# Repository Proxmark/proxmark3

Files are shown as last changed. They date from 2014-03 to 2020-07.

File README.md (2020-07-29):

# proxmark3: the official Proxmark repository!

The proxmark3 is a powerful general purpose RFID tool, the size of a deck
of cards, designed to snoop, listen and emulate everything from
**Low Frequency (125kHz)** to **High Frequency (13.56MHz)** tags.

This repository contains enough software, logic (for the FPGA), and design
documentation for the hardware that you could, at least in theory,
do something useful with a proxmark3.

## Resources

* [This repository!](https://github.com/Proxmark/proxmark3)
* [The Wiki](https://github.com/Proxmark/proxmark3/wiki)
* [The GitHub Pages website](http://proxmark.github.io/proxmark3/)
* [The Forum](http://www.proxmark.org/forum)
* The IRC channel: irc.freenode.org #proxmark3 ([chat in your browser](http://webchat.freenode.net/?channels=#proxmark3))
* [The Homebrew formula repository](https://github.com/Proxmark/homebrew-proxmark3)
* [Proxmark3 community discord server](https://discord.gg/86VcRtS)
   
## Development

The tools required to build  or run the project will vary depending on
your operating system. Please refer to [the wiki](https://github.com/Proxmark/proxmark3/wiki) for details.

## Obtaining hardware

The Proxmark3 is available for purchase (assembled and tested) from the
following locations:

| Distributor Name | Warehouse Location | Entity Location |
|---|---|---|
| [RyscCorp](https://proxmark3.com/) | USA | USA |
| [Hackerwarehouse](https://hackerwarehouse.com/)  | USA | USA |
| [Elechouse](http://www.elechouse.com/) | HK | HK |
| [Lab401](https://lab401.com/) | EU | HK |
| [RFxSecure](http://www.rfxsecure.com/) | CN | SG |
| [Sneaktechnology](https://www.sneaktechnology.com/)  | CN | CN |

Most of the ultra-low-volume contract assemblers could put
something like this together with a reasonable yield. A run of around
a dozen units is probably cost-effective. The BOM includes (possibly-
outdated) component pricing, and everything is available from Digikey
and the usual distributors.

If you've never assembled a modern circuit board by hand, then this is
not a good place to start. Some of the components (e.g. the crystals)
must not be assembled with a soldering iron, and require hot air.

The schematics are included; the component values given are not
necessarily correct for all situations, but it should be possible to do
nearly anything you would want with appropriate population options.

The printed circuit board artwork is also available, as Gerbers and an
Excellon drill file.

## License

This program is free software; you can redistribute it and/or modify
it under the terms of the GNU General Public License as published by
the Free Software Foundation; either version 2 of the License, or
(at your option) any later version.

This program is distributed in the hope that it will be useful,
but WITHOUT ANY WARRANTY; without even the implied warranty of
MERCHANTABILITY or FITNESS FOR A PARTICULAR PURPOSE.  See the
GNU General Public License for more details.

You should have received a copy of the GNU General Public License
along with this program; if not, write to the Free Software
Foundation, Inc., 51 Franklin St, Fifth Floor, Boston, MA  02110-1301  USA

Jonathan Westhues
user jwesthues, at host cq.cx

May 2007, Cambridge MA

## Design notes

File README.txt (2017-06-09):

NOTICE:
(2014-03-26)
This is now the official Proxmark repository!

INTRODUCTION:

The proxmark3 is a powerful general purpose RFID tool, the size of a deck
of cards, designed to snoop, listen and emulate everything from
Low Frequency (125kHz) to High Frequency (13.56MHz) tags.

This repository contains enough software, logic (for the FPGA), and design
documentation for the hardware that you could, at least in theory,
do something useful with a proxmark3.

RESOURCES:

   * This repository!
      https://github.com/Proxmark/proxmark3
      
   * The Wiki
      https://github.com/Proxmark/proxmark3/wiki
      
   * The GitHub page
      http://proxmark.github.io/proxmark3/
      
   * The Forum
      http://www.proxmark.org/forum
      
   * The IRC chanel
       irc.freenode.org #proxmark3
       -or-
       http://webchat.freenode.net/?channels=#proxmark3
       
   * The Homebrew formula repository
      https://github.com/Proxmark/homebrew-proxmark3
   
DEVELOPMENT:

The tools required to build  or run the project will vary depending on
your operating system. Please refer to the Wiki for details.

   * https://github.com/Proxmark/proxmark3/wiki

OBTAINING HARDWARE:

The Proxmark3 is available for purchase (assembled and tested) from the
following locations:

   * https://proxmark3.com/  - RyscCorp (us)
   * http://www.elechouse.com/  - Elechouse (HK)
   * https://lab401.com/ - Lab401 (FR)
   * http://www.rfxsecure.com/  - RFxSecure (SG)
   * http://proxmark3.tictail.com/ - IceSQL (SE)
   
Most of the ultra-low-volume contract assemblers could put
something like this together with a reasonable yield. A run of around
a dozen units is probably cost-effective. The BOM includes (possibly-
outdated) component pricing, and everything is available from Digikey
and the usual distributors.

If you've never assembled a modern circuit board by hand, then this is
not a good place to start. Some of the components (e.g. the crystals)
must not be assembled with a soldering iron, and require hot air.

The schematics are included; the component values given are not
necessarily correct for all situations, but it should be possible to do
nearly anything you would want with appropriate population options.

The printed circuit board artwork is also available, as Gerbers and an
Excellon drill file.

LICENSING:

This program is free software; you can redistribute it and/or modify
it under the terms of the GNU General Public License as published by
the Free Software Foundation; either version 2 of the License, or
(at your option) any later version.

This program is distributed in the hope that it will be useful,
but WITHOUT ANY WARRANTY; without even the implied warranty of
MERCHANTABILITY or FITNESS FOR A PARTICULAR PURPOSE.  See the
GNU General Public License for more details.

You should have received a copy of the GNU General Public License
along with this program; if not, write to the Free Software
Foundation, Inc., 51 Franklin St, Fifth Floor, Boston, MA  02110-1301  USA

Jonathan Westhues
user jwesthues, at host cq.cx

May 2007, Cambridge MA

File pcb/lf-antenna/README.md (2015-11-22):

LF antenna CAD / CAM / MFG files. Put here as it was in the original zip file too. Didn't modified the layout file, only CAM generation.

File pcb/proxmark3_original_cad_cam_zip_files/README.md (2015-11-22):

These files are downloaded from here: http://cq.cx/proxmark3.pl

These are the original, non-modified parts. 

What I've noticed that there are problems with the stop mask layers (via and component silkscreen print) This is what I'm going to modify in my cad / cam version.

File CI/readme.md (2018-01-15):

# How to configure continuous integration

Here 2 CI configuration files:

1. for [travis](travis-ci.org)
2. for [appveyor](appveyor.com)

It needs to put files from this directory to repository root and then configure CI from appropriate WEB portal.

## travis

- Copy .travis.yml and travis_test_commands.scr files to repository root 
- Configure CI from http://travis-ci.org
- It needs to fork https://github.com/Proxmark/homebrew-proxmark3 from your proxmark repository home
- Put to file `proxmark3.rb` in line `head "https://github.com/proxmark/proxmark3.git"` your repository link. As sample: `head "https://github.com/merlokk/proxmark3.git"`

## appveyor

- Just copy appveyor.yml file to root and configure it from http://appveyor.com

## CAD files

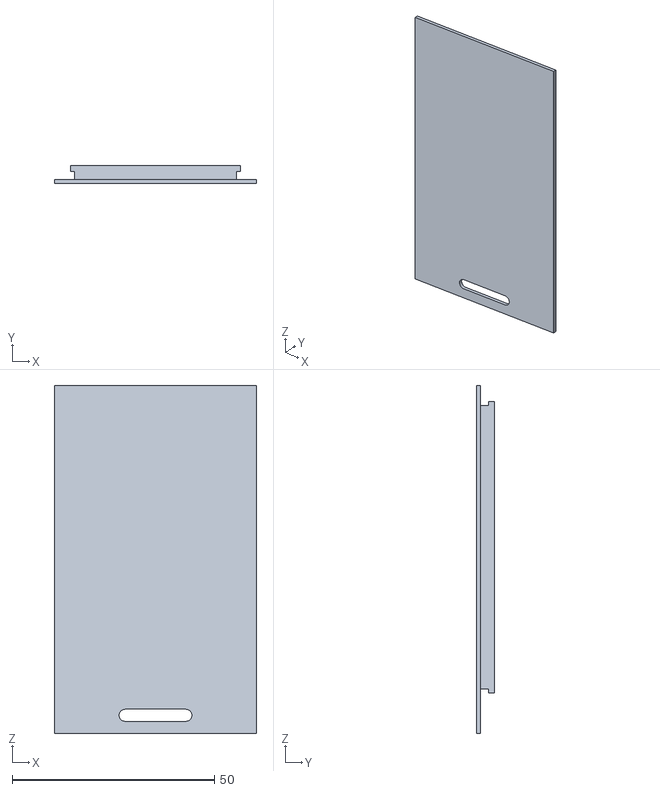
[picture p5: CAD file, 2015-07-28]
doc/RFID_Antenna-With-Lanyard-Hook.stl
50.0 x 4.50 x 86.0

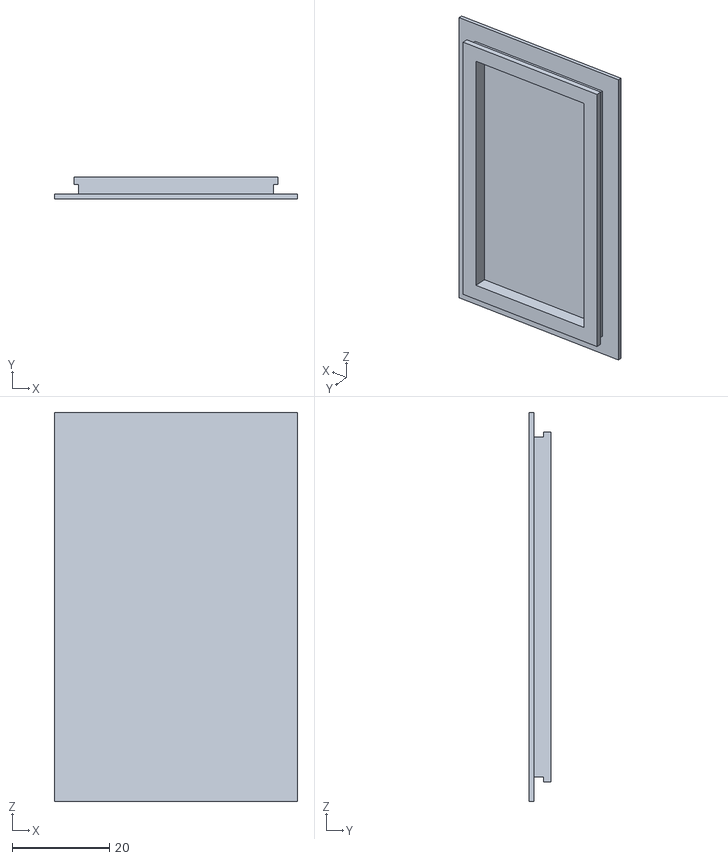
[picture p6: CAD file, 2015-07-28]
doc/RFID_Antenna-Basic-Form.stl
50.0 x 4.50 x 80.0

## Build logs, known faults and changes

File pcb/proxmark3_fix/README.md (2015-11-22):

Corrected Eagle layout files and re-generated CAM files. DRC checked (via eurocircuits.com 's PCB visualizer too) no problems found, ready to production!

Please find the change list in the CAD folder text file.

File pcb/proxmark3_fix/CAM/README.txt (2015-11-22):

project: proxmark3-00

    * please make 18 boards
    * panelize 3x1 (for total 6 panels)
    * 0.062" finished thickness
    * FR-4
    * solder mask top and bottom
    * silkscreen legend top
    * either 1 ounce or 0.5 ounce copper acceptable (1 ounce preferred)

Layer stackup:

Top layer: *.GTL
Inner Layer 1: *.GL1 (for 4-layer board)
Inner Layer 2: *.GL2 (for 4-layer board)
Bottom layer: *.GBL
Solder Stop Mask top: *.GTS
Solder Stop Mask Bottom: *.GBS
Silk Top: *.GTO
Silk Bottom: *.GBO
NC Drill: *.TXT
Outline layer: *.GKO or *.DO

Note:
 All the gerber files in RS-274x format, except the drill file in Excellon format. 

Ship to

<my shipping address>

<my email address>

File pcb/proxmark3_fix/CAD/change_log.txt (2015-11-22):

13/11/2015 Change list from original PCB:

Main problem: more then 800 DRC errors when runing that in Eagle. Check out the following changes to make a more reliable PCB. Those are minor cosmetic changes, but ease your life to avoid short circuit.

1. Eagle Layout / DRC rules / Masks / Limit: from 0mil to 16mil, thus ordinary GND and signal vias which smaller then 16mil wont be open at solder stop mask layer.

2. Eagle Layout / DRC rules / Masks / Stop MAX: from 2mil to 0, this way the solder stop mask wont overlap silkscreen drawings. Also as per PCB assembly houses, it's recommended, they set their own scaling for production.

3. Exporting all the parts in the proxmark3 Eagle Layout into a library for minor silkscreen edition: proxmark3_components  merged.lbr
	- Editing components footprint as was overlapping with top stop mask

4. Adding top, bottom, in1, in2 layer markings in PCB layout for better manufacturing identification	

5. Generating 4 layer CAM files

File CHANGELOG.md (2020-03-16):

# Change Log
All notable changes to this project will be documented in this file.
This project uses the changelog in accordance with [keepchangelog](http://keepachangelog.com/). Please use this to write notable changes, which is not the same as git commit log...

## [unreleased][unreleased]

### Changed
- Changed hf mfp security. Now it works in all the modes. (drHatson)
- `hf fido` - show/check DER certificate and signatures (Merlok)
- Changed `lf hitag reader 0x ... <firstPage> <tagmode>` - to select first page to read and tagmode (0=STANDARD, 1=ADVANCED, 2=FAST_ADVANCED)
- Accept hitagS con0 tags with memory bits set to 11 and handle like 2048 tag

### Fixed
- AC-Mode decoding for HitagS
- Wrong UID at HitagS simulation
- `hf 15 sim` now works as expected (piwi)
- `hf mf chk t` save to emulator memory now works as expected (mwalker)
- Fix `hf mf sim` - wrong access rights to write key B in trailer (@McEloff)
- allow files > 512Bytes in 'hf iclass eload' (@Sherhannn79)
- `hf mf nested` now works with fixed nonce tags too (uzlonewolf, piwi)
 
### Added
- Added to `hf 14a apdu` print apdu and compose apdu (@merlokk)
- Added `hf 15 csetuid` - set UID on ISO-15693 Magic tags (t0m4)
- Added `lf config s xxxx` option to allow skipping x samples before capture (marshmellow)
- Added `lf em 4x05protect` to support changing protection blocks on em4x05 chips (marshmellow)
- Support Standard Communication Mode in HITAG S
- Added `hf emv scan` - commands for scan EMV card and dump data to json file (Merlok)
- `hf mfp` group of commands (Merlok)
- Added `hf fido` - FIDO U2F authenticator commands https://fidoalliance.org/ (Merlok)
- Added `lf hitag reader 03` - read block (instead of pages) 
- Added `lf hitag reader 04` - read block (instead of pages) 
- Added `hf fido` `assert` and `make` commands from fido2 protocol (authenticatorMakeCredential and authenticatorGetAssertion) (Merlok)
- Added `lf paradox clone` to clone a Paradox card
- Added `emv` commands working for both contactless and smart cards (Merlok)
- Added `hf 15 snoop` (piwi)
- Added support for standard USB Smartcard Readers (piwi)
- Added `hf plot` (piwi)
- Added `hf mfp mad` `hf mf mad` parsing MAD1 and MAD2 (Merlok)
- Added `hf mfp ndef` `hf mf ndef` parsing NDEF records (Merlok)
- Added Mifare Mini, Mifare 2K and 4K support to `hf mf sim` (piwi)
- Added Legic detection to `hf search` (dnet)
- Added Home (Pos1) and End key bindings to the plot GUI (based on @mcd1992)
- Added downlink reference mode option r <mode> [ 0 - (or missing) default/fixed bit, 1 - long leading, 2 - leading 0 and 3 - 1 of 4 ] to `lf t55xx detect`, `lf t55xx read`, `lf t55xx write`, and `lf t55xx bruteforce`
- Added special option `r 4` to bruteforce, to try all downlink modes (0,1,2 and 3) for each password
- `hf mfu info` now checks the NXP Originality Signature if availabe (piwi)
- Added `hf mf personalize` to personalize the UID option of Mifare Classic EV1 cards (piwi)

## [v3.1.0][2018-10-10]

### Changed
- Adjusted `lf cmdread` to respond to client when complete and the client will then automatically call `data samples`
- Improved backdoor detection misbehaving magic s50/1k tag (Fl0-0)
- Deleted wipe functionality from `hf mf csetuid` (Merlok)
- Changed `hf mf nested` logic (Merlok)
- Added `hf mf nested` mode: autosearch keys for attack (from well known keys) (Merlok)
- `hf mf nested` Check keys after they have found (Merlok)
- `hf mf chk` Move main cycle to arm (Merlok)
- Changed proxmark command line parameter `flush` to `-f` or `-flush` (Merlok)
- Changed `hf 14a reader` to just request-anticolission-select sequence (Merlok)
- Changed `hf 14a raw` - works with LED's and some exchange logic (Merlok)
- Changed TLV parser messages to more convenient (Merlok)
- Rewritten Legic Prime reader (`hf legic reader`, `write` and `fill`) - it is using xcorrelation now (AntiCat)
- `hf 14a` commands works via argtable3 commandline parsing library (Merlok)
- HID LF operations on firmware updated for complete native support of long (>37 bit) HID tags (grauerfuchs)
- Changed Legic Prime tag simulator (`hf legic sim`) to run from 212 kHz SSP clock for better reliability (AntiCat)

### Fixed
- Changed start sequence in Qt mode (fix: short commands hangs main Qt thread) (Merlok)
- Changed driver file proxmark3.inf to support both old and new Product/Vendor IDs (piwi)
- Changed all command line parsers in `hf emv` commands to argtable (Merlok)
- Implemented AppNap API, fixing #283 and #627 OSX USB comm issues (AntiCat)

### Added
- Added `sc` smartcard (contact card) commands - reader, info, raw, upgrade, setclock, list (hardware version RDV4.0 only) must turn option on in makefile options (Willok, Iceman, marshmellow)
- Added a bitbang mode to `lf cmdread` if delay is 0 the cmd bits turn off and on the antenna with 0 and 1 respectively (marshmellow)
- Added PAC/Stanley detection to lf search (marshmellow)
- Added lf pac demod and lf pac read - extracts the raw blocks from a PAC/Stanley tag (marshmellow)
- Added hf mf c* commands compatibility for 4k and gen1b backdoor (Fl0-0)
- Added backdoor detection for gen1b magic s70/4k tag (Fl0-0)
- Added data fsktonrz, a fsk cleaning/demodulating routine for weak fsk signal. Note: follow this up with a `data rawdemod nr` to finish demoding your signal. (marshmellow)
- Added lf em 410xbrute, LF EM410x reader bruteforce attack by simulating UIDs from a file (Fl0-0)
- Added `hf mf cwipe` command. It wipes "magic Chinese" card. For 1a generation it uses card's "wipe" command. For gen1a and gen1b it uses a write command. (Merlok)
- Added to `hf mf nested` source key check before attack (Merlok)
- Added to `hf mf nested` after attack it checks all found keys on non-open sectors (Merlok)
- `hf mf chk` Added settings to set iso14443a operations timeout. default timeout set to 500us (Merlok)
- Added to `hf mf nested` parameters `s` and `ss` for checking slow cards (Merlok)
- Added to proxmark command line parameters `w` - wait 20s for serial port (Merlok)
- Added to proxmark command line parameters `c` and `l` - execute command and lua script from command line (Merlok)
- Added to proxmark ability to execute commands from stdin (pipe) (Merlok)
- Added `hf 14a info` and moved there functionality from `hf 14a reader` (Merlok)
- Added to `hf 14a info` detection of weak prng from Iceman1001 fork (Merlok)
- Added to `hf 14a apdu` - exchange apdu via iso1443-4 (Merlok)
- Added to `hf 14a apdu` - apdu and tlv results parser (Merlok)
- Added `hf emv` group of commands (Merlok)
- Added `hf emv search` `hf emv pse` - commands for selection of EMV application (Merlok)
- Added `hf emv select` - command for select EMV application (Merlok)
- Added `hf emv exec` - command for execute EMV transaction (Merlok)
- Added to `hf emv exec` MSD path for VISA and Mastercard and some other compatible EMV cards (Merlok)
- Added to `hf emv exec` SDA, DDA, fast DDA, CDA calculations for VISA and Mastercard and some other compatible EMV cards (Merlok)
- Added `hf emv test` - crypto tests for DES, AES, SHA, RSA, SDA, DDA, CDA and some other crypto functions (Merlok)
- Added `hf list mf` - deciphers crypto1 stream and works with first authentication and weak nested authentications (Merlok)
- Added to `hf emv` commands: `gpo`, `readrec`, `genac`, `challenge`, `intauth` - commands working with EMV cards (Merlok)
- Added `lf hid encode` and `lf hid decode` commands to translate printed HID card data to and from the packed data transmitted by a prox tag (grauerfuchs)
- Added `lf hid write` command, which operates as a macro for encode followed by clone operations (grauerfuchs)

## [3.0.1][2017-06-08]

### Fixed
- Compiles on OS X
- Compiles with gcc 4.9
- Compiles for non-Intel CPUs

## [3.0.0][2017-06-05]

### Added
- Added lf hitag write 24, the command writes a block to hitag2 tags in crypto mode (henjo)

### Added
- Added hf mf hardnested, an attack working for hardened Mifare cards (EV1, Mifare Plus SL1) where hf mf nested fails (piwi)
- Added experimental testmode write option for t55xx (danger) (marshmellow)
- Added t55xx p1detect to `lf search` chip detections (marshmellow)
- Added lf t55xx p1detect, detect page 1 of a t55xx tag based on E015 mfg code (marshmellow)
- Added lf noralsy demod, read, clone, sim commands (iceman)
- Added lf jablotron demod, read, clone, sim commands (iceman)
- Added lf nexwatch read   - reads a nexwatch tag from the antenna
- Added lf paradox read    - reads a paradox tag from the antenna
- Added lf fdx sim (iceman)
- Added lf fdx clone       - clones an fdx-b animal tag to t55x7 or q5 (iceman)
- Added lf fdx read        - reads a fdx-b tag from the antenna (iceman)
- Added lf gproxii read    - reads a gproxii tag from the antenna (marshmellow)
- Added lf indala read     - reads an indala tag from the antenna (marshmellow)
- Added lf visa2000 demod, read, clone, sim commands (iceman)
- Added markers in the graph around found Sequence Terminator after askmandemod.
- Added data mtrim <start> <stop> command to trim out samples between start and stop
- Added data setgraphmarkers <orange> <blue> command to set two extra markers on the graph (marshmellow)
- Added EM4x05/EM4x69 chip detection to lf search (marshmellow) 
- Added lf em 4x05dump command to read and output all the blocks of the chip (marshmellow)
- Added lf em 4x05info command to read and display information about the chip (marshmellow)
- Added lf cotag read, and added it to lf search (iceman)
- Added hitag2 read UID only and added that to lf search (marshmellow)
- Added lf pyramid commands (iceman)
- Added lf presco commands - some bits not fully understood... (iceman)
- Added experimental HitagS support (Oguzhan Cicek, Hendrik Schwartke, Ralf Spenneberg)
  see https://media.ccc.de/v/32c3-7166-sicherheit_von_125khz_transpondern_am_beispiel_hitag_s
  English video available
- Added a LF ASK Sequence Terminator detection option to the standard ask demod - and applied it to `lf search u`, `lf t55xx detect`, and `data rawdemod am s` (marshmellow)
- `lf t55xx bruteforce <start password> <end password> [i <*.dic>]` - Simple bruteforce attack to find password - (iceman and others)
- `lf viking clone`- clone viking tag to t55x7 or Q5 from 4byte hex ID input 
- `lf viking sim`  - sim full viking tag from 4byte hex ID input
- `lf viking read` - read viking tag and output ID
- `lf t55xx wipe`  - sets t55xx back to factory defaults
- Added viking demod to `lf search` (marshmellow)
- `lf viking demod` demod viking id tag from graphbuffer (marshmellow)
- `lf t55xx resetread` added reset then read command - should allow determining start of stream transmissions (marshmellow)
- `lf t55xx wakeup` added wake with password (AOR) to allow lf search or standard lf read after (iceman, marshmellow)
- `hf iclass managekeys` to save, load and manage iclass keys.  (adjusted most commands to accept a loaded key in memory) (marshmellow)
- `hf iclass readblk` to select, authenticate, and read 1 block from an iclass card (marshmellow)
- `hf iclass writeblk` to select, authenticate, and write 1 block to an iclass card (or picopass) (marshmellow + others)
- `hf iclass clone` to take a saved dump file and clone selected blocks to a new tag (marshmellow + others)
- `hf iclass calcnewkey` - to calculate the div_key change to change a key - (experimental) (marshmellow + others)
- `hf iclass encryptblk` - to encrypt a data block hex to prep for writing that block (marshmellow)
- ISO14443a stand-alone operation with ARM CFLAG="WITH_ISO14443a_StandAlone". This code can read & emulate two banks of 14a tag UIDs and write to "magic" cards  (Craig Young) 
- AWID26 command context added as 'lf awid' containing realtime demodulation as well as cloning/simulation based on tag numbers (Craig Young)
- Added 'hw status'. This command makes the ARM print out some runtime information. (holiman) 
- Added 'hw ping'. This command just sends a usb packets and checks if the pm3 is responsive. Can be used to abort certain operations which supports abort over usb. (holiman)
- Added `data hex2bin` and `data bin2hex` for command line conversion between binary and hexadecimal (holiman)
- Added 'hf snoop'. This command take digitalized signal from FPGA and put in BigBuffer. (pwpiwi + enio)
- Added Topaz (NFC type 1) protocol support ('hf topaz reader', 'hf list topaz', 'hf 14a raw -T', 'hf topaz snoop'). (piwi)
- Added option c to 'hf list' (mark CRC bytes) (piwi)

### Changed
- Adjusted the lf demods to auto align and set the grid for the graph plot. 
- `lf snoop` now automatically gets samples from the device
- `lf read` now accepts [#samples] as arg. && now automatically gets samples from the device
- adjusted lf t5 chip timings to use WaitUS. and adjusted the readblock timings
    appears to have more consistent results with more antennas.
- `lf t5 wakeup` has been adjusted to not need the p in front of the pwd arg.
- `data psknexwatchdemod` has been moved to `lf nexwatch demod` (reads from graphbuffer)
- `data fskparadoxdemod` has been moved to `lf paradox demod` (reads from graphbuffer)
- `data fdxdemod` has been moved to `lf fdx demod` (reads from graphbuffer)
- `data askgproxiidemod has been moved to `lf gproxii demod` (reads from graphbuffer)
- `lf indalaclone` has been moved to `lf indala clone`
- `lf indalademod` has been moved to `lf indala altdemod` (reads from graphbuffer)
- `data pskindalademod` has been moved to `lf indala demod` (reads from graphbuffer)
- `data askvikingdemod` has been moved to `lf viking demod` (reads from graphbuffer)
- `data fskpyramiddemod` has been moved to `lf pyramid demod` (reads from graphbuffer)
- `data fskiodemod` has been moved to `lf io demod` (reads from graphbuffer)
- `lf io fskdemod` has been renamed to `lf io read` (reads from antenna)
- `data fskawiddemod` has been moved to `lf awid demod` (reads from graphbuffer)
- `lf awid fskdemod` has been renamed to `lf awid read` (reads from antenna)
- `data fskhiddemod` has been moved to `lf hid demod` (reads from graphbuffer)
- `lf hid demod` has been renamed to `lf hid read` (reads from antenna)
- all em410x demod and print functions moved to cmdlfem4x.c
- `data askem410xdemod` has been moved to `lf em 410xdemod` (reads from graphbuffer)
- `lf em 410xdemod` has been renamed to `lf em 410xread` (reads from antenna)
- hf mf dump - added retry loops to try each read attempt up to 3 times.  makes getting a complete dump easier with many antennas. 
- small changes to lf psk and fsk demods to improve results when the trace begins with noise or the chip isn't broadcasting yet (marshmellow)
- NOTE CHANGED ALL `lf em4x em*` cmds to simpler `lf em ` - example: `lf em4x em410xdemod` is now `lf em 410xdemod`
- Renamed and rebuilt `lf em readword` && readwordpwd to `lf em 4x05readword` - it now demods and outputs the read block (marshmellow/iceman)
- Renamed and rebuilt `lf em writeword` && writewordpwd to `lf em 4x05writeword` - it now also reads validation output from the tag (marshmellow/iceman)
- Fixed bug in lf sim and continuous demods not turning off antenna when finished
- Fixed bug(s) in hf iclass write
- Fixed bug in lf biphase sim - `lf simask b` (and any tagtype that relies on it - gproxii...) (marshmellow)
- Fixed bug in lf viking clone/sim (iceman)
- Fixed broken `data askedgedetect` (marshmellow)
- Adjusted hf mf sim command (marshmellow)
    added auto run mfkey32 to extract all keys 
    also added f parameter to allow attacking with UIDs from a file (implies x and i parameters)
    also added e parameter to allow adding the extracted keys to emulator memory for the next simulation
    added 10 byte uid option
- Added `[l] <length>` option to data printdemodbuffer (marshmellow)
- Adjusted lf awid clone to optionally clone to Q5 tags (marshmellow)
- Adjusted lf t55xx detect to find Q5 tags (t5555) instead of just t55x7 (marshmellow)
- Adjusted all lf NRZ demods - works more accurately and consistently (as long as you have strong signal) (marshmellow)
- Adjusted lf pskindalademod to reduce false positive reads. (marshmellow)
- Small adjustments to psk, nrz, and ask clock detect routines - more reliable. (marshmellow)
- Adjusted lf em410x em410xsim to accept a clock argument (marshmellow)
- Adjusted lf t55xx dump to allow overriding the safety check and warning text (marshmellow)
- Adjusted lf t55xx write input variables (marshmellow)
- Adjusted lf t55xx read with password safety check and warning text and adjusted the input variables (marshmellow & iceman)
- Adjusted LF FSK demod to account for cross threshold fluctuations (898 count waves will adjust the 9 to 8 now...) more accurate. (marshmellow)
- Adjusted timings for t55xx commands.  more reliable now. (marshmellow & iceman)
- `lf cmdread` adjusted input methods and added help text (marshmellow & iceman)
- changed `lf config t <threshold>` to be 0 - 128 and will trigger on + or - threshold value (marshmellow) 
- `hf iclass dump` cli options - can now dump AA1 and AA2 with different keys in one run (does not go to multiple pages for the larger tags yet) (marshmellow)
- Revised workflow for StandAloneMode14a (Craig Young)
- EPA functions (`hf epa`) now support both ISO 14443-A and 14443-B cards (frederikmoellers)
- 'hw version' only talks to ARM at startup, after that the info is cached. (pwpiwi)
- Added `r` option to iclass functions - allows key to be provided in raw block 3/4 format 

## [2.2.0][2015-07-12]

### Changed
- Added `hf 14b raw -s` option to auto select a 14b std tag before raw command 
- Changed `hf 14b write` to `hf 14b sriwrite` as it only applied to sri tags (marshmellow)
- Added `hf 14b info` to `hf search` (marshmellow)
- Added compression of fpga config and data, *BOOTROM REFLASH REQUIRED* (piwi)
- Implemented better detection of mifare-tags that are not vulnerable to classic attacks (`hf mf mifare`, `hf mf nested`) (piwi)

### Added
- Add `hf 14b info` to find and print info about std 14b tags and sri tags (using 14b raw commands in the client)  (marshmellow)
- Add PACE replay functionality (frederikmoellers)

### Fixed 
- t55xx write timing (marshmellow)

## [2.1.0][2015-06-23]

### Changed
- Added ultralight/ntag tag type detection to `hf 14a read` (marshmellow)
- Improved ultralight dump command to auto detect tag type, take authentication, and dump full memory (or subset specified) of known tag types (iceman1001 / marshmellow)
- Combined ultralight read/write commands and added authentication (iceman1001)
- Improved LF manchester and biphase demodulation and ask clock detection especially for reads with heavy clipping. (marshmellow)
- Iclass read, `hf iclass read` now also reads tag config and prints configuration. (holiman)
- *bootrom* needs to be flashed, due to new address boundaries between os and fpga, after a size optimization (piwi)

### Fixed
- Fixed EM4x50 read/demod of the tags broadcasted memory blocks. 'lf em4x em4x50read' (not page read) (marshmellow)
- Fixed issue #19, problems with LF T55xx commands (iceman1001, marshmellow)
- Fixed various problems with iso14443b, issue #103 (piwi, marshmellow)

### Added
- Added `hf search` - currently tests for 14443a tags, iclass tags, and 15693 tags (marshmellow) 
- Added `hf mfu info` Ultralight/NTAG info command - reads tag configuration and info, allows authentication if needed (iceman1001, marshmellow)
- Added Mifare Ultralight C and Ultralight EV1/NTAG authentication. (iceman1001)
- Added changelog

## [2.0.0] - 2015-03-25
### Changed
- LF sim operations now abort when new commands arrive over the USB - not required to push the device button anymore.

### Fixed
- Mifare simulation, `hf mf sim` (was broken a long time) (pwpiwi)
- Major improvements in LF area and data operations. (marshmellow, iceman1001)
- Issues regarding LF simulation (pwpiwi)

### Added
- iClass functionality: full simulation of iclass tags, so tags can be simulated with data (not only CSN). Not yet support for write/update, but readers don't seem to enforce update. (holiman).
- iClass decryption. Proxmark can now decrypt data on an iclass tag, but requires you to have the HID decryption key locally on your computer, as this is not bundled with the sourcecode.

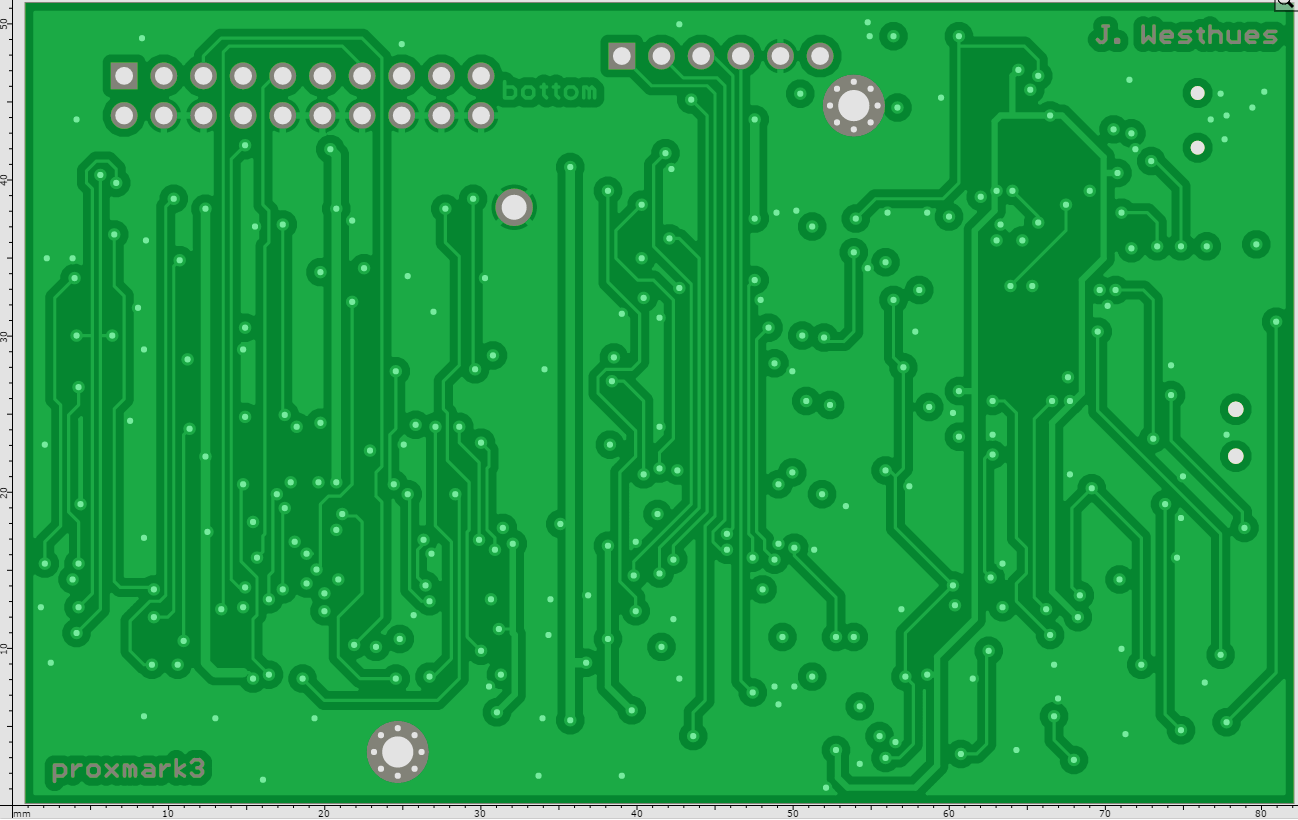
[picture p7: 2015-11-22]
pcb/proxmark3_fix/BOT_layer_preview.png

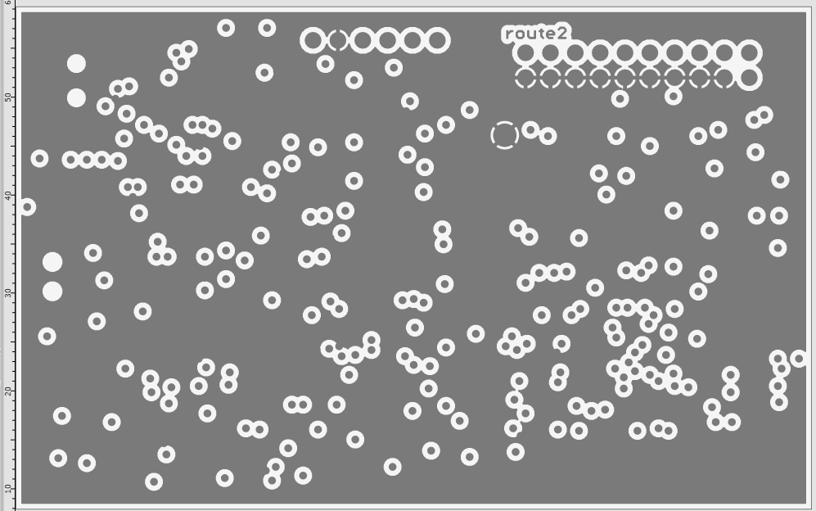
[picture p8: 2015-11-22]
pcb/proxmark3_fix/IN1_layer_preview.png

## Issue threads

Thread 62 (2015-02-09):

Reworking how the graphing functions

holiman, 2015-02-09:
I am currently rewriting the graph framework. I want to provide a better UI for experimenting with signals.

Here's how it looks right now:
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

What you can't see here, is that if you pull the slider to the left (increasing 'window'), the red graph updates in real time. The same thing with dir threshold:

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

Once you're happy with the settings, you can press apply, and the red signal is copied into the main signal buffer (graphbuffer):
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

This does not really affect the console-commands, they work as usual. I've had to restructure them a bit though; e.g. dirthreshold and autocorr look like this:

```
int CmdDirectionalThreshold(const char *Cmd)
{
    int8_t upThres = param_get8(Cmd, 0);
    int8_t downThres = param_get8(Cmd, 1);

    printf("Applying Up Threshold: %d, Down Threshold: %d\n", upThres, downThres);

    directionalThreshold(GraphBuffer, GraphBuffer,GraphTraceLen, upThres, downThres);
    RepaintGraphWindow();
    return 0;
}
```

That is, they parse the commands, then call an "api"-function which does the actual data operation. These data-operations all have the signature (const int\* in, const int*out, size_t len, ... parameters..). That is, they take one read-buffer and one write-buffer. In the console-case, in and out are the same.

I think there are probably a few more things which could fit into this (changes from analog -> analog which depends on parameters which the user may want to fiddle with).
So that's for analog signals -> analog signals.

I have some thoughts on also doing another UI for functions which map analog->digital, i.e; decoders. The UI would show the digital out, represented both in bitstream-form, and hex-form (in four ways, shifted one bit each), and perhaps ascii form. Perhaps highlighting potential parity bits. And then the user could slide stuff like clock or starting point or whatever, and in real time see what makes the most sense.

This is still work in progress, but if anyone wants to tag along, feel free.

And I do think we're approaching a major version number increase soon.

holiman, 2015-02-09:
Oh, the "Sticky" button was supposed to just snapshot the red signal (turn it grey), so the user could fiddle on with other signals and it would remain. I haven't implemented it, as it's a bit finicky to dynamically keep track of the number of signal buffers, and I'm not sure it's worth it. The usecase may not be that relevant.

iceman1001, 2015-02-10:
I really like this idea of yours.  This will be such an enchancement to the Pm3.

When it comes to the  Analog -> Digital,  the new remade api from @marshmellow42  will come in hand.
To be able to switch between different decoders real time.

And I also agree with the major version number increase.  A new release (v2.0.0) maybe?

holiman, 2015-04-08:
I've put this on hold a bit, I'll take another stab once the LF-parts stabilize from the major overhauls that @marshmellow42 is doing...

marshmellow42, 2017-04-12:
taking this where holiman left off and adjusting it a bit to include the demod yields:
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
still working out some bugs.  if anyone knows QT Designer well assistance would be welcomed!

pwpiwi, 2017-04-12:
I was already wondering when you finally would arrive here. :grin:

marshmellow42, 2017-04-12:
Heh, every demod needs adjusting...  And I have no clue how to work QT..  but I might as well learn...

marshmellow42, 2017-04-12:
It is up on my fork in the graphwork branch.  Should I attempt to merge it into the Master's graphwork branch?  Too many bugs for the master at this point...

marshmellow42, 2017-04-12:
It currently should work with all data rawdemod cmds...  Working on the rest still.

marshmellow42, 2017-04-13:
I reused holimans code from that branch as a starting point.  There are a few bugs in his code (like you couldn't reopen the plot window if you closed it) and now a few in my additions that I'm trying to work out (like the main app is unable to close the overlays form when it exits).

pwpiwi, 2017-04-13:
Then I would agree to your proposal and merge to proxmark3/graphwork first. Even without bugs it will be difficult enough to merge with master later.

marshmellow42, 2017-04-13:
that branch is so old, can i just blow it away and pull in my new code (it contains all holiman's code with new updates to work with current master)?

pwpiwi, 2017-04-13:
Sure. I didn't think that you are closer to master than holiman's graphwork.

marshmellow42, 2017-04-13:
for now i created a graphwork2 branch and merged my fork/branch into it.  (it is current with master + graph stuff)
i'm struggling to identify why it won't quit the overlays form when the proxmark application closes... (it hangs instead)  any help would be appreciated!

iceman1001, 2017-04-13:
Its just as well to drop the old graphwork branch and take marshmellows as basis for a new one.

QT is another language to learn,  but is there some other UI dev we can use instead of it?  It needs to crosscompile..  I guess thats why its QT,.   Are there some QT IDE?

marshmellow42, 2017-04-13:
I agree, but I left the old one for now to still compare and see if I missed something causing the hang issue...  Once that bug is fixed I will delete it

iceman1001, 2017-04-13:
I think you will need to get a way of getting the active qt-window-handles,  and kill them before pm3 client exits.  QT must have a way of getting refs to window handles.   Maybe we need to save them in an array, when created.  Which we can use to close each handle at the end, if they exists.

marshmellow42, 2017-04-13:
i think all qt windows should close when the `plotapp->quit();` is called

iceman1001, 2017-04-13:
well,  does it?  or does your trials show that it hangs?

marshmellow42, 2017-04-13:
that is the thing, it appears to work on the old branch but not my new one...

iceman1001, 2017-04-13:
I got hangs on Holimans old code too.  Dont use his unfinished code as baseline for yours.

pwpiwi, 2017-04-14:
> i think all qt windows should close when the `plotapp->quit();` is called

This is what I would expect as well. The issue could be related to issue #275.

pwpiwi, 2017-04-14:
> I got hangs on Holimans old coide too. Dont use his unfinished code as baseline for yours.

Why not? This is what we do since years. :smile:

marshmellow42, 2017-04-14:
i believe i have fixed the issues. ? maybe?   to be tested on other platforms...

marshmellow42, 2017-04-14:
i just need to figure out how to add uic ui/overlays.ui > ui/ui_overlays.h to the makefile and it will compile and work on kali/other qt versions as well.

marshmellow42, 2017-04-14:
still have a segmentation fault error after exit.  (but that existed before i think...)

marshmellow42, 2017-04-14:
i tried to add the ui_overlays.h uic to the make file and it compiles on windows, but doesn't on kali.  it appears it doesn't happen soon enough as it complains the file doesn't exist yet.  what did i miss?

pwpiwi, 2017-04-15:
Cannot confirm. Compiles fine on my Kali. Do you have Qt4 or Qt5 with Kali?

marshmellow42, 2017-04-15:
Qt 4.  Strange.   I'll do some more testing

pwpiwi, 2017-04-15:
Qt4 doesn't have a separate QtWidgets module. Use QtGui instead of QtWidgets in the #includes.
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
holiman, 2017-04-15:
Hey all!

Nice to see the activity on proxmark! I haven't kept up to date, but check in from time to time. Regarding the graphing, I find qt designer to be quite easy to use, and used qt creator as a general purpose c IDE for coding proxmark stuff on. I may be able to help out with qt designer stuff.

Regarding segfaults and hangs, you need to prevent QT from gc:ing your windows / components, which you do by maintaining references. Put them in a member or vector or something, but put them somewhere, otherwise bad things happen.

The big problem with graphing, as I recall it, is that it's difficult to make a 'general' input dialog for various parameters that you may want to fiddle with. However, it's easier to make the console still being the input, and the graph is just for show. But then you miss the nice thing which is to turn a knob or drag a dial and see the output change immediately. So the best would be to generate inputs based on the number of parameters.

Which branch contains the relevant code for graphing right now?

marshmellow42, 2017-04-15:
graphwork2 is the current working branch.  i think we are very close to being ready to merge it with the master.  have a look and fix any of my mistakes ;)

marshmellow42, 2017-04-15:
i was about to remove graphwork with your permission.

marshmellow42, 2017-04-15:
the biggest changes i made were:
any lf demod will apply a blue demod line over the graph where the demod data was obtained (along with the binary output in blue between the lines)

on the overlays form:
I removed askdemod tab and added askedge detection.
i adjusted the "Sticky" button to be "Restore" to undo any operation on the graph.

i adjusted some qt code to allow hiding and showing the graph and overlays form from the pm3 client data commands.

and i think i fixed the errors given when the client tried to exit when the overlays form was shown.

there is still a segment fault error when the client exits but that may be unrelated to the new code. (preexisting?)

marshmellow42, 2017-04-15:
i also found for qt version compatibility that the ui_overlays.h has to be either made by uic during the make  or has to be built on QT4 and manually adjusted to remove the `QtGui/` in front of the #includes and remove all occurrences of `, QApplication::UnicodeUTF8`. (QT4 only)

marshmellow42, 2017-04-15:
can you build the pm3 code from within Qt Creator?

marshmellow42, 2017-04-16:
found a couple grid bugs and patched...

was thinking we should add a button to toggle overlays on and off

holiman, 2017-04-16:
> i was about to remove graphwork with your permission.

I won't mind, I've been away too long to have objections :)

> i adjusted the "Sticky" button to be "Restore" to undo any operation on the graph.

Regarding 'sticky' versus 'restore', my idea was that you would fiddle knobs until it looks good, and then 'lock in' on that, and go to the next operation, and do the same thing again. So you could go from a noisy signal, to a digital signal, to a decoded signal.

If you do the instant-wipe, you'll lose the original signal each time you fiddle the knob, and if you have a slider with 10 steps, that you slide up 1,2,3, then you will go through the graphs
`f(signal,1), f( f(signal,1),2) , f( f( f(signal,1),2),3) ` instead of `f(1,signal), f(2,signal), f(3,signal)`

But maybe I misread you. The 'revert'-version works well with commandline, but I think less well from a graphical UI perspective.

> can you build the pm3 code from within Qt Creator?

I never did, no. I like QT creator, but not the build-system that keeps trying to overwrite the makefiles and whatnot.

marshmellow42, 2017-04-17:
Regarding the sticky, I'd agree with that model.  but we need more commands made and included to make that useful.

For now I think being able to visualize what a commands setting will do then applying what looks good, and being able to run a demod cmd from the client (for now) and see the results on the graph and if it failed be able to go back and try again, is a fair starting point.

It would be nice if we had various filters we could apply to really clean up the wave.

marshmellow42, 2017-04-19:
you can learn a lot with pictures and the new graph could help many learn simple modulation demodulation.
psk1 trace demodulated with client commands and graphed
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
and ask with askedge (red) overlaid and client demod (em410x) overlaid:
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
(ask edge slider setting):
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

iceman1001, 2017-04-19:
This is an huge step forward for PM3 users! It will be great learning tool and I belive a start for something new. Great work @marshmellow42.

Closed 2017-04-19.

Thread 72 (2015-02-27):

LF Sim Timing issues

marshmellow42, 2015-02-27:
I've been testing the LF sim functions to see why they are so erratic as to their functionality.
I believe it comes down to the use of the clock in SimulateTagLowFrequency.
could someone explain what GPIO_SSC_CLK measures?

let me illustrate the issue:
a standard HID FSK2a tag should have waves 10 samples and 8 samples long depending on whether it is bit 1 or bit 0.  so digitally it should be 1111100000 and 11110000.

if this is sent through the SimulateTagLowFrequncy the output has 2 errors.
1. the number of samples have lengthened to 11111110000000 and 11111000000
    so our clock is too slow
2. if you compensate for by reducing the bits sent to the function then the second issue becomes obvious: the transition between bit 1s and bit 0s creates extra 0 waves.
   So going from 1111000011110000 to 1111100000 translates 11110000001111100000 (added 2 extra 0 bits)

img1: bad timing:
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

img2: bad transition:
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

any thoughts?

I can get ASK clocks of 32 or greater to work fine but the lower the clock the worse this affects things.

holiman, 2015-02-27:
I investigated LF Sim a bit in depth a while ago, and my conclusion was the following...
We don't use any on-board clock for timing, instead we rely on the clock from the reader (the carrier signal), which we get from via the `GPIO_SSC_CLK` (iirc). I believe there's some documentation on the forum somewhere about my investigation on that.

Could you elaborate on what you did to get the images above? Are you using two pm3:s ?
Maybe someone ought to look through the FPGA parts where GPIO_SSC_CLK is generated from the carrier.

marshmellow42, 2015-02-27:
my guess is we need to use a different clock calculation. (possibly instead of bit-bang, modulate or demodulate for x clock periods for each wave, where x is 1/2 the given wave length)

unfortunately I'm very new to the clocks and their uses.

marshmellow42, 2015-02-27:
i'm using 2 PM3's one to sim one to read.

marshmellow42, 2015-02-27:
maybe I should snoop the sim to a real reader...  I can look at that.

holiman, 2015-02-27:
[Here](http://www.proxmark.org/forum/viewtopic.php?pid=12832#p12832)'s the forum thread where I looked into it

marshmellow42, 2015-02-27:
I just re-read the info, and I do believe we need an internal clock, or I suppose fix the carrier clock detection.  can we re-use some of the info used for hitag?

holiman, 2015-02-27:
We should use the carrier clock, as that one kind of per definition is correct - it's the clock the reader expects, whether it's correct according to NIST standards or not...

marshmellow42, 2015-02-27:
i'm attempting to learn.  ;)   as I said above I can hack it and get ASK to work above RF/16 clocks.
(so for EM410x tags i'm good.)  but I don't like the hack and it isn't good for the repo.  but PSK and FSK are hit and miss, usually miss.
I'll keep digging.

holiman, 2015-02-28:
I can try to capture some traces, with a rfidler generating a 125khz wave, and measuring the ssp_clk from the FPGA debug output, with the pm3 in LF simulation-mode (but not modulating)g. If I use a DSO to measure the carrier wave and the FPGA output, it would be possible to see if the FPGA somehow misses a step in the carrier sometimes or if the error is somewhere else.

marshmellow42, 2015-02-28:
I cannot prove it yet, but it appears to mainly happen during a modulation transition.  When it switches high to low or low to high.  So I'm not sure you will see something.  But it is a very good test to verify it is working as it should when not modulating so we can rule that out.

marshmellow42, 2015-03-02:
ok so here is something.  using 2 antennas - the one from proxmark3.com who's hw tune is:
# LF antenna: 14.16 V @   125.00 kHz
# LF antenna: 27.91 V @   134.00 kHz
# LF optimal: 30.11 V @   131.87 kHz

and another I built who's hw tune is:
# LF antenna: 45.79 V @   125.00 kHz
# LF antenna: 25.02 V @   134.00 kHz
# LF optimal: 45.79 V @   125.00 kHz

if I run my new sim commands (from my fork) with the weaker antenna I get this result:
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

or 111100000 and 1110000 instead of 1111100000 and 11110000.

if I run the same command with the stronger antenna I get this result:
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

or 1111100000 and 111100000 instead of 1111100000 and 11110000.

I've attempted to adjust the input data to get a steady 1111100000 11110000 but have failed so far.
sometimes different distances between the antennas will affect the output but it then becomes erratic.  with
NOTE the above images were obtained with a second PM3 in snoop mode listening to the first PM3 attempting to sim to a reader.  though they actually look the same if I were just to read with the second PM3.

marshmellow42, 2015-03-02:
I think I may have fixed the bit transition issue noted in my first post.  it appears a true tags wave begins low 00001111 and 0000011111, so I flipped them (in my fork).
This and adding a small wave every 4 0 bits (to fix the clock shift when the clock is 50 and fc is 8) seems to make the wave more like a cards wave.

but we still have the timing issues.

now maybe a 25V antenna works perfectly... ???  but too strong or too weak and your stuck?

marshmellow42, 2015-03-02:
just thought I'd explain what I experimented with to get ask simulation working somewhat:

to simulate EM41xx ask/man tags I built a new function SimulateTagLowFrequencyMM.  the only change that really made a difference was to test if we just transitioned from a high to low or from low to high and then skip the "wait for reader carrier to go low" loop.

it appears to me when we are transitioning, either the modulating of the coil takes too long and we miss the carrier low, or it interferes with reading the carrier low.  (or it has nothing to do with that and it just effectively removes 2 samples per wave that we somehow picked up by mistake)
(note very small waves (rf/16 and below) pick up more extra samples)

this gets lf simask working above rf/16 clock rates.  but this is a band-aide and does not really address the clock issue.

marshmellow42, 2015-03-02:
http://www.proxmark.org/forum/viewtopic.php?pid=2670#p2670 does this still apply to our clock?

marshmellow42, 2015-03-03:
based on this: http://www.proxmark.org/forum/viewtopic.php?pid=6021#p6021
I flashed my proxmark back to R582 and the HID sim functions great as the poster mentions.  antenna doesn't matter.
i'm going to attempt to try additional versions to see if a more recent version works so as to isolate when it was destroyed.  I have a feeling it was either when we went to lo_edge_detect.v instead of lo_simulate.v or when the izsh added the wave cleaning.
BTW, on github how do I get a download of the code at a moment in time?  (googlecode had versions)

marshmellow42, 2015-03-03:
NOTE: wave from R582 (FSK Sim works well):
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
(read from second PM3)

marshmellow42, 2015-03-03:
it appears the issues where there prior to the break out of LF and HF fpga code, (and the wave cleaning).  I loaded code from 6/17/2014 before the FPGA split,(fpga from 2/25/2014) and the "extra" samples per wave were there.
how hard would it be to implement a "new" mode that uses lf_simulate.v and not lo_edge_detect.v?
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
marshmellow42, 2015-03-05:
while we are on the subject of powering the lf antenna, I was looking at the NRZ/Direct modulation.  it appears to normally stay half modulated and modulate full or off to indicate a bit.  is there anyway we can support this?

iceman1001, 2015-03-05:
Where is all this information of the inner workings of the fpga and its use with the pm3?  Can someone make a write-up?  With technical details or system documentation?  I don't read verilog, so this would help my understanding a lot.

pwpiwi, 2015-03-06:
@iceman: depends what you mean with "inner workings". Its a programmable device and Its function is determined by the verilog sources. Together with the PM3 schematic this is the only documentation available. However, if you are interested in the FPGA inner structure then google for the datasheet (Xilinx DS001 Spartan II).
Regarding Verilog: The operators and control structures are very similar to programming languages. But you need to keep in mind that Verilog describes Hardware. In hardware everything happens in parallel and "at once" (give or take a few nanoseconds). If you need something to happen sequentially you need to explicitely specify a "storage" (registers, flip flops) and a corresponding clock signal. And of course you need to know the basics about logic gates, registers, latches, adders with/without carry, RAMs, etc.

@marshmellow42: Do you have a reference (link) to the NRZ/direct modulation you are looking for?

holiman, 2015-03-06:
@iceman ; I didn't have a clue about how Verilog functions a few months back. But it's fairly simple to read some tutorials and pick it up. The main concepts could be explained in a page or two, so it's pretty easy to reach the level of being able to comprehend written code - a bit more to write it yourself.

But coming from a software background, I also have difficulties understanding the hardware portions, and the boundaries between hardware and software. I've not looked at the pm3 schematic. @pwpiwi - what free/opensource tools would you recommend to view and make sense of the schematics?

holiman, 2015-03-06:
oh, and perhaps you haven't notived. But after I fixed iclass full simulation, I tagged a version 2.0.0-rc1. With this fix in place, I tagged it as 2.0.0-rc2. Anything else we want included in 2.0.0-final?

iceman1001, 2015-03-06:
@holiman    For me, the hardware connections into the software is just "automagic". I'm totally lost there. My idea was to start understanding it but it seems like I need dev environment for Verilog too..

regarding the rc2,  I suggest you get the new stuff from @marshmellow42 into it.

@pwpiwi  Your extended knowledge over the software borders to the hardware side, gives you a more complete picture than I ever can get from just looking at the software side.

pwpiwi, 2015-03-06:
I meant the schematics in doc/proxmark3_schema.pdf. I am recommending Adobe Reader to view and make sense of the schematics :grinning:.

holiman, 2015-03-06:
For verilog *compilation*, yes you need a dev env. I use an old win xp virtual machine setup for the purpose, but all I do withini it is copy the code from linux to windows, run go.bat, copy back (via shared folders). For experimentation with verilog, you can use some open source tools. Or just do it the hard way, modify via editors, generate an FPGA-image, flash, test. Works well for small things, like this one here.

marshmellow42, 2015-03-06:
@holiman for tagging I'd like to finish my Sim commands and see if I can finish the patch to em410x Sim.  I will test psk Sim later today.  And might be ready for a pull after that.

@piwi, for NRZ/Direct the best I have is the traces in the traces folder and my experimenting with the ata5577 chip.  I know how to demod it, and have built a demod function for it.  I've only ever seen one tag from an unknown system use it.

marshmellow42, 2015-03-06:
I've finished the sim commands i can build (missing NRZ/Direct), as well as a few fixes - including for the em410xsim and lf sim.
i've created the pull request.  i hope this doesn't step too much on your graphing changes that are coming @holiman :(

pwpiwi, 2015-03-08:
> Anything else we want included in 2.0.0-final?

I have another FPGA bugfix in hi_iso14443.v in testing and will commit on Monday morning. Together with @marshmellow42's last fixes this should go into 2.0.0-final. And I might commit the fix for issue #73 on Monday evening...

pwpiwi, 2015-03-09:
Couldn't continue with testing yesterday. @holiman: up to you to decide when you want to do the "final" tagging. I personally don't care if these fixes go to 2.0.0.-final or the next release. I am quite sure that these won't be the last fixes anyway...

pwpiwi, 2015-03-09:
Pushed two commits.

Closed 2015-03-06.

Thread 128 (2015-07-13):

14b RAW - accessing the iso7816 layer on a 14b tag.

iceman1001, 2015-07-13:
[using the latest code from github and my fork :) ]

14b RAW - accessing the iso7816 layer on a 14b tag.
I can get the tag to be selected and get it into a active state where it listens to iso7816 apdu frames.
If I send a correct apdu,  it doesn't block&resets and I can re-run correct apdus over and over.
But I never get the answer from the tag.  e.g. 90 00,   I have printed debugs to see if it is the uart/demod but no. I tried increasing the timeout from 2000  to 200000.  Nada.  The demod never get anything in...  its like the FPGA doesn't pick up the signal.
--relevant fpga code would be in regard to these modes:
FPGA_MAJOR_MODE_HF_READER_RX_XCORR | FPGA_HF_READER_RX_XCORR_848_KHZ
@pwpiwi  help!

-- as seen below,  the select is working, but no answer to the apdu is received.
pm3 --> hf 14b raw -c -p -s 02 94 a4 00 00 00
REQB   : 50 26 58 4B 0C 00 00 00 00
ATTRIB : 00 78 F0
#db# max behindby = 3, samples = 262144, gotFrame = 0, Demod.len = 0, Demod.sumI = 1, Demod.sumQ = 1
received 0 octets

pwpiwi, 2015-07-13:
Can we please see the rest of the response to REQB? It is truncated to 9 bytes.

iceman1001, 2015-07-13:
here you go.
pm3 --> hf 14b raw -c -p 05 00 08
received 14 octets
[LEN 14] 50 26 58 4B 0C 00 00 00 00 00 71 81 [CA D7] OK

pwpiwi, 2015-07-14:
Thanks. I just wanted to check if the card supports iso14443-4 (it does) and if the timeout is enough (it is).

But I am not sure if your command is correct.
02 would be the iso14443-4 PCB with a block number of 0, no CID, no NAD. That looks good.
94 a4 00 00 00 would then be the apdu with 94 being the CLA byte, which would be a proprietary (non ISO7816) one. Probably not what you intended?
a4 00 00 would then be a SELECT command with parameters P1=0 and P2=0
And the last 00 is superfluous?

I think that your card simply doesn't understand the command and therefore doesn't respond (there is no NACK in this case).

btw: in your `TransmitFor14443B()` are some additional code lines which I don't understand. Merge conflicts ????

iceman1001, 2015-07-14:
The CLA 0x94, is very intended. Navigo has a propritary command.
The command is taken from the  https://github.com/pterjan/cardpeek-navigo  project,  which can read Navigo cards,  and I tried several versions of the command.
The last 0x00, is for saying the len of added bytes is zero,  also in the standard.
Its a bare APDU,  which should get at least a NACK back.

-If you are talking about the spindelay in "TransmittFor14443B()", its for letting the tag to get some time to powerup before sending the first time.

-If you are talking about the StartCountSspClk( in "TransmittFor14443B()",  I saw the EPA changes had this one in its setup, https://github.com/Proxmark/proxmark3/blob/master/armsrc/iso14443b.c#L989  and thought I could test it too.

pwpiwi, 2015-07-14:
A length byte of 0x00 starts an extended length and two more bytes would be expected. Length 0 is declared by omitting the length byte.

iceman1001, 2015-07-14:
according to iso7816,  the master/slave setup means that the slave (ie tag) must answer to a apdu no matter what. If the apdu is formatted wrong, it should always answer.  So I'm not buying your idea of a wrong apdu is making the tag not-repsonding.

And, I got a snoop,  from cardpeek and tag.
http://www.proxmark.org/forum/viewtopic.php?pid=17159#p17159

pwpiwi, 2015-07-15:
Did you try the command similar to the snoop? (hf 14b raw -c -p -s  02 94 a4 00 00 02 20 00 00)

iceman1001, 2015-07-15:
yes I did,  and I guess the last 0x00 is the expected response len.. But that doesnt match the snoop response..    however, the following up answer to your question is I didn't get a response from the tag.

iceman1001, 2015-07-15:
well,  the user who took the snoop tried and run against his tag.
And he got an answer (after reqb, attrib)  to the command: hf 14b raw -c -p 02 94 a4 00 00 02 20 00 00
wrong crc to it, but at least an answer...

So question is now,  whats wrong with my tag...

buggii, 2015-07-15:
Can it be a "disabled" (killed) tag? With iso15693 it is possible but tag will never answer back anymore... maybe it really need an auth of some kind?

Inviata dal mio dispositivo Android.

-----Original Message-----
From: Iceman <notifications@github.com>
To: Proxmark/proxmark3 <proxmark3@noreply.github.com>
Sent: Mer, 15 Lug 2015 20:39
Subject: Re: [proxmark3] 14b RAW - accessing the iso7816 layer on a 14b tag. (#128)

well,  the user who took the snoop tried and run against his tag.
And he got an answer (after reqb, attrib)  to the command: hf 14b raw -c -p 02 94 a4 00 00 02 20 00 00
wrong crc to it, but at least an answer...

So question is now,  whats wrong with my tag...

---
Reply to this email directly or view it on GitHub:
https://github.com/Proxmark/proxmark3/issues/128#issuecomment-121708114

iceman1001, 2015-07-15:
As it looks like at the moment then that could be the case here with my tag...

iceman1001, 2015-07-16:
Not a killed tag... but a brand new one,   without a subscription on it.
This would explain why the tag doesn't answer to the AID "20 00" application directory..  It might not be there.  But it doesn't explain why the tag doesn't follow iso7816 standard...

iceman1001, 2015-07-16:
@pwpiwi  I tried a another sqrt[ci^2 + cq^2),  which works better for my setup. Don't know if it takes  too long time to execute.  You see it below.  Feedback what you think about it would be nice.

My question is your "MAKE SOF DECISION",  what does it do?

// The soft decision on the bit uses an estimate of just the
// quadrant of the reference angle, not the exact angle.
#define MAKE_SOFT_DECISION() { \
		v = (Demod.sumI > 0) ? ci : -ci;\
		if(Demod.sumQ > 0) { \
			v += cq; \
		} else { \
			v -= cq; \
		} \
	}

#define SUBCARRIER_DETECT_THRESHOLD	8

// Subcarrier amplitude v = sqrt(ci^2 + cq^2), approximated here by max(abs(ci),abs(cq)) + 1/2*min(abs(ci),abs(cq)))
#define CHECK_FOR_SUBCARRIER() { \
		ai = (abs(ci) >> 1); \
		aq = (abs(cq) >> 1); \
		v = MAX(abs(ci), abs(cq)) + MIN(ai, aq); \
}

pwpiwi, 2015-07-16:
Well, this version of `CHECK_FOR_SUBCARRIER()`  gives the same result doesn't it? Why should it then work better?

I would agree that it is easier to comprehend, but it is slower. I don't know if it is too slow.

I had a hard time to understand `MAKE_SOFT_DECISION()` as well, but it indeed makes what it says: it checks if the vector (cq, ci) is in the same quadrant (+/- 45°)  as the training vector (sumQ, sumI). If yes, then v > 0. Take a sheet of paper with a coordinate system and try some examples...

iceman1001, 2015-07-17:
Don't know if it gives the same result, since this one works better for me.  I can get @marshmellow42  "-s" to work, which wasn't before.

iceman1001, 2015-07-18:
OK, seems neat,  however not consistent.

if yes,  v > 0
if no,  v <= 0

               v, sumi, sumq, ci, cq
#db# ICE: 47 752 -13 43 -4
#db# ICE: -40 752 -13 -40 0
#db# ICE: 44 -648 -6 -44 0
#db# ICE: 41 -648 -6 -41 0
#db# ICE: 41 -648 -6 -40 -1
#db# ICE: 41 -648 -6 -41 0
#db# ICE: 41 -648 -6 -41 0
#db# ICE: 40 -648 -6 -40 0
#db# ICE: 41 -648 -6 -41 0
#db# ICE: 40 -648 -6 -40 0
#db# ICE: 41 -648 -6 -41 0
#db# ICE: 40 -648 -6 -40 0
#db# ICE: 41 -648 -6 -41 0
#db# ICE: 40 -648 -6 -40 0
#db# ICE: 42 -648 -6 -41 -1
#db# ICE: 40 -648 -6 -40 0
#db# ICE: 42 -648 -6 -41 -1
#db# ICE: 40 -648 -6 -40 0
#db# ICE: 41 -648 -6 -41 0
#db# ICE: 41 -648 -6 -44 3  -- false  ( v should be negativ )
#db# ICE: -51 -648 -6 49 2
#db# ICE: 41 -645 -3 -41 0
#db# ICE: 41 -645 -3 -41 0
#db# ICE: 40 -645 -3 -40 0
#db# ICE: 41 -645 -3 -41 0

pwpiwi, 2015-07-19:
This is still within the same quadrant +/-45°. Therefore OK and consistent. It would cross the 45° line for cq=44. Then v would become 0 and a phase shift would be detected.

iceman1001, 2015-07-19:
hm I must be think this differently..
Quadrants.

-1,1  |  1,1
--------------
-1,-1 |  1,-1

sumi, sumq  is -648, -6
i, q is -44, 3
two different quadrants..   Do you mean with +/-45°  that its inside the bounding quadrants?

pwpiwi, 2015-07-19:
Exactly. If the vector is in the adjacent half of the neighboring quadrants then this is considered "in phase" as well.

iceman1001, 2015-07-19:
Since the original answer is answered,  (the tag is not initialised yet for usage by navigo. I wonder if there is a way to detect that?)

Closed 2015-07-19.

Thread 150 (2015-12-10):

Proxmark will not show up unless button is held down.

TopazA, 2015-12-10:
Hi there,
Using a proxmark 3.

If i hold down the switch while connecting the Proxmark to my OS-X machine (and continue holding it), I can see the device under /dev/cu.usbmodem1412/ and can run

```
./proxmark /dev/cu.usbmodem1412
```

Without any errors being thrown.

While the button is being held down, the red and orange LED's are lit up and do not change.

I can also see the following output from

```
>> system_profiler SPUSBDataType

    Communication Device:

      Product ID: 0x504d
      Vendor ID: 0x2d2d
      Version: 0.01
      Speed: Up to 12 Mb/sec
      Manufacturer: proxmark.org
      Location ID: 0x14200000 / 8
      Current Available (mA): 500
      Current Required (mA): 0
```

I can't see any details if i run 'hw version' from within the proxmark app

If i let go of the button, the green LED briefly lights up and disappears. Every 18-20 seconds the relay also clicks audibly.
In addition, i can't see any output from system_profiler and the device does not appear in /dev/cu\*

I've inherited this device so i'm not sure whats happened. I think the previous user may have attempted to flash the firmware/bootloader.

I successfully (i think) upgraded the image while running the following command (with the button held down)

```
sh-3.2# ./flasher /dev/cu.usbmodem1421 ../armsrc/obj/fullimage.elf
Loading ELF file '../armsrc/obj/fullimage.elf'...
Loading usable ELF segments:
0: V 0x00102000 P 0x00102000 (0x00025960->0x00025960) [R X] @0x94
1: V 0x00200000 P 0x00127960 (0x00001a44->0x00001a44) [RW ] @0x259f4
Note: Extending previous segment from 0x25960 to 0x273a4 bytes

Waiting for Proxmark to appear on /dev/cu.usbmodem1421. Found.

Flashing...
Writing segments for file: ../armsrc/obj/fullimage.elf
 0x00102000..0x001293a3 [0x273a4 / 314      blocks]........................................................................................................................................................    ..................................................................................................................................................................     OK

Resetting hardware...
All done.

Have a nice day!
```

If i do the same thing but attempt to flash the bootrom.elf file it doesn't matter if i have the button held or not, the proxmark will not 'Appear on USB'

The below output is produced:

```
sh-3.2# ./flasher -b ../../bootrom/obj/bootrom.elf
Loading ELF file '../../bootrom/obj/bootrom.elf'...
Loading usable ELF segments:
0: V 0x00100000 P 0x00100000 (0x00000200->0x00000200) [R X] @0x94
1: V 0x00200000 P 0x00100200 (0x00000b68->0x00000b68) [RWX] @0x298

Waiting for Proxmark to appear on USB...........................................................................^C
```

marshmellow42, 2015-12-10:
looks to me like you have a non matching bootrom to os image.  bootrom has to be flashed.
it also looks like you did not specify the usb address when you attempted to flash the bootrom, but you did when flashing the os/fullimage

lastly, i believe this is something best discussed on the main forum and not github as there is no clear bug.  at least not yet.

iceman1001, 2015-12-10:
use old hid-flasher to upgrade bootrom,  then use new flasher to flash fullimage.
disconnect and reconnect pm3.   If you do read on the forum, there is a lot of threads about this kinds of experiences as @marshmellow42  mentions.

TopazA, 2015-12-11:
Hey @marshmellow42 thanks for that, i can move to the forums if that's better.

@iceman1001 How do i use an old HID-flasher? Is there one included in the current software hosted here? Is there a specific version i should be looking for?

Thanks!

marshmellow42, 2017-03-06:
the old HID-flasher is included in the current software.  but it is unlikely your firmware is that old.. ?

i would like to assume you've already fixed this issue though as it is now over a year later....  time to close this issue?

ronnyandre, 2020-03-10:
I just found this thread. Not sure where the old HID flashes is found. If anyone has a clue, please let me kno.

Closed 2017-03-06.

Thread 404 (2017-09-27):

hf mf hardnested error

merlokk, 2017-09-27:
hf mf hardnested causes runtime error while compiled on windows10
proxmark3 just ended process by error.

merlokk, 2017-09-27:
Unhandled exception [13056] and try to execute debugger

merlokk, 2017-09-27:
hangs here:

brute_force_per_second = brute_force_benchmark();

merlokk, 2017-09-27:
in float brute_force_benchmark()
here:
	brute_force_bs(&bf_rate, test_candidates, 0, 0, maximum_states, NULL, 0);

merlokk, 2017-09-27:
in
bool brute_force_bs(...)

here:
	for(uint32_t i = 0; i < NUM_BRUTE_FORCE_THREADS; i++){
		thread_args[i].thread_ID = i;
		thread_args[i].silent = silent;
		thread_args[i].cuid = cuid;
		thread_args[i].num_acquired_nonces = num_acquired_nonces;
		thread_args[i].maximum_states = maximum_states;
		thread_args[i].nonces = nonces;
		thread_args[i].best_first_bytes = best_first_bytes;
		pthread_create(&threads[i], NULL, crack_states_thread, (void*)&thread_args[i]);
	}

merlokk, 2017-09-27:
as i see maybe in thread here
static void* crack_states_thread(void* x){

merlokk, 2017-09-27:
log like that
proxmark3>  hf mf hardnested 0 A A0A1A2A3A4A5 4 A FFFFFFFFFFFF
--target block no:  4, target key type:A, known target key: 0xffffffffffff, file action: none, Slow: No, Tests: 0
TThread 1 starts working on bucket 1
Thread 2 starts working on bucket 2
Thread 0 starts working on bucket 0
hread 3 starts working on bucket 3

merlokk, 2017-09-28:
breaks here    
 const uint64_t key = crack_states_bitsliced(thread_arg->cuid, thread_arg->best_first_bytes, bucket, &keys_found, &num_keys_tested, nonces_to_bruteforce, bf_test_nonce_2nd_byte, thread_arg->nonces);

marshmellow42, 2017-09-28:
I compile and run on Windows 10 and have no issues with hardnested.  Check that you have all the files required in the correct locations.  Check file permissions (admin elevated access).  Tell us your exact cpu

merlokk, 2017-09-28:
CPU-Z version			1.81.0.x64
Processors
-------------------------------------------------------------------------
Number of sockets		1
Number of threads		4
APICs
-------------------------------------------------------------------------
Socket 0
	-- Core 0
		-- Thread 0	0
	-- Core 1
		-- Thread 0	1
	-- Core 3
		-- Thread 0	3
	-- Core 2
		-- Thread 0	2
Timers
-------------------------------------------------------------------------
	ACPI timer		3.580 MHz
	Perf timer		2.943 MHz
	Sys timer		1.000 KHz
Processors Information
-------------------------------------------------------------------------
Socket 1			ID = 0
	Number of cores		4 (max 4)
	Number of threads	4 (max 4)
	Name			AMD Athlon II X4 640
	Codename		Propus
	Specification		AMD Athlon(tm) II X4 640 Processor
	Package 		Socket AM3 (938)
	CPUID			F.5.3
	Extended CPUID		10.5
	Brand ID		9
	Core Stepping		BL-C3
	Technology		45 nm
	TDP Limit		95.0 Watts
	Core Speed		3013.3 MHz
	Multiplier x Bus Speed	15.0 x 200.9 MHz
	HT Link speed		2008.8 MHz
	Stock frequency		3000 MHz
	Instructions sets	MMX (+), 3DNow! (+), SSE, SSE2, SSE3, SSE4A, x86-64, AMD-V
	L1 Data cache		4 x 64 KBytes, 2-way set associative, 64-byte line size
	L1 Instruction cache	4 x 64 KBytes, 2-way set associative, 64-byte line size
	L2 cache		4 x 512 KBytes, 16-way set associative, 64-byte line size
	Max CPUID level		00000005h
	Max CPUID ext. level	8000001Bh
	Cache descriptor	Level 1, I, 64 KB, 1 thread(s)
	Cache descriptor	Level 1, D, 64 KB, 1 thread(s)
	Cache descriptor	Level 2, U, 512 KB, 1 thread(s)
	FID/VID Control		yes
	FID range		4.0x - 15.0x
	Max VID			1.400 V
	# of P-States		4
	P-State			FID 0xE - VID 0x0C - IDD 19 (15.00x - 1.400 V)
	P-State			FID 0x7 - VID 0x14 - IDD 14 (11.50x - 1.300 V)
	P-State			FID 0x2 - VID 0x1C - IDD 13 (9.00x - 1.200 V)
	P-State			FID 0x100 - VID 0x28 - IDD 8 (4.00x - 1.050 V)

	Package Type		0x1
	Model			40
	String 1		0xA
	String 2		0x6
	Page			0x0
	CmpCap			4
	ApicIdCoreSize		4
	TDC Limit		76 Amps
	Boosted P-States	0
	Max non-turbo ratio	15.00x
	Max turbo ratio		15.00x
	Max CPU COF		30
	Core Performance Boost	no
	P-State			0, FID 0xE - VID 0x0C (15.00x - 1.400 V)
	P-State			1, FID 0x7 - VID 0x14 (11.50x - 1.300 V)
	P-State			2, FID 0x2 - VID 0x1C (9.00x - 1.200 V)
	P-State			3, FID 0x100 - VID 0x28 (4.00x - 1.050 V)
	Attached device		PCI device at bus 0, device 24, function 0
	Attached device		PCI device at bus 0, device 24, function 1
	Attached device		PCI device at bus 0, device 24, function 2
	Attached device		PCI device at bus 0, device 24, function 3
	Attached device		PCI device at bus 0, device 24, function 4
	PERFEVT			122652032.0 MHz

	Temperature 0		36 degC (95 degF) (Core #0)
	Temperature 1		35 degC (95 degF) (Core #1)
	Temperature 2		35 degC (95 degF) (Core #3)
	Temperature 3		35 degC (95 degF) (Core #2)
	Power 00		106.40 W (Package)
	Clock Speed 0		3013.26 MHz (Core #0)
	Clock Speed 1		3013.26 MHz (Core #1)
	Clock Speed 2		3013.26 MHz (Core #3)
	Clock Speed 3		3013.26 MHz (Core #2)
	Core 0 max ratio	15.0 (effective 15.0)
	Core 1 max ratio	15.0 (effective 15.0)
	Core 2 max ratio	15.0 (effective 15.0)
	Core 3 max ratio	15.0 (effective 15.0)

merlokk, 2017-09-28:
file permissions is ok, files from repository.

pwpiwi, 2017-09-28:
Any compilation or link warnings? Does it print anything before exiting? Which compiler do you use?

No problems here with Windows 10.

merlokk, 2017-09-28:
There is no computer wahrnings. And I use proxspace from Gator96100

merlokk, 2017-09-29:
Maybe it not works on AMD Athlon II X4 640 ?

marshmellow42, 2017-09-29:
How recently did you get Gators proxspace?  He had an issue in his environment a while back that caused an issue with hardnested.
Might need to re install it?

marshmellow42, 2017-09-29:
See http://www.proxmark.org/forum/viewtopic.php?id=5034

pwpiwi, 2017-09-29:
@merlokk: do you use precompiled binaries? Or did you compile yourself?

merlokk, 2017-09-29:
I compile myself with latest Gator's proxspace from github.  Its like my problem. Ill look.

merlokk, 2017-09-29:
There is no rights problem, UAC disabled and so on. Compiling ok, no problem with perl(

merlokk, 2017-09-29:
tried to put this to run bat
powershell -Command "Start-Process 'msys\msys.bat' -Verb runAs

no result.

merlokk, 2017-09-29:
how do you start it?
cd client
proxmark3 com1
?

pwpiwi, 2017-10-01:
yes (if your proxmark is on com1), Or `client/proxmark3 com1`

iceman1001, 2017-10-01:
very rarely is a device connected to com1 on a windows-based computer.  Normally com3 or upwards

merlokk, 2017-10-02:
mine com6. usually, i run to from client folder, i have tried to run id your way, but not succeed.

pwpiwi, 2017-10-02:
Does it print anything before exiting?

merlokk, 2017-10-02:
no, windows just kills the process

pwpiwi, 2017-10-02:
Before you can type any command?

merlokk, 2017-10-02:
before it works. no its not serial. its like the process need somewhat and dont found.

merlokk, 2017-10-20:
on appveyor works( strange....

iceman1001, 2017-12-25:
@merlokk   whats the status with this one?   Does hardnested work for you or not?

merlokk, 2017-12-25:
from my pc it not works(  maybe lets close it and i will open it when i have time to check

iceman1001, 2017-12-25:
well,  a non-working hardnested command is a showstopper for a new release.
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
merlokk, 2017-12-28:
sounds like compiler not compiled SSE2 on my platform or bug in CPU

merlokk, 2017-12-29:
It really launches SSE2 code and really goes to XOR's.

i looked into ASM. it looks good.

but it stops and show try to read from FFFFF...
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

it looks like its CPU bug(

merlokk, 2017-12-29:
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

as i see there is no FFFFs. it lokks like cpu bug(

pwpiwi, 2017-12-29:
... or a compiler bug. Did you try another version?

merlokk, 2017-12-29:
i have tried several PC and looks like only my have this error

merlokk, 2017-12-29:
Ill try another version of gcc but maybe after NY

Gator96100, 2018-01-01:
I finally did update my Proxspace environment to gcc 5.3 in order to have support for AVX-512 optimizations. This might also solve your problem. [https://github.com/Gator96100/ProxSpace/tree/NewGCC](url)

merlokk, 2018-01-02:
Thanks! Ill try

merlokk, 2018-01-02:
it not helps (

and it have strange double prompts for me...  but it offtopic)
```
pm3 ~/client$ gcc --version
gcc.exe (i686-posix-dwarf-rev0, Built by MinGW-W64 project) 5.3.0
Copyright (C) 2015 Free Software Foundation, Inc.
This is free software; see the source for copying conditions.  There is NO
warranty; not even for MERCHANTABILITY or FITNESS FOR A PARTICULAR PURPOSE.

pm3 ~/client$                                                                                                             
pm3 ~/client$
```

merlokk, 2018-01-02:
OK,
this works
`bitslice_value_t t = lstate_p[(47- 0)/2].value;`
this works
`bitslice_value_t t = lstate_p[(47- 0)/2].value ^ 0xFF;`
this works
`bitslice_value_t t = lstate_p[(47- 10)/2].value ^ 0xff;`
this works (maybe because of compiler optimization)
`bitslice_value_t t = lstate_p[(47- 0)/2].value ^ lstate_p[(47- 0)/2].value;`
this not(
`bitslice_value_t t = lstate_p[(47- 0)/2].value ^ lstate_p[(47- 10)/2].value;`

merlokk, 2018-01-02:
OK. im pass(
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

there are 2 mov instructions. program hangs on 2nd.
as i see all is OK with memory alignment and access..
this code successfully executes on another CPU and travis
so it looks that this bug in very low level. maybe in compiling SSE2 with gcc.
I cant fix it.

Maybe it needs to add key to `hardnested` command not to use any of optimization. and thats all(

iceman1001, 2018-01-02:
the first one moves from eax register,   the second from ebp-0x07e8 memory location.
Where does those registers point to?  is the memoryallocation too small?

merlokk, 2018-01-02:
ebp-0x07e8 - memory is ok. there are 2 memory windows at top - with address of ptr, on the bottom - with memory

eax also contains address and it ok(

merlokk, 2018-01-03:
iceman fork:
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
the same (

iceman1001, 2018-01-03:
you have a strange computer...

merlokk, 2018-01-03:
I found another pc with this cpu and it shows this error too.
maybe it depends on cpu(

merlokk, 2018-01-03:
ok. #538 can make `hf mf hardnested` work without hardware acceleration
I cant fix it. maybe gcc compiles wrong code for this CPU

pwpiwi, 2018-01-05:
> ebp-0x07e8 - memory is ok.

No, it is not. The address 0x45FF6A4 is not aligned at a 16Byte boundary.

From the x86 instruction set reference:
> When the source or destination operand is a memory operand, the operand must be aligned on a 16-byte (128-bit version) or 32-byte (VEX.256 encoded version) boundary or a general-protection exception (#GP) will be generated.

So there is either a compiler bug or an alignment statement is missing in the hardnested code.

iceman1001, 2018-01-05:
The depth of both @merlokk  and @pwpiwi  knowledge is amazing.

merlokk, 2018-01-05:
0x45FF6A4 aligned by 4 bytes.

Here is an indirect reading:
0x45FF6A4 - address 0x03af5d20
0x03af5d20 - data alugned by 16 bytes as it needs

and i look inho instruction reference and cant realize is this correct. It looks correct, but maybe not.

pwpiwi, 2018-01-05:
Afaik there is only register indirect addressing in x86 instructions. I.e. the contents of a register (ebp in this case) plus some offset determine the memory address. The address is not correctly aligned.

pwpiwi, 2018-01-05:
http://www.peterstock.co.uk/games/mingw_sse is an older post about this subject. Maybe it is still valid? Which compilers did you try?

iceman1001, 2018-01-05:
The two possible solutions in the link seems like a good test for  @merlokk

merlokk, 2018-01-05:
OK

adding this line to makefile works
`HARD_SWITCH_SSE2 = -mmmx -msse2 -mno-avx -mno-avx2 -mstackrealign`

but i dont know how does it affect performance. looks like not so bad.
and from this line it affected only on SSE2 hardnedted code. So it should be OK.

ill commit it.)

merlokk, 2018-01-05:
@pwpiwi , if you want lets get rid of iX options, but i like to leave them because time from time it will be good to change command set and look....

Closed 2018-01-06.

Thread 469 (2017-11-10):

pm3 lf interference?

marshmellow42, 2017-11-10:
for some time i've noticed some sort of residual interference on the lf side.  maybe my device is dying but i don't think so (checked on 2 pm3's)  ..  or maybe it is picking up my heart beat...

when reading with no card on the antenna there is a pattern that is clear:
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

with weaker antennas it is not as clear (but still present), and with this 40+v antenna it is pretty strong.
(making the checks for "Just Noise" fail)

to reproduce i just run `lf read` - `data plot` with no tag on the antenna.

when i get time i will attempt to go back in time and identify where it first appears, because i know i didn't have this problem a few years ago...

iceman1001, 2017-11-10:
I don't have that,   but then I'm also experimenting with a better noise-detection since the current one is a bit limited.

marshmellow42, 2017-11-10:
what does a lf plot look like for you with no tag near the antenna?

marshmellow42, 2017-11-10:
with a weaker antenna i see:
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

marshmellow42, 2017-11-10:
strong antenna's tune:
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

weaker antenna's tune:
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

pwpiwi, 2017-11-10:
My noise looks more random:
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

antenna tune:
```
proxmark3> hw tune

Measuring antenna characteristics, please wait.........
# LF antenna: 41.11 V @   125.00 kHz
# LF antenna: 42.62 V @   134.00 kHz
# LF optimal: 45.10 V @   127.66 kHz
# HF antenna:  0.28 V @    13.56 MHz
# Your HF antenna is unusable.
Displaying LF tuning graph. Divisor 89 is 134khz, 95 is 125khz.

proxmark3>
```

Are you picking up some external signal? What if you are moving (far away)?

iceman1001, 2017-11-10:
Mine goes between -2 and -10  with an amplitude of 8.

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

```
Measuring antenna characteristics, please wait......  
# LF antenna: 18,43 V @   125.00 kHz  
# LF antenna: 16,23 V @   134.00 kHz  
# LF optimal: 18,84 V @   126,32 kHz  
# HF antenna: 13,58 V @    13.56 MHz  
Displaying LF tuning graph. Divisor 89 is 134khz, 95 is 125khz.

```

iceman1001, 2017-11-10:
it could be bad antenna cable,  bad capacitors, bad connectors,
since its you, I guess you already test it

marshmellow42, 2017-11-10:
I went to different rooms, changed cables, pm3s.  Only common element is ms surface pro...    I'll try a different computer soon

merlokk, 2017-11-11:
Have you checked the power of proxmark and maybe power near antenna amplifier?

marshmellow42, 2017-11-12:
well it appears the interference is location dependent as in a different building i get:
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

so evidently the hvac or other large electronic device in the other building produces a patterned signal interference and a field large enough to be consistent throughout the building...

sorry for wasting your time...

Closed 2017-11-12.

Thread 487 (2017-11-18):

error to flash, how to restore??????!!!!!!!!!!!!!

gearcapitan, 2017-11-18:
fail to flash, unknown device, (device descriptor request error)

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

![Uploading photo4936245251354503119.jpg…]()

HELP!

pwpiwi, 2017-11-18:
This is not a software issue. Please post your question in the forum.

Closed 2017-11-18.

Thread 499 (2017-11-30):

antenna outputs after power on

iceman1001, 2017-11-30:
Its been brought to my attention that the proxmark3 is

1. power out 13.56Mhz when started (initialised).  This output is not stopped until arbitary command is sent.   Swapping from 13.56 -> LF is risk for damaging the driver chip.  Current is large and board have a lot of heat.
2. 'hf 15' commands leaves antenna on when executed.  ('hf 14a' commands stops)
3. PoD - power on delay in latest source.  Latest source is very slow from start.  I belive this is related with flashing delay issues mentioned.

I suggested a fix for 1.   While it seems a call to FpgaDownloadAndGo() powers the antenna. This is strange,  solution:  turn off antenna afterward afterwards

Fix for 2,  would be looking at all places when a command is finished, it needs to turn off antenna.

iceman1001, 2017-11-30:
or, when thinking on it a bit,  add the FpgaWriteConfWord(FPGA_MAJOR_MODE_OFF);   inside FpgaDownloadAndGo,  in the end.

That will make sure no misstaken powersurges will arise from calls to FpgaDownloadAndGo()

pwpiwi, 2017-11-30:
After so many years someone notices that FPGA is not initialized after downloading the configuration!

I agree that the fix should go into FpgaDownloadAndGo().

Re damaging driver: This should never happen. The drivers have a resistor of at least 33Ohms connected to their output. Hence maximum current is 5V/33Ohms = 150mA. There are at least three drivers connected to the 33Ohms resistor, i.e. the current is max 50mA per driver which is the allowed maximum.

iceman1001, 2017-11-30:
So you knew about it and didn't think it was interesting to fix?
The idea is that the antenna is not powered when swapping between HF - LF in order to be kind to the hardware.

The damaging of drivers,  should not, but could.  There might be hardware revisions which is different.
New revisions which has different antenna strengths compared to old models....

pwpiwi, 2017-11-30:
> So you knew about it and didn't think it was interesting to fix?

No, I didn't notice yet. But it is such a basic thing that I am astonished that no one stumbled over it yet.

> There might be hardware revisions which is different.
 New revisions which has different antenna strengths compared to old models....

That would be bad engineering. I am sure that it is not by accident that the value of these resistors result in exactly the maximum allowed output current. They are meant to protect the drivers.

iceman1001, 2017-11-30:
ok, I misunderstood you.
I didn't realized it until it was brought to my attention and I look inside DownloadFpga() where is sets all to HIGH. Not sure what is needed to initialise the fpga properly.  Its outside my knowledge. This is your field.

Of course, a new revision would have matching resistors and drivers for the new load.

iceman1001, 2017-11-30:
Partly fixed.

What is needed is the tiresum work of looking att all places where the fpga is turned on, and make sure its turned off once its finished.  That is if the command "should" turn off.  Like "hf 14a raw" will need to keep it running..

iceman1001, 2018-02-07:
Another part in making the device behave nice.
https://github.com/Proxmark/proxmark3/pull/566

iceman1001, 2018-02-08:
after this one,  the following commands leave power on.

- hf 15 reader
- hf iclass reader

pwpiwi, 2018-02-09:
Which may be an indicator that it was intended like this. Do you remember our discussion when we changed `hf 14a reader` to behave like this? I still think that the intention was to start a "session" with the reader commands. You then would send commands to the card and see the responses and finally send a "power off" command.

iceman1001, 2018-02-09:
yes,  I agree,  but then we added the **hf search** which doesn't act like that, but we use these "readers" command like a select command,   hence the  **hf 14a raw** can up with option to leave field on/off.  Which I think is an ok solution.    The 15, iclass, reader command acts inbetween here.   There is no clear behavior between  sending  raw commands and act as a simple reader, reading uid and report back.

That is the underlaying problem which needs to be adressed.  I have divided much of that in iceman fork,to have a clear definition between  "reader" / "info" / "raw"  commands.

iceman1001, 2018-02-12:
I think I just leave this one be.   This issue is to general and concerns serveral ones.
I close it and if the need to address the other issues arises,  then a new dedicated issue is better.

Closed 2018-02-12.

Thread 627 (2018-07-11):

OSX USB comm issues ?

TomHarkness, 2018-07-11:
Hi guys,

Latest os x high sierra with the latest client / firmware build using macports to install all libraries (plot window is working).

If I let the client sit for a while (time varies), somewhere between 20 - 50 secs and try and issue HW tune again the pm3 completely hangs as shown below (no lights flash physically for at least 20secs) and no data is shown:

Measuring antenna characteristics, please wait...........
**No response from Proxmark. Aborting...**
proxmark3>
proxmark3>
proxmark3> hw tune

Measuring antenna characteristics, please wait...
LF antenna: 29.56 V @   125.00 kHz
 LF antenna: 22.41 V @   134.00 kHz
LF optimal: 29.56 V @   125.00 kHz
HF antenna: 21.30 V @    13.56 MHz
Displaying LF tuning graph. Divisor 89 is 134khz, 95 is 125khz.

If I then re issue the command as shown above, the info pops up right away as was previously expected but this time the hardware tune obviously doesn't actually do anything as no lights flash and the data comes back instantly. Bare with me here because it gets stranger - IF I were to issue a search command first either lf or hf and have a card over the antenna, search works fine and then if i issue the  HW tune right away it works as expected without the above issue. Sometimes the first instance of "lf search" or "hf search" commands lag as above with HW tune but eventualy complete - sometimes showing the "waiting for response....." message.

I've tested this both on the pm3 easy and the RDV3 - I have both and yes they are genuine.

### HW VER output pm3 easy:

proxmark3> hw ver
[[[ Cached information ]]]

Prox/RFID mark3 RFID instrument
bootrom: master/v3.0.1-386-g708cfa2-suspect 2018-07-11 05:11:22
os: master/v3.0.1-386-g708cfa2-suspect 2018-07-11 05:11:24
LF FPGA image built for 2s30vq100 on 2015/03/06 at 07:38:04
HF FPGA image built for 2s30vq100 on 2017/10/27 at 08:30:59

uC: AT91SAM7S256 Rev B
Embedded Processor: ARM7TDMI
Nonvolatile Program Memory Size: 256K bytes. Used: 196984 bytes (75). Free: 65160 bytes (25).
Second Nonvolatile Program Memory Size: None
Internal SRAM Size: 64K bytes
Architecture Identifier: AT91SAM7Sxx Series
Nonvolatile Program Memory Type: Embedded Flash Memory

### HW VER output RDV3 (also showing the same hw tune issue):

proxmark3> hw ver
[[[ Cached information ]]]

Prox/RFID mark3 RFID instrument
bootrom: master/v3.0.1-386-g708cfa2-suspect 2018-07-11 05:11:22
os: master/v3.0.1-386-g708cfa2-suspect 2018-07-11 05:11:24
LF FPGA image built for 2s30vq100 on 2015/03/06 at 07:38:04
HF FPGA image built for 2s30vq100 on 2017/10/27 at 08:30:59

uC: AT91SAM7S512 Rev B
Embedded Processor: ARM7TDMI
Nonvolatile Program Memory Size: 512K bytes. Used: 196984 bytes (38). Free: 327304 bytes (62).
Second Nonvolatile Program Memory Size: None
Internal SRAM Size: 64K bytes
Architecture Identifier: AT91SAM7Sxx Series
Nonvolatile Program Memory Type: Embedded Flash Memory

proxmark3> hw tune

Measuring antenna characteristics, please wait...........
No response from Proxmark. Aborting...
proxmark3> hw tune

Measuring antenna characteristics, please wait......
# LF antenna: 44.69 V @   125.00 kHz
# LF antenna: 27.64 V @   134.00 kHz
# LF optimal: 47.85 V @   126.32 kHz
# HF antenna: 34.07 V @    13.56 MHz
Displaying LF tuning graph. Divisor 89 is 134khz, 95 is 125khz.

proxmark3>

NOTE:

This was not an issue before switching to MacPorts and re-compiling in order to get the gui working. I'm not sure how that would cause this though as I get no compilation errors etc..

TomHarkness, 2018-07-11:
Update:

This seems related to XQuartz and using the plot window. As soon as I remove XQuartz this issue went away. Commands are now instant.

pwpiwi, 2018-07-12:
Duplicate of issue #283.

TomHarkness, 2018-07-12:
Look to be the same issue. Can definitely confirm that it was XQuartz causing the issue. Client is snappy and responsive even after long periods of being left alone now.

drandreas, 2018-10-04:
I think this issue is related to app-nap. A feature where background applications are put to sleep.
In our case the timeout of `uart_receive` changes from 30ms to 10s.

Apple provides a Obj-C API to disable this feature: (beginActivityWithOptions)[https://developer.apple.com/documentation/foundation/nsprocessinfo]. This also fixes the issue described above. I'm happy to provide a fix, if foreign languages are accepted 😄 .

iceman1001, 2018-10-05:
Bring on the fix!

pwpiwi, 2018-10-05:
Indeed, this would be a long long awaited fix.

> In our case the `select` timeout in `uart_receive` changes from 30ms to 10s.

Is this an observation or is this documented somewhere?

> An alternative solution is to separate rx and tx into two threads.

Hmm, are we sure that the underlying rx and tx functions are thread save on all OS?

> Then an extended `uart_receive` timeout would delay tx. This would also allow for a relaxed polling e.g. 100ms.

I am not sure if I understand this. Delaying tx (sending a command) would still result in a delayed rx (receiving the response) and still running into a timeout?

drandreas, 2018-10-05:
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

I did trace the code execution with _Instruments_

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

I never encountered an OS where it was an issue. But you are right its a grey area. Thats why I opted for disabling AppNap for now: #687.

Can any one test if it compiles on Windows?

drandreas, 2018-10-05:
Apple WWDC several workshops related to AppNap in 2013. In this one they explain how macOS batch processes timer timeouts and extends timer periods like we encountered:
https://developer.apple.com/videos/play/wwdc2013/209/
The talk also covers how an energy efficient app should be designed.

pwpiwi, 2018-10-06:
Compiles on Windows. Travis tests passed for different OSX versions and Linux.

Any Apple user out there to test the fix? @TomHarkness, @Kaicastledine, @digitalentropy ?

digitalentropy, 2018-10-06:
Don’t have current access to macOS system, but will test as soon as I can.  I imagine others will be able to test sooner.

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

TomHarkness, 2018-10-08:
Did some brief testing and the client seems properly responsive with the gui now! Well done!

Closed 2018-10-08.

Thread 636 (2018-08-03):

[solved] hf mf broken after flash from old version

ralik, 2018-08-03:
Hi all,
I've always been working with a proxmark loaded with a version from July 2014.
Today, I thought it would be a good idea to check newer commands. I flashed with latest GitHub repo and have lost the ability to (on cards with which I never had any problem):
- use darkside attack.
- complete a nested attack.
- simply auth and read a block easily.
- simply writing a block.
- even hf 14a reader is having a hard time finding anything.

I just keep getting a massive amount of error messages, "Can't select card" or "Multiple tags detected. Collision after Bit xx" with whatever card<->antenna positions until the PM3 crashes.

I tried to go a few commits back and re-flash but same problem.
I was thinking mehhh just forget about it and go back to my cave ¯\_(ツ)_/¯
But flashing with my good old 2014 Bootrom+fullimage, did not help at all... The hf mf commands are not back! Looks like flashing a newer version has made some irreversible changes to my PM3.

Any idea what happened here? And what can I try to fix that issue.
Any help would be highly appreciated...

pwpiwi, 2018-08-03:
Sensitivity has increased since the very old versions. Results in clipping at low distances. Leave a distance of 2 cm between antenna and card and it should work again.

marshmellow42, 2018-08-03:
pwpiwi probably nailed it, but make sure you flash the bootrom and the fullimage.  And use the client that matches the firmware..
and nothing in the code could cause something irreversible, are you sure the device is taking the flashing?

ralik, 2018-08-03:
I did try every possible angle, distance (as I used to before anyway), but this time, it just fails after like 5 s then there is no angle/position that will help.
Device is being flashed (at least according to ./flasher). Also tried on linux with old github repo. hw version shows the difference.

I went from a r839 to a V3.x.x, went back to r839 and lost all "normal" functioning of my old PM3.

marshmellow42, 2018-08-03:
I assume you checked the obvious like antenna connections, hw tune?

ralik, 2018-08-03:
Yes, all good here.
I have a PCB printed antenna and a couple of handmade ones.

pwpiwi, 2018-08-03:
Please let us see some output:
* when flashing to current release
* client start
* hw ver
* hw tune

ralik, 2018-08-04:
Here is an example of a simple block read

```
proxmark3> hf mf rdbl 0 A FFFFFFFFFFFF
--block no:0, key type:A, key:ff ff ff ff ff ff    
#db# ISO14443A Timeout set to 1060 (10ms)  
#db# ISO14443A Timeout set to 10 (0ms)  
#db# ISO14443A Timeout set to 1060 (10ms)  
#db# rand tag nonce len: 4  
#db# auth uid: 8f237915 nt: 75a0c162  
#db# Cmd CRC response error.  
#db# Read block error  
#db# READ BLOCK FINISHED  
isOk:00  
proxmark3> hf mf rdbl 0 A FFFFFFFFFFFF
--block no:0, key type:A, key:ff ff ff ff ff ff    
#db# ISO14443A Timeout set to 1060 (10ms)  
#db# ISO14443A Timeout set to 10 (0ms)  
#db# ISO14443A Timeout set to 1060 (10ms)  
#db# Multiple tags detected. Collision after Bit 12  
#db# Can't select card  
#db# READ BLOCK FINISHED  
isOk:00  
proxmark3> hf mf rdbl 0 A FFFFFFFFFFFF
--block no:0, key type:A, key:ff ff ff ff ff ff    
#db# ISO14443A Timeout set to 1060 (10ms)  
#db# ISO14443A Timeout set to 10 (0ms)  
#db# ISO14443A Timeout set to 1060 (10ms)  
#db# rand tag nonce len: 4  
#db# auth uid: 8f237915 nt: caa01618  
#db# Authentication failed. Card timeout.  
#db# Auth error  
#db# READ BLOCK FINISHED  
isOk:00  
proxmark3> hf mf rdbl 0 A FFFFFFFFFFFF
--block no:0, key type:A, key:ff ff ff ff ff ff    
#db# ISO14443A Timeout set to 1060 (10ms)  
#db# ISO14443A Timeout set to 10 (0ms)  
#db# ISO14443A Timeout set to 1060 (10ms)  
#db# Multiple tags detected. Collision after Bit 27  
#db# Can't select card  
#db# READ BLOCK FINISHED  
isOk:00  
proxmark3> hf mf rdbl 0 A FFFFFFFFFFFF
--block no:0, key type:A, key:ff ff ff ff ff ff    
#db# ISO14443A Timeout set to 1060 (10ms)  
#db# ISO14443A Timeout set to 10 (0ms)  
#db# ISO14443A Timeout set to 1060 (10ms)  
#db# rand tag nonce len: 4  
#db# auth uid: 8f237915 nt: 3074dace  
#db# Authentication failed. Card timeout.  
#db# Auth error  
#db# READ BLOCK FINISHED  
isOk:00  
proxmark3> hf mf rdbl 0 A FFFFFFFFFFFF
--block no:0, key type:A, key:ff ff ff ff ff ff    
#db# ISO14443A Timeout set to 1060 (10ms)  
#db# ISO14443A Timeout set to 10 (0ms)  
#db# ISO14443A Timeout set to 1060 (10ms)  
#db# Can't select card  
#db# READ BLOCK FINISHED  
isOk:00  
proxmark3> hf mf rdbl 0 A FFFFFFFFFFFF
--block no:0, key type:A, key:ff ff ff ff ff ff    
#db# ISO14443A Timeout set to 1060 (10ms)  
#db# ISO14443A Timeout set to 10 (0ms)  
#db# ISO14443A Timeout set to 1060 (10ms)  
#db# Multiple tags detected. Collision after Bit 32  
#db# Can't select card  
#db# READ BLOCK FINISHED  
isOk:00  
proxmark3> hf mf rdbl 0 A FFFFFFFFFFFF
--block no:0, key type:A, key:ff ff ff ff ff ff    
#db# ISO14443A Timeout set to 1060 (10ms)  
#db# ISO14443A Timeout set to 10 (0ms)  
#db# ISO14443A Timeout set to 1060 (10ms)  
#db# Can't select card  
#db# READ BLOCK FINISHED  
isOk:00  
proxmark3> hf mf rdbl 0 A FFFFFFFFFFFF
--block no:0, key type:A, key:ff ff ff ff ff ff    
#db# ISO14443A Timeout set to 1060 (10ms)  
#db# ISO14443A Timeout set to 10 (0ms)  
#db# ISO14443A Timeout set to 1060 (10ms)  
#db# Multiple tags detected. Collision after Bit 4  
#db# Can't select card  
#db# READ BLOCK FINISHED  
isOk:00  
proxmark3> hf mf rdbl 0 A FFFFFFFFFFFF
--block no:0, key type:A, key:ff ff ff ff ff ff    
#db# ISO14443A Timeout set to 1060 (10ms)  
#db# ISO14443A Timeout set to 10 (0ms)  
#db# ISO14443A Timeout set to 1060 (10ms)  
#db# rand tag nonce len: 4  
#db# auth uid: 8f237915 nt: c02ad681  
#db# READ BLOCK FINISHED  
isOk:01 data:8f 23 79 15 c0 28 04 00 00 00 00 00 21 27 20 00   
proxmark3
```

ralik, 2018-08-04:
Sorry, my bad.

Here it is:

```
pm3 --> hf mf dbg 0
#db# Debug level: 0  
pm3 --> hf mf rdbl 0 A 9c06d18d39e4
--block no:0, key type:A, key:9C 06 D1 8D 39 E4    
isOk:00  
pm3 --> hf mf rdbl 0 A 9c06d18d39e4
--block no:0, key type:A, key:9C 06 D1 8D 39 E4    
isOk:00  
pm3 --> hf mf rdbl 0 A 9c06d18d39e4
--block no:0, key type:A, key:9C 06 D1 8D 39 E4    
isOk:00  
pm3 --> hf mf rdbl 0 A 9c06d18d39e4
--block no:0, key type:A, key:9C 06 D1 8D 39 E4    
isOk:00  
pm3 --> hf mf rdbl 0 A 9c06d18d39e4
--block no:0, key type:A, key:9C 06 D1 8D 39 E4    
#db# Multiple tags detected. Collision after Bit 28  
isOk:00  
pm3 --> hf mf rdbl 0 A 9c06d18d39e4
--block no:0, key type:A, key:9C 06 D1 8D 39 E4    
#db# Multiple tags detected. Collision after Bit 22  
isOk:00  
pm3 --> hf mf rdbl 0 A 9c06d18d39e4
--block no:0, key type:A, key:9C 06 D1 8D 39 E4    
isOk:00  
pm3 --> hf mf rdbl 0 A 9c06d18d39e4
--block no:0, key type:A, key:9C 06 D1 8D 39 E4    
isOk:00  
pm3 --> hf mf rdbl 0 A 9c06d18d39e4
--block no:0, key type:A, key:9C 06 D1 8D 39 E4    
isOk:00  
pm3 --> hf mf rdbl 0 A 9c06d18d39e4
--block no:0, key type:A, key:9C 06 D1 8D 39 E4    
isOk:00  
pm3 --> hf mf rdbl 0 A 9c06d18d39e4
--block no:0, key type:A, key:9C 06 D1 8D 39 E4    
isOk:01 data:C2 B8 C0 19 A3 08 04 00 62 63 64 65 66 67 68 69
```

ralik, 2018-08-06:
Yes, I have tried a few distro to see if there were any differences. But I get pretty much the same poor results.
Also I went back to an old rev I have on my PC (ProxSpace from 2012), that is the first one I used when I purchased my PM3, it has a few traces in the client's folder.
At this time I don't believe the wording "Multiple tags detected" or "Collision after Bit" existed in the code.
I have a 6.6MB proxmark3.log in that folder which only contains this wording from when I used it yesterday. Everything else is from back in 2012 and said that sentence.
Maybe I should JTAG-flash to fully revert back to the original version where I had no issue with HF MF

pwpiwi, 2018-08-08:
Don't mix client and firmware version. Iceman client must go with Iceman firmware. Official client must go with official firmware. And both client and firmware must be of the same version.

Flashing the firmware is reversible. No need to use JTAG-flash when flasher still worls.

BarikMana, 2018-08-09:
I did flash firmware with iceman's firmware before using his client.
And I did flash fullimage+bootroom+fgpaimage+osimage before using the old 2012 proxspace client.
Yet I am still seeing "Multiple tags detected" or "Collision after Bit" which appears to have been introduced after 2012.

ralik, 2018-08-09:
In the last output, I flashed with iceman's firmware and was using iceman's firmware from the same commit.
When I tested with an old ProxSpace from 2012, I flashed bootroom, fpgaimage, fullimage, osimage from the same 2012 version and I was using the client from the same 2012 version.
Yet, I am still seeing "Multiple tags detected" or "Collision after Bit" even though this does not appear to be in the source code from 2012. Meaning that it appears to be some leftover from newer 2018 revisions that was not erased after flashing to a 2012 older version.

marshmellow42, 2018-08-09:
I cannot speak for icemans repo, as it says, use at your own risk.

iceman1001, 2018-08-09:
I see you are using linux..
try
**./update.sh**

pwpiwi, 2018-08-14:
Issue fixed using ./update.sh?

iceman1001, 2018-08-14:
...this issue is a bit inconsistent.

**For testing purposes,**
- Which pm3 device do you have?  [old green pcb,  rdv10 (orange pcb),  rdv20 (blue pcb) ,  rdv30 easy or rdv40? ]
- test one repo at the same time.  ie  compile / flash  from same repo.
- output from     hw version,   hw tune,  hw status.
- 14a testing,    use different distances between tag and antenna.  Normally 1-2cm.

if hw tune reports bad values from antenna,  then check your connection with antenna.  The client should report back values in order for the pm3 to function normal.

Barmallini, 2018-08-14:
Same issue. PM3 easy (black)
Prox/RFID mark3 RFID instrument
bootrom: master/v3.0.1-382-gab20cc3-suspect 2018-07-31 11:46:17
os: master/v3.0.1-382-gab20cc3-suspect 2018-07-31 11:46:30
LF FPGA image built for 2s30vq100 on 2015/03/06 at 07:38:04
HF FPGA image built for 2s30vq100 on 2017/10/27 at 08:30:59

uC: AT91SAM7S256 Rev D
Embedded Processor: ARM7TDMI
Nonvolatile Program Memory Size: 256K bytes. Used: 194936 bytes (74%). Free: 672
08 bytes (26%).
Second Nonvolatile Program Memory Size: None
Internal SRAM Size: 64K bytes
Architecture Identifier: AT91SAM7Sxx Series
Nonvolatile Program Memory Type: Embedded Flash Memory

proxmark3> hw tune

Measuring antenna characteristics, please wait.........
# LF antenna: 23.92 V @   125.00 kHz
# LF antenna: 18.84 V @   134.00 kHz
# LF optimal: 23.65 V @   122.45 kHz
# HF antenna: 14.57 V @    13.56 MHz
Displaying LF tuning graph. Divisor 89 is 134khz, 95 is 125khz.

proxmark3> hf mf rdbl 0 A FFFFFFFFFFFF
--block no:0, key type:A, key:ff ff ff ff ff ff
#db# Can't select card
#db# READ BLOCK FINISHED
isOk:00

iceman1001, 2018-08-14:
ok, so different distance between tag and antenna...
and pm3 easy have a lot of cheap clones out on aliexpress etc,  they (the clones) have been known to be problematic

Barmallini, 2018-08-15:
Yes, i have aliexpress clone.
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

It snoop something, but not as shown at https://code.google.com/archive/p/proxmark3/wikis/RunningPM3.wiki section "Get the UID of a Mifare card using ’snooping’ capabilities"

ralik, 2018-08-16:
> Issue fixed using ./update.sh?
Yes
Old board (green one from 2011-2012)

Distance/angle/position doesn't have much effect (except from what you would expect) after that. Even hf mf hard runs smoothly.

hackcrypto, 2022-01-26:
> Sensitivity has increased since the very old versions. Results in clipping at low distances. Leave a distance of 2 cm between antenna and card and it should work again.

Thanks bro it WORK !

Closed 2018-08-16.

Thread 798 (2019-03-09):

Hitag2 issues in current repo - i2c related?

jslawek, 2019-03-09:
Hi,

hitag2 does not work for me in current repo version (tried RRG too btw).
"lf hitag reader 26" does not recognize tag id (no result in client), reading blocks or simulating also does not work.
I have tried several commits back, and it works for me in https://github.com/Proxmark/proxmark3/commit/968ad672808c4bd4ae0d413bbe877f263e3f8228 but does not work in
5a28b51 (I could not compile these few in between to check).
I have further pinpointed the problem to @pwpiwi commit https://github.com/Proxmark/proxmark3/commit/8d7d7b618777fddcde8897945f2ec42eb85095e2, more specifically " "update i2c.c from RfidResearchGroup repository".
After switching i2c.c in 5a28b51 to the previous one from 968ad67, hitag commands (lf hitag) work for me again.

I confirmed this on Elechouse RDV2 as well as another AT91SAMS512 clone. Interestingly, the RDV4 behaves in a different way however. The exact same fw that recognizes hitag2 UID for RDV2, flashed on RDV4 ends with error:
```code
proxmark3> lf hitag reader 26
#db# Uknown frame length: 2
```

Also, even when the lf hitag commands work, the "lf search" does not recognize the tag anyway. And after this "lf search" with empty result - "lf hitag" commands do not work any more, until the Proxmark device re-plug. But I think this may be another, unrelated issue.

pwpiwi, 2019-03-13:
I don't have a Hitag card at hand but I think that @iceman1001 is right. I have added TC0 initialization to Hitag (and HitagS) functions in PR #800. Please give it a try.

iceman1001, 2019-03-13:
yup yup,  those TC0 inits made the **lf hitag reader 26** come alive again.   It can identify my card.

```
pm3 --> lf hita reader 26
#db# Configured for hitag2 reader
Valid Hitag2 tag found - UID: ac20a810
pm3 --> lf hita list
recorded activity (TraceLen = 512 bytes):
 ETU     :nbits: who bytes
---------+-----+----+-----------
 +      0:    5:     c0
 +    203:   32: TAG ac! 20  a8  10
```

jslawek, 2019-03-13:
Yes, I confirm it works! Not only "lf hitag reader 26" but also reading the whole card and simulating it to the reader, and moreover - "lf search" also recognizes the tag again!
I am still having difficulties on RDV4 though, but I guess it is unrelated. I begin to suspect it may be somehow related to signal quality (clipping?). It gets various length of data (or no data at all), depending how far I place the tag from antenna:
```
proxmark3> lf hitag reader 26
#db# Uknown frame length: 25  
proxmark3> lf hitag reader 26
#db# Uknown frame length: 31  
proxmark3> lf hitag reader 26
#db# Uknown frame length: 25  
proxmark3> lf hitag reader 26
#db# Uknown frame length: 1  
proxmark3> lf hitag reader 26
proxmark3> lf hitag reader 26
```

pwpiwi, 2019-03-13:
merged.

jslawek, 2019-03-13:
Thanks for such quick resolution! Closing as it works for most Proxmark hardware devices, and the RDV4 signal quality issues (not strictly related to this) moved to RRG repo: https://github.com/RfidResearchGroup/proxmark3/issues/124

Closed 2019-03-13.

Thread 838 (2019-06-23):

lf em 4x05write  with password - Query

mwalker33, 2019-06-23:
Hi, this is more query then an issue (until I have completed more testing)
Just started to look at the 4x05.  I could read and write (no password protection/write protection).
I set a password then set the write protect bit, such that a login is needed.
Once this was done, I could read, but no longer write (even with the password)
Command Used : lf em 4x05write a 4 d 0001805F p feedbeef (should be enough to clear the write protect bit).
I had a quick look at the source and a quick play.  (for testing) I setup the code such that
the SendForward funtion would only seed the following block of code once.

	// Set up FPGA, 125kHz or 95 divisor
	LFSetupFPGAForADC(95, true);

	// force 1st mod pulse (start gap must be longer for 4305)
	fwd_bit_sz--; //prepare next bit modulation
	fwd_write_ptr++;
	FpgaWriteConfWord(FPGA_MAJOR_MODE_OFF); // field off
	WaitUS(55*8); //55 cycles off (8us each)for 4305  //another reader has 37 here...
	FpgaWriteConfWord(FPGA_MAJOR_MODE_LF_ADC | FPGA_LF_ADC_READER_FIELD);//field on
	WaitUS(18*8); //18 cycles on (8us each)

Once done,  the command with the password seems to work worked as expected.

My query.  Given that (from my understanding) that when using the password/login the chip needs to stay active.  Could running the above code twice (once for login, then once for the write command) not be ideal ?

marshmellow42, 2019-06-23:
Interesting point.  I've never had trouble writing or reading em chips with password as is, so I left it in.  The gap shouldn't be enough to discharge the chip (or it couldn't hear any cmd).

I'll have to check the datasheet again to see if it covers subsequent cmds.

What chip do you have?

mwalker33, 2019-06-23:
It is meant to be a EM4305 (look and acts like one).  It is a smaller fob, so correct position on the antenna is needed.

Note: This is not a request, more a discussion point.

I will need to repeat the tests a few time to confirm.    Maybe its just not getting a strong induction and does decay a bit too fast.  Just a thought.
I will try to repeat a few times over the week and confirm, I might order in some cards as well for testing.

The detailed specs seem a little light on in my datasheet.
This is about all I could find.
"...When the Login command is successfully processed, the
IC responds with preamble pattern (00001010) and returns
to Default Read mode...."
and
"...Login flag is set until the next power-up, which means
that Login command has to be sent only once after
power up to enable execution of password protected
commands...."

So I read that as, Energize Chip, Send Login, Read 00001010 (login ok) then proceed with any other command protected or not until the chip is disabled or "shuts down" (logon only needed once).
My thought was that IF things are on the borderline of not working (antenna mismatch) then the less chance to drop in power the better.

For reference.
This is on an PM3 Easy
Measuring antenna characteristics, please wait.........
# LF antenna: 33.14 V @   125.00 kHz
# LF antenna: 25.44 V @   134.00 kHz
# LF optimal: 33.69 V @   122.45 kHz
# HF antenna: 31.20 V @    13.56 MHz
Displaying LF tuning graph. Divisor 89 is 134khz, 95 is 125khz.

marshmellow42, 2019-06-23:
I would guess you are correct, you're small chip is on the edge of coupling with you're antenna.

I had tried to lower the gap to 37*8 when I implemented as I snooped another reader doing that, but it didn't work consistently for me.

Without the gap at all I'm surprised your chip recognized the command and came out of reg read mode.

marshmellow42, 2019-06-23:
Wrong button ....  stupid small phone screens..

marshmellow42, 2019-06-23:
I'll try to do some testing, but I am out of town and won't be near my pm3s for a few weeks.

mwalker33, 2019-06-23:
Very Low priority.
I have ordered some cards to play with as well.

pwpiwi, 2019-06-23:
Does anyone of you use a RDV4? There might be differences as well. I didn't check the LF part yet, but the HF antenna continues to oscillate for quite some time even after the carrier is switched off.

marshmellow42, 2019-06-23:
I have one and it did work, but barely as I recall.  Unfortunately I'm a few weeks away from it at the moment

mwalker33, 2019-06-23:
On the RDV4 (rrg fork) it cant read the fob at all (or as good as).  Given the LF antenna challenges (waiting to see if the new lf antenna will make it to market), and being a fob I was not expecting too much.
To get a read at all on the rdv4, I had to remove to cover, place the fib right on the antenna and reflect the signal with a bit of foil underneath the unit.  The Easy  mostly works when you get the position right.
My RDV4 has some t5577 challenges as well (as most I think), but the foil trick gets it working well in the field.

mwalker33, 2019-06-23:
To be honest, I more then happy to put it down to coupling issue.   After a lot of playing I can make it work with the original settings, just need to be more exact with a good position.  Once its position is just right, it will work nearly every time (on current software), just seems a little bit easier with a tweak.
I also tested have all the original code back in except
LFSetupFPGAForADC(95, true); (on the command after the login), as that should already be done from the login.  I will see how it goes with full size cards when they arrive.

mwalker33, 2019-06-29:
Some test results.
From the way I understand things, when using a password, you login to the chip and as long as the chip does not loose power, then the login will remain active.
When sending a command you need to tell the chip to stop normal read mode by sending a field stop,
then the command.
So, that said, as long as there is only a single command at a time, then the code as is should be correct.

When sending the password write, then we need to make sure there is enough of a gap between the password/login and the write (to ensure the write is a new command (> 586 u sec (t_process_pause) + time for preamble (00001010 OK or 00000001 Fail).    At the moment this is most likely taken care of by the time for the LFSetupFPGAForADC(95, true);  as the read/write commands dont have any delay between login and read/write.

For testing I added the following to the end of the login function.
WaitUS(400);
// Now do the acquisition
DoPartialAcquisition(20, true, 6000, 1000);
This allowed me NOT to complete the write and confirm the password was accepted by its preamble returning to the client.  The login was OK  in every test I did.

All that said, while there may be some fine tuning that MAY help a little, The bigger challenge is still antenna coupling and power (not a software issue).
Some interesting tests results with my unit and my 4305 fob.
- Place the fob on the proxmark such that every read of block X works.
- Send a non-password write command and ensure it works (every time)
- Send a password protected write command (even though password not required)
Finding : The more consecutive 1's in the password the less stable it is.
In the above setup ( I expect it will vary between gear).

lf em 4x05write a 11 d ff000000 p 00000000   : Fails nearly every time
lf em 4x05write a 11 d f0000000 p 00000000  : Works most of the time
lf em 4x05write a 11 d 80000000 p 00000000 : Works every time
(note randomin tesing of the position of the FF hints it can be anywhere (e.g. 00ff0000).
Given that to send a '1' we are dropping the field (as I understand it), the more consecutive '1's the bigger the impact of a poor coupling/power drain.

pwpiwi, 2019-06-30:
Hmm, Shouldn't the `WaitUS()` be before the `FpgaWriteConfWord()` ? I.e. 23 cycles on and then 32-23 cycles off?
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
pwpiwi, 2019-07-02:
At least this seems to be common for the data sheets: at the reader side, a "1" means "modulating", which means " field off".

mwalker33, 2019-07-02:
mmm Trying to get my head around this.
4469 : To send a logic "1" bit, the transceiver continues to send clocks without modulation
wont the field need to be ON to send the clocks ?
4305 : For sending a logic "1", the reader field shall stay ON for 32 RF periods.
This directly says field shall stay ON for a "1"
The chip turns "its" modulation off half way through a 1 in order to charge.
So that all seems to say the field is ON for a 1

Then for a 0
4469 : To send a logic "0" bit, the transceiver stops sending clocks (100% modulation)
4305: When sending a logic "0", the reader field shall be stopped

so to me that seems to line up.  i.e. "1" Field ON - No modulation
The bit a find contradicts is.
4469: To send a logic "0" bit, the transceiver stops sending clocks (100% modulation) during the first half of a bit period (which i tend to agree with)
4305 : proposed to send a logic "0" by keeping the reader field ON for 18 RF periods and switching it OFF for 14 RF periods (which does not seem to match with whats working)

i.e. the 4305 seems to be the reverse order of the 4469 when it comes to the "proposed" option.
to me the reader datasheet lines up with the 4469 statement.

The way i read it all is the reader datasheet, the 4469 data sheet and the existing code all line up.
The 4305 datasheet seems mostly right except the "0" on/off order.

pwpiwi, 2019-07-04:
Yes. I fully agree. Seems to be an error in the 4305 datasheet.

marshmellow42, 2019-07-06:
glad i'm not the only one that was confused by their datasheets..  i compared at least 4 different ones a while ago when i tweaked this code.  the timings exist today may or may not be optimal.  if you find something that works better for you i'd be happy to test it next week.

one thing i know we are not doing, is following the datasheet recommendations when it comes to syncing to the tag's modulation. i'm not sure we can, or need to, as it seemed pretty reliable with a good hand made antenna and a card sized tag as it is.

mwalker33, 2019-07-06:
From my testing with my fob (only have the one type atm) with one change I got much better results.
i.e. just placed the fob on the easy (center of lf antenna) and all commands worked 1st time every time.
prior the fob read ok, but most writes had issues and needed to hold the fob on an angle in the right spot.

while(fwd_bit_sz-- > 0) { //prepare next bit modulation
	if(((*fwd_write_ptr++) & 1) == 1)
		WaitUS(32*8); //32 cycles at 125Khz (8us each)
	else
		//These timings work for 4469/4269/4305 (with the 55*8 above)
		FpgaWriteConfWord(FPGA_MAJOR_MODE_OFF); // field off
		WaitUS(23*8); //23 cycles off (8us each)
		FpgaWriteConfWord(FPGA_MAJOR_MODE_LF_ADC | FPGA_LF_ADC_READER_FIELD);//field on
		WaitUS((32-23)*8); //18 cycles on (8us each)

from the above code snip, the very last line (coded for clarity) was the only change.
i.e. The 2nd wait in the else was changed such that the sum of the "0" waits is 32 * 8.

marshmellow42, 2019-07-06:
That makes sense as to how I read the ds as well.  I'll test that with my setup and make sure there's no surprises, then we can patch that change

pwpiwi, 2019-07-11:
> one thing i know we are not doing, is following the datasheet recommendations when it comes to syncing to the tag's modulation. i'm not sure we can, or need to, as it seemed pretty reliable as it is with a good hand made antenna and a card sized tag.

I understand that syncing can be compensated by having the first gap very long (some datasheets recommend 100 cycles - but I am wondering if this wouldn't power down the card completely if coupling isn't good).

marshmellow42, 2019-07-11:
i find no difference on the different tag types with my setup with the corrected timings, so i propose we adjust the timings to match our current understanding of the datasheets.  (32 * 8us per bit)

i have made a PR #846

mwalker33, 2019-07-12:
I have synced and tested, all working as expected.
Thanks.

Closed 2019-07-12.

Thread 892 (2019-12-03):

My proxmark3 is temperature sensitive,warm make it work.

SDPatrick, 2019-12-03:
Hi  guys, My proxmark3 had a very wired problem.
works fine at high temperature and failed at low temperature.
**1:**
hardware info~
~~~~~~~~~~~~~~~~~~~~~~~
pm3 --> hw version  
Proxmark3 RFID instrument
[ ARM ]
 bootrom: iceman/master/ice_v3.1.0-1094-g97128ad5 2019-08-28 01:58:55
      os: iceman/master/ice_v3.1.0-1094-g97128ad5 2019-08-28 01:59:00
[ FPGA ]
 LF image built for 2s30vq100 on 2017/10/25 at 19:50:50
 HF image built for 2s30vq100 on 2018/ 9/ 3 at 21:40:23  
 [ Hardware ]   
  --= uC: AT91SAM7S512 Rev A  
  --= Embedded Processor: ARM7TDMI  
  --= Nonvolatile Program Memory Size: 512K bytes, Used: 235688 bytes (45%) Free: 288600 bytes (55%)  
  --= Second Nonvolatile Program Memory Size: None  
  --= Internal SRAM Size: 64K bytes  
  --= Architecture Identifier: AT91SAM7Sxx Series  
  --= Nonvolatile Program Memory Type: Embedded Flash Memory

~~~~~~~~~~~~~~~~~~~~~~~~~~~~~~~~~~~~
**2:**
can’t read all HF tags when it’s cold (eg. winter).
~~~~~~~~~~~~~~~~~~~~~~~~
pm3 --> hw tune
[=] measuring antenna characteristics, please wait...
[!] LF antenna is UNUSABLE
[+] HF antenna: 30.23 V - 13.56 MHz  
[+] HF antenna is OK
[-] Not showing LF tuning graph since all values is zero.
pm3 --> hf 14a info  
[!] iso14443a card select failed  
~~~~~~~~~~~~~~~~~~~~~~~~

**3:**
works normal after I heated the PCB board
~~~~~~~~~~~~~~~~~~~~~~~~
pm3 --> hw tune
[=] measuring antenna characteristics, please wait...
 [!] LF antenna is UNUSABLE
[+] HF antenna: 29.83 V - 13.56 MHz  
[+] HF antenna is OK
[-] Not showing LF tuning graph since all values is zero.
pm3 --> hf 14a info  
 UID : 84 17 25 02   
ATQA : 00 04  
 SAK : 08 [2]  
TYPE : NXP MIFARE CLASSIC 1k | Plus 2k SL1 | 1k Ev1  
[=] proprietary non iso14443-4 card found, RATS not supported  
[+] Answers to magic commands (GEN 1a): YES  
[+] Prng detection: WEAK  
pm3 -->   
~~~~~~~~~~~~~~~~~~~~~~~~
noted:
removed the LF antenna and tags tested at same postion.
all the situation above can be reappearance from cold to hot
already use the heater air gun to rewelding all the component. the problem still reappearance.

Can any folks give me some advice or suggestions?
I suspect that Capacitor ruined…. willing replaced it…

to be continued..

thanks for your idea .

pwpiwi, 2019-12-03:
How cold is "cold" and how hot is "heated"?

iceman1001, 2019-12-03:
Which Proxmark3 device do you have?

SDPatrick, 2019-12-04:
> How cold is "cold" and how hot is "heated"?
 down under approximately 120.F its not work.
step 3 heated means approximately 150F or higher
here is the thermal image when it "cold" and connected to pc
!20191204085645](https://user-images.githubusercontent.com/58476865/70102774-1f938380-1674-11ea-977e-603013d55b2b.jpg)

SDPatrick, 2019-12-04:
> Which Proxmark3 device do you have?
a chinese modification called proxmark easy 3.with the hf antenna on pcb and a lf antenna removable.
 I supposed that it's a cheap version of PM3 original.

SDPatrick, 2019-12-04:
> Which Proxmark3 device do you have?
a chinese modification called proxmark easy 3.with the hf antenna on pcb and a lf antenna removable.
I supposed that it's a cheap version of PM3 origin

SDPatrick, 2019-12-04:
> Which Proxmark3 device do you have?
@iceman1001
a chinese modification called proxmark easy 3.with the hf antenna on pcb and a lf antenna removable.
I supposed that it's a cheap version of PM3 original

SDPatrick, 2019-12-04:
replaced  2 big capacitor ,still failed
replaced switch 74HC4066,still failed
replaced cysrtal 13.56mhz,still failed

iceman1001, 2019-12-04:
hm,  I see you use iceman fork,  how about you try the [RRG/Iceman repo](https://github.com/rfidresearchgroup/proxmark3)  and make sure you compile it according to this document [PM3OTHER](https://github.com/RfidResearchGroup/proxmark3/blob/master/doc/md/Use_of_Proxmark/4_Advanced-compilation-parameters.md)

Then I would like to see the output from
-hw status
-hw tune
-hf 14a info

SDPatrick, 2019-12-04:
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

OK,I'll try it weekend ,tks.
you tought it's a software problem instead of hardware problem?why? any clues?

iceman1001, 2019-12-04:
No control over the different manufactures of Proxmark3 hardware.  Its totally different.
On the forum, you see that we try to identify problematic versions from sources.
A clone of the Pm3 v30 Easy is notorious for some hw issues.  However not related to heat/cold.

Some stuff we identified and corrected with fw,  which is why I want you to test.

SDPatrick, 2019-12-04:
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

OK，I‘ll test RRG repo asap

SDPatrick, 2019-12-06:
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

**here is the test result below**

~~~~~~~~~~~~~~~~
██████╗ ███╗   ███╗ ████╗      ...iceman fork  
██╔══██╗████╗ ████║   ══█║       ...dedicated to RDV40   
██████╔╝██╔████╔██║ ████╔╝   
██╔═══╝ ██║╚██╔╝██║   ══█║     iceman@icesql.net  
██║     ██║ ╚═╝ ██║ ████╔╝    https://github.com/rfidresearchgroup/proxmark3/  
╚═╝     ╚═╝     ╚═╝ ╚═══╝  pre-release v4.0  

Support iceman on patreon - https://www.patreon.com/iceman1001/  
                 on paypal - https://www.paypal.me/iceman1001  

[=] Session log /home/sa/.proxmark3/log_20191206.txt
[=] Using UART port /dev/ttyACM0   
[=] Communicating with PM3 over USB-CDC   

 [ Proxmark3 RFID instrument ]

 [ CLIENT ]  
  client: RRG/Iceman  
  compiled with GCC 7.4.0 OS:Linux ARCH:x86_64  

 [ PROXMARK3 ]  
  
 [ ARM ]
  bootrom: RRG/Iceman/master/41e0bf9a-dirty-unclean 2019-12-05 02:55:58
       os: RRG/Iceman/master/41e0bf9a-dirty-unclean 2019-12-05 02:56:11
  compiled with GCC 6.3.1 20170620

 [ FPGA ]
  LF image built for 2s30vq100 on 2019-07-31 at 15:57:16
  HF image built for 2s30vq100 on 2018-09-03 at 21:40:23  

 [ Hardware ]   
  --= uC: AT91SAM7S512 Rev A  
  --= Embedded Processor: ARM7TDMI  
  --= Nonvolatile Program Memory Size: 512K bytes, Used: 244188 bytes (47%) Free: 280100 bytes (53%)  
  --= Second Nonvolatile Program Memory Size: None  
  --= Internal SRAM Size: 64K bytes  
  --= Architecture Identifier: AT91SAM7Sxx Series  
  --= Nonvolatile Program Memory Type: Embedded Flash Memory
~~~~~~~~~~~~~~~~~~~~~

**2)  hw tune command**
~~~~~~~~~~~~~
pm3 --> hw tune
  
[=] Measuring antenna characteristics, please wait...
  
[=] You can cancel this operation by pressing the pm3 button  
..
  
[+] LF antenna: 35.12 V - 125.00 kHz  
[+] LF antenna: 30.87 V - 134.83 kHz  
[+] LF optimal: 36.11 V - 127.66 kHz  
[+] LF antenna is OK
  
[+] HF antenna: 23.33 V - 13.56 MHz  
[+] HF antenna is OK   
  
[+] Displaying LF tuning graph. Divisor 88 is 134.83 kHz, 95 is 125.00 kHz.
~~~~~~~~~~~~~~

**3)    hw status command**
~~~~~~~~~~~~~~~~
[usb] pm3 --> hw status
#db# Memory   
#db#   BIGBUF_SIZE.............40000  
#db#   Available memory........40000  
#db# Tracing   
#db#   tracing ................1  
#db#   traceLen ...............0  
#db# Currently loaded FPGA image   
#db#   mode.................... HF image built for 2s30vq100 on 2018-09-03 at 21:40:23  
#db# LF Sampling config   
#db#   [q] divisor.............95 ( 125.00 kHz )  
#db#   [b] bps.................8  
#db#   [d] decimation..........1  
#db#   [a] averaging...........Yes  
#db#   [t] trigger threshold...0  
#db#   [s] samples to skip.....0   
#db# LF T55XX config   
#db#            [r]               [a]   [b]   [c]   [d]   [e]   [f]   [g]  
#db#            mode            |start|write|write|write| read|write|write  
#db#                            | gap | gap |  0  |  1  | gap |  2  |  3  
#db# ---------------------------+-----+-----+-----+-----+-----+-----+------  
#db# fixed bit length (default) |  31 |  20 |  18 |  50 |  15 | N/A | N/A |   
#db#     long leading reference |  31 |  20 |  18 |  50 |  15 | N/A | N/A |   
#db#               leading zero |  31 |  20 |  18 |  40 |  15 | N/A | N/A |   
#db#    1 of 4 coding reference |  31 |  20 |  18 |  34 |  15 |  50 |  66 |   
#db#   
#db# Transfer Speed   
#db#   Sending packets to client...  
#db#   Time elapsed............500ms  
#db#   Bytes transferred.......326144  
#db#   Transfer Speed PM3 -> Client = 652288 bytes/s  
#db# Various   
#db#   DBGLEVEL................1  
#db#   ToSendMax...............-1  
#db#   ToSendBit...............0  
#db#   ToSend BUFFERSIZE.......2308  
#db#   Slow clock..............30858 Hz  
#db# Installed StandAlone Mode   
#db#   LF HID26 standalone - aka SamyRun (Samy Kamkar)
~~~~~~~~~~~~~~~~~~~~~~~~~

4)hf 14a info command

input the command 3 times,with the same card ,no return.(cold)
~~~~~~~~~~~~
[usb] pm3 --> hf 14a info
[usb] pm3 --> hf 14a info
[usb] pm3 --> hf 14a info
~~~~~~~~~~~~~~

(heated )input the command 1 time with the same card,return below
~~~~~~~~~~~~~~
[usb] pm3 --> hf 14a info
 UID : 84 17 25 02   
ATQA : 00 04  
 SAK : 08 [2]  
TYPE : NXP MIFARE CLASSIC 1k | Plus 2k SL1 | 1k Ev1  
[=] proprietary non iso14443-4 card found, RATS not supported  
[+] Magic capabilities : Gen 1a   
[+] Prng detection: WEAK
~~~~~~~~~~~~~~

iceman1001, 2019-12-06:
That didn't do anything. Its most likely a hw problem. Time for you to follow all lines.  I can't help you.

SDPatrick, 2019-12-06:
> That didn't do anything. Its most likely a hw problem. Time for you to follow all lines. I can't help you.

thanks all the same. time to buy a new one.  Aha...

Closed 2019-12-06.

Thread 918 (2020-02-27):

#678 breaks [hw tune] high frequency voltage readings on some platforms

0x2b3bfa0, 2020-02-27:
Since the merge of #678, the high frequency antenna voltage readings from `hw tune` are far below the values reported by older firmware versions. The device used for testing purposes was _Elechouse Proxmark3 Easy_, but this might be happening on all the non-RDV4 devices.

***

**`hw tune` high frequency readings _before_ 050aa18b13084b0d57ffcee352bf7a30b828b8f5**

```
# LF antenna: 26.12 V @   125.00 kHz
# LF antenna: 31.49 V @   134.00 kHz
# LF optimal: 33.55 V @   130.43 kHz
# HF antenna: 36.26 V @    13.56 MHz
```

**`hw tune` high frequency readings _after_ 050aa18b13084b0d57ffcee352bf7a30b828b8f5**

```
# LF antenna: 26.26 V @   125.00 kHz
# LF antenna: 31.62 V @   134.00 kHz
# LF optimal: 33.55 V @   130.43 kHz
# HF antenna:  6.24 V @    13.56 MHz
# Your HF antenna is marginal.
```

pwpiwi, 2020-03-04:
Did you rebuild the client after flashing the firmware?

0x2b3bfa0, 2020-03-10:
Yes, as far as `make clean` is able to delete the old binaries.

pwpiwi, 2020-03-16:
Sorry, but I cannot confirm the issue. I compared the most current HEAD (5bc3841) with the release before 050aa18 (which is 2758d83) on three different PM3s (Original, RDV2, RDV3 Easy). HF voltage results look OK and consistent:
```
PM3          |   5bc3841    |   2758d83
-------------+--------------------------
Original     |    22.05V    |    22.12V
RDV2         |    32.26V    |    32.47V
RDV3 Easy    |    30.91V    |    30.91V
```

0x2b3bfa0, 2020-03-16:
I've bought my PM3 Easy (blue circuit board) on AliExpress, and chances are that it was a knockoff. I've sent it back to the seller for a full refund, just in case it was a hardware issue, and I'll repeat the tests after getting a new device.

What a strange issue!

Closed 2020-04-07.

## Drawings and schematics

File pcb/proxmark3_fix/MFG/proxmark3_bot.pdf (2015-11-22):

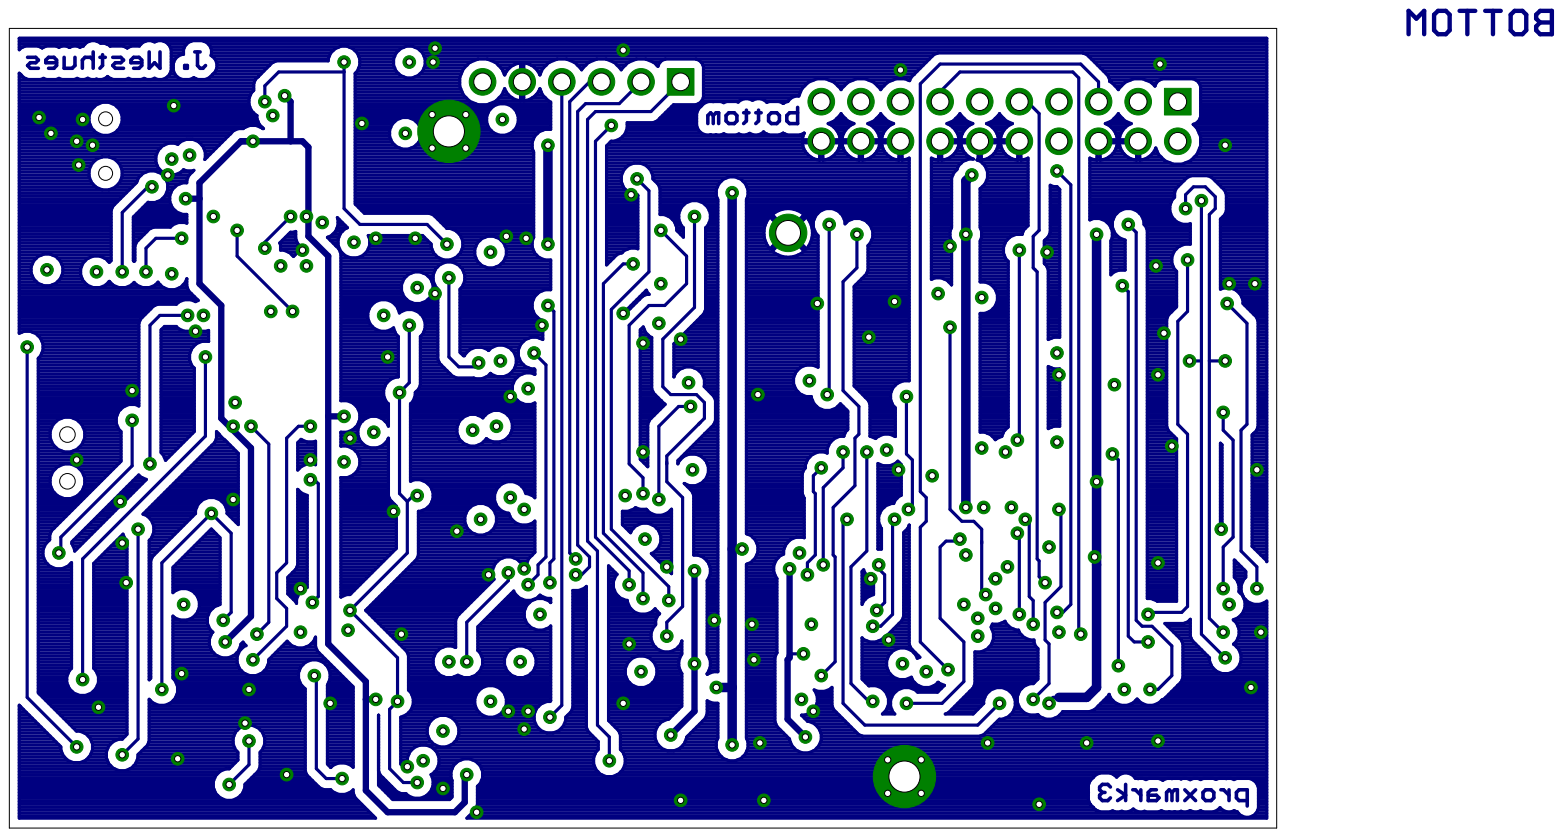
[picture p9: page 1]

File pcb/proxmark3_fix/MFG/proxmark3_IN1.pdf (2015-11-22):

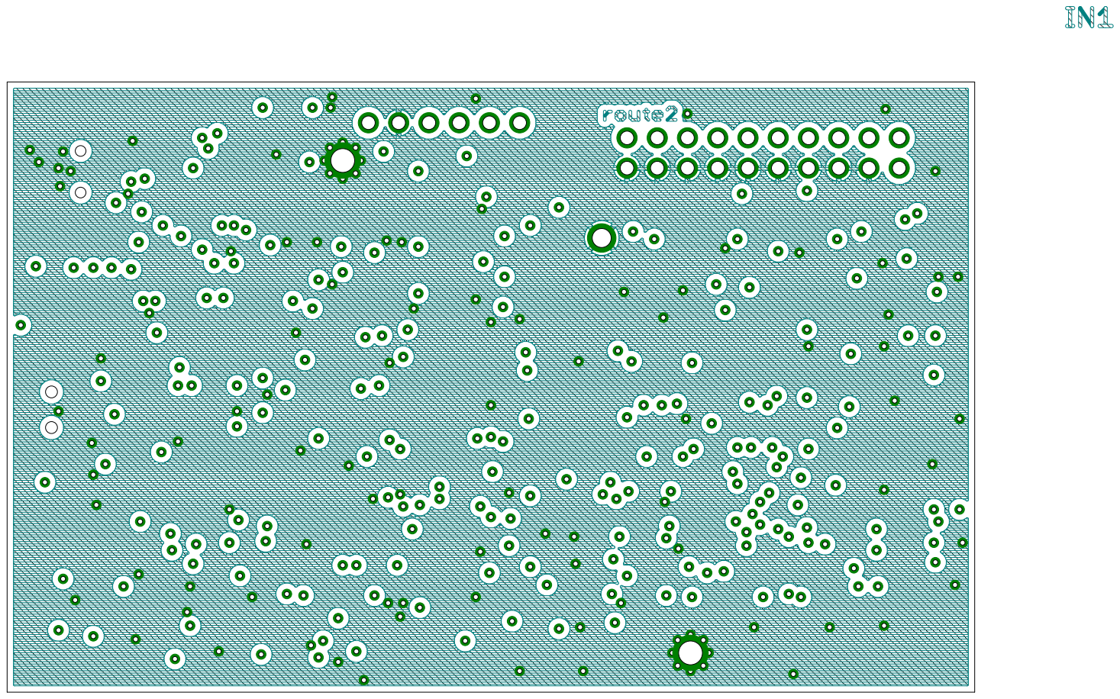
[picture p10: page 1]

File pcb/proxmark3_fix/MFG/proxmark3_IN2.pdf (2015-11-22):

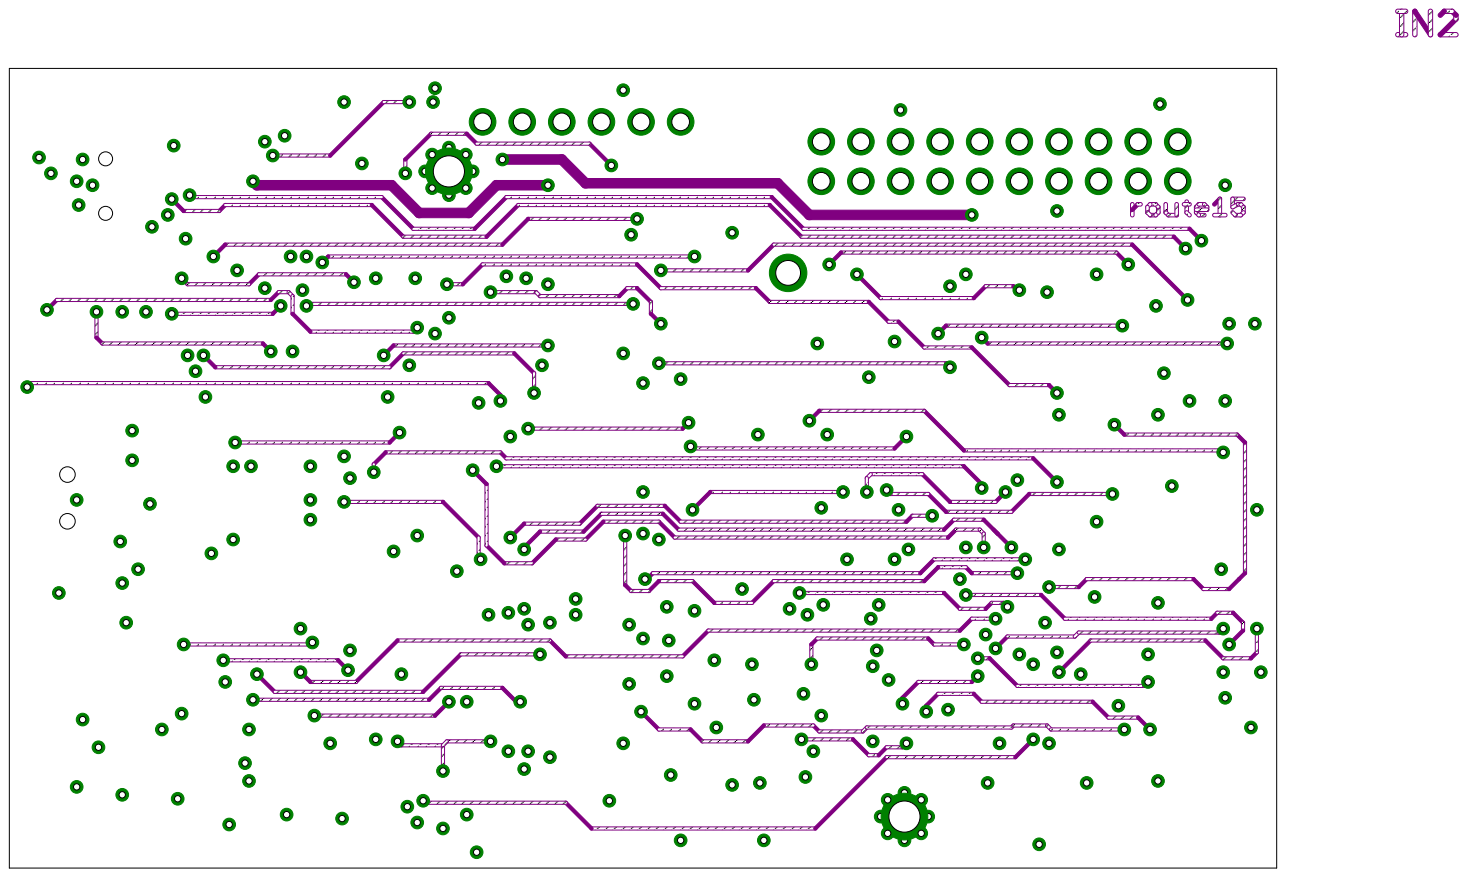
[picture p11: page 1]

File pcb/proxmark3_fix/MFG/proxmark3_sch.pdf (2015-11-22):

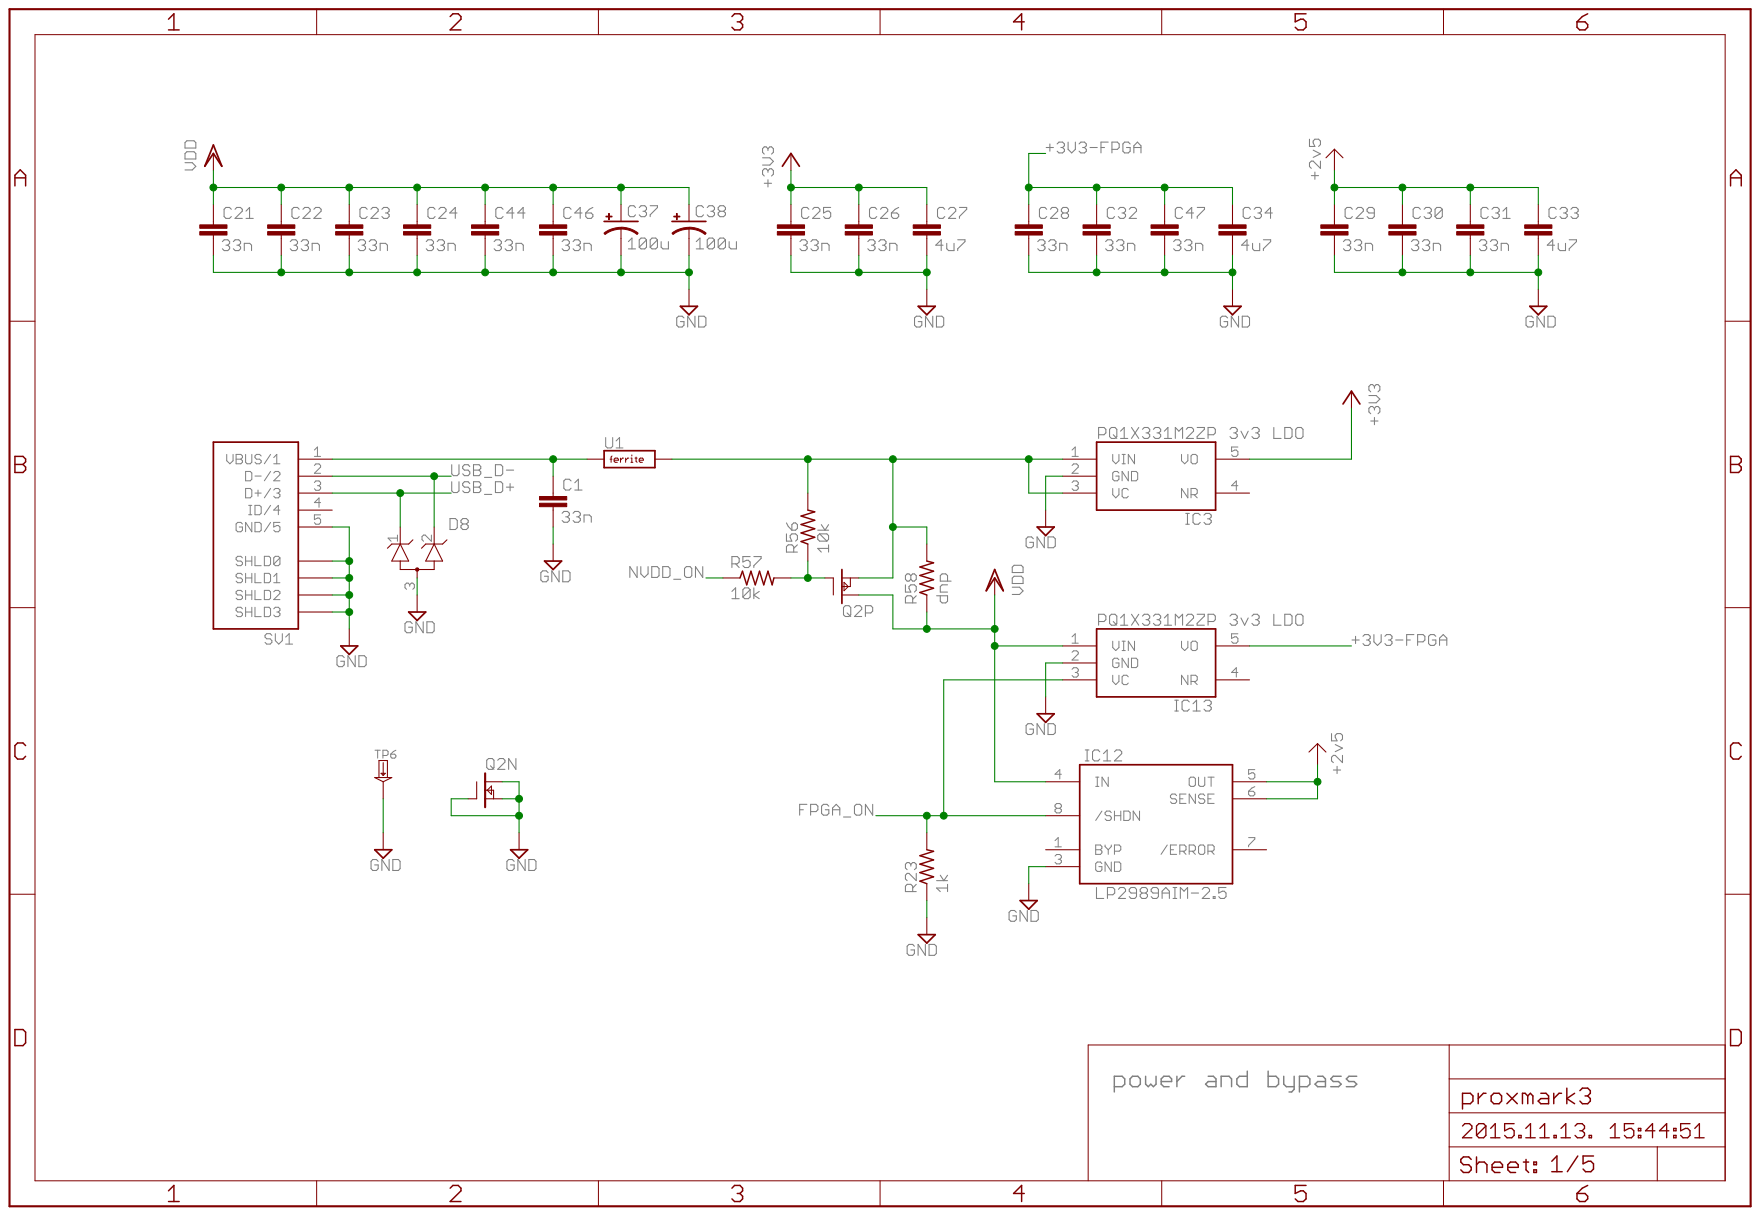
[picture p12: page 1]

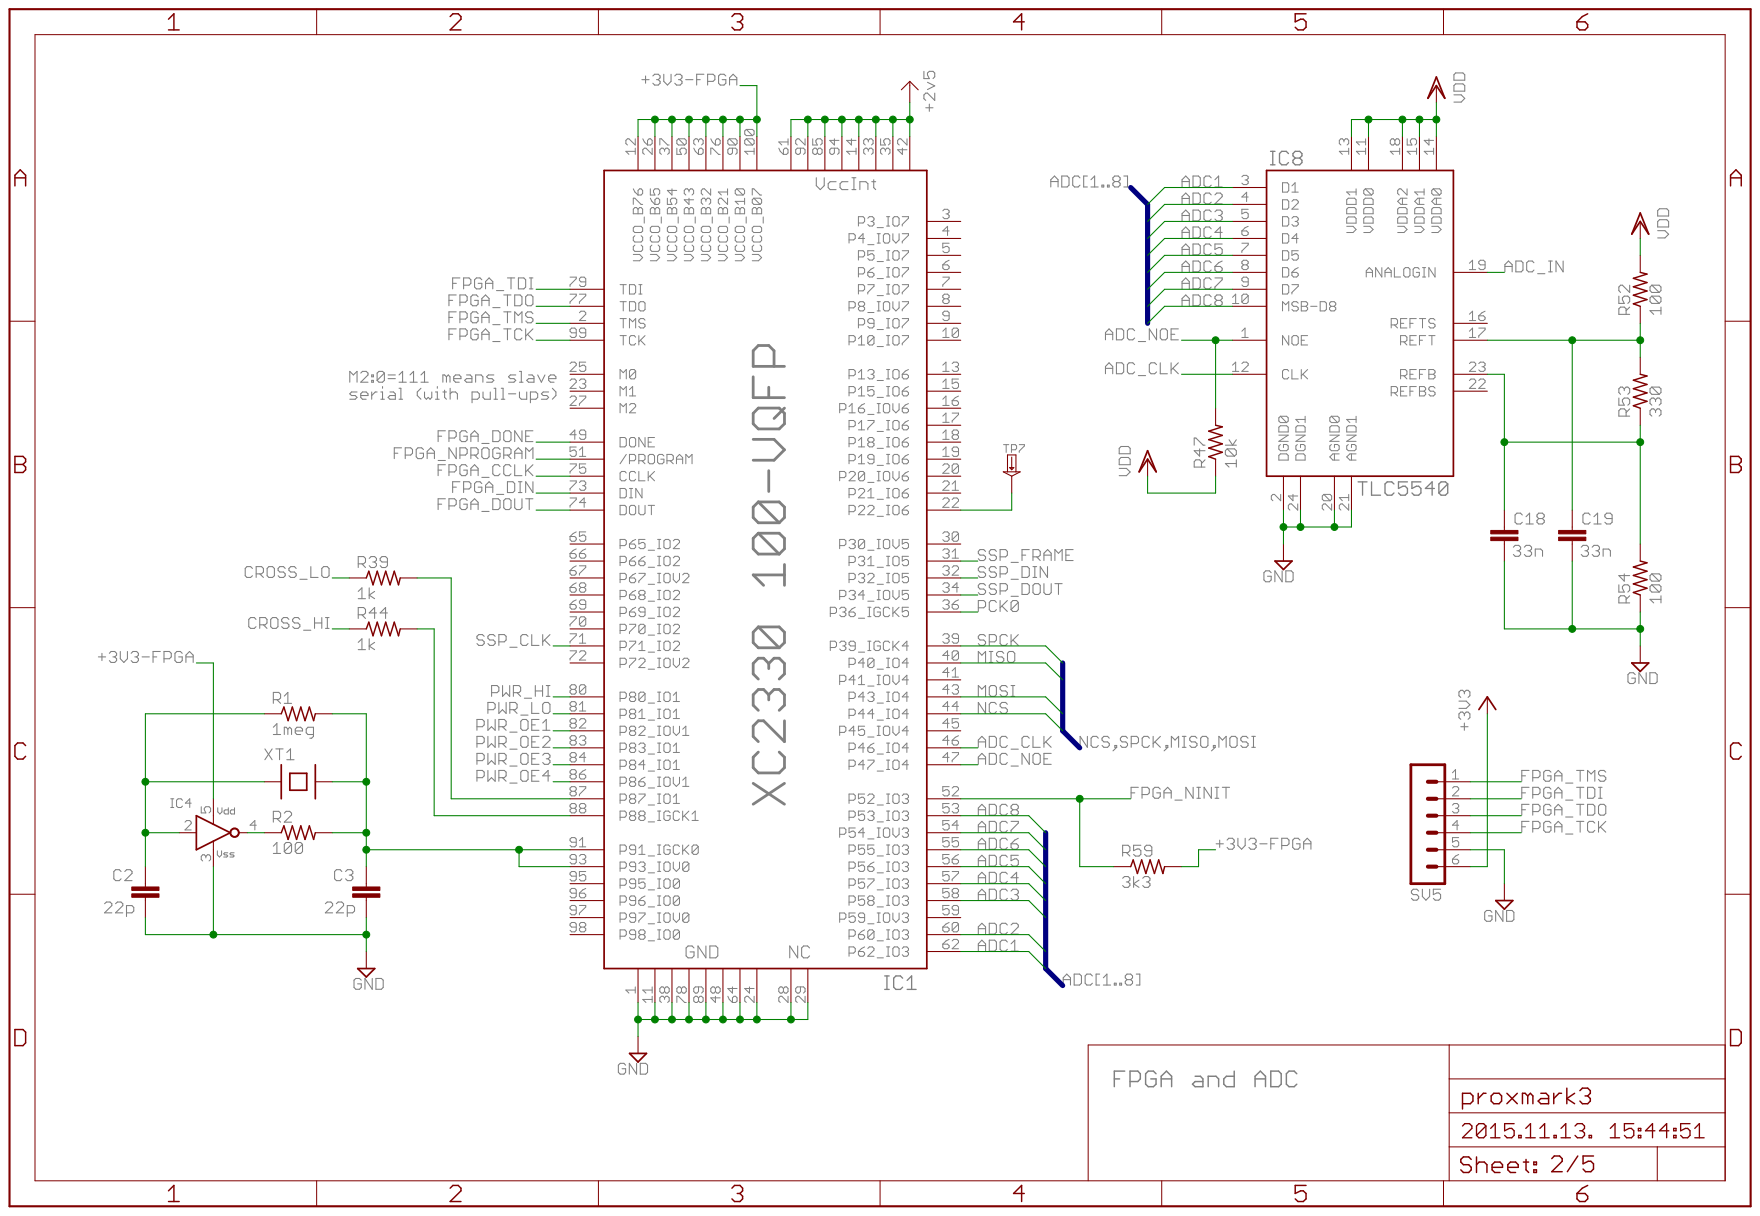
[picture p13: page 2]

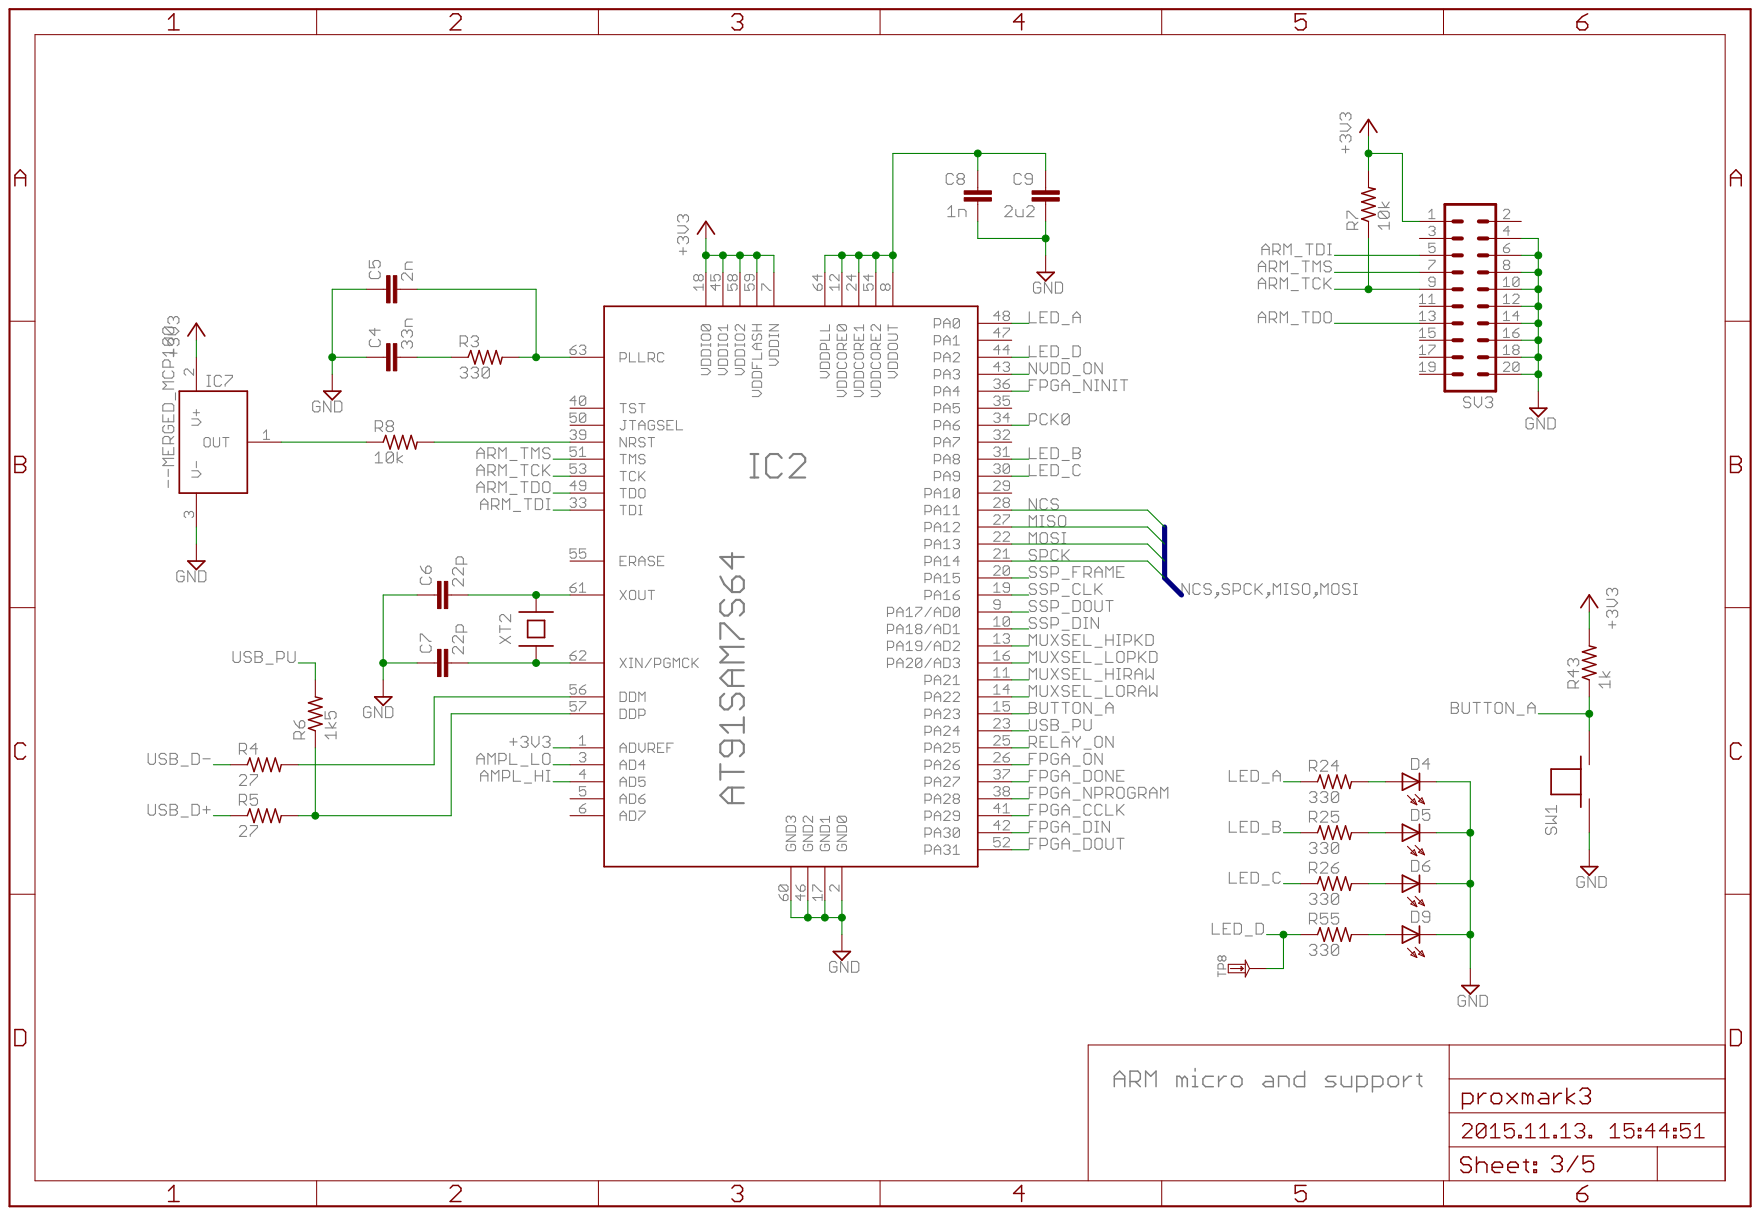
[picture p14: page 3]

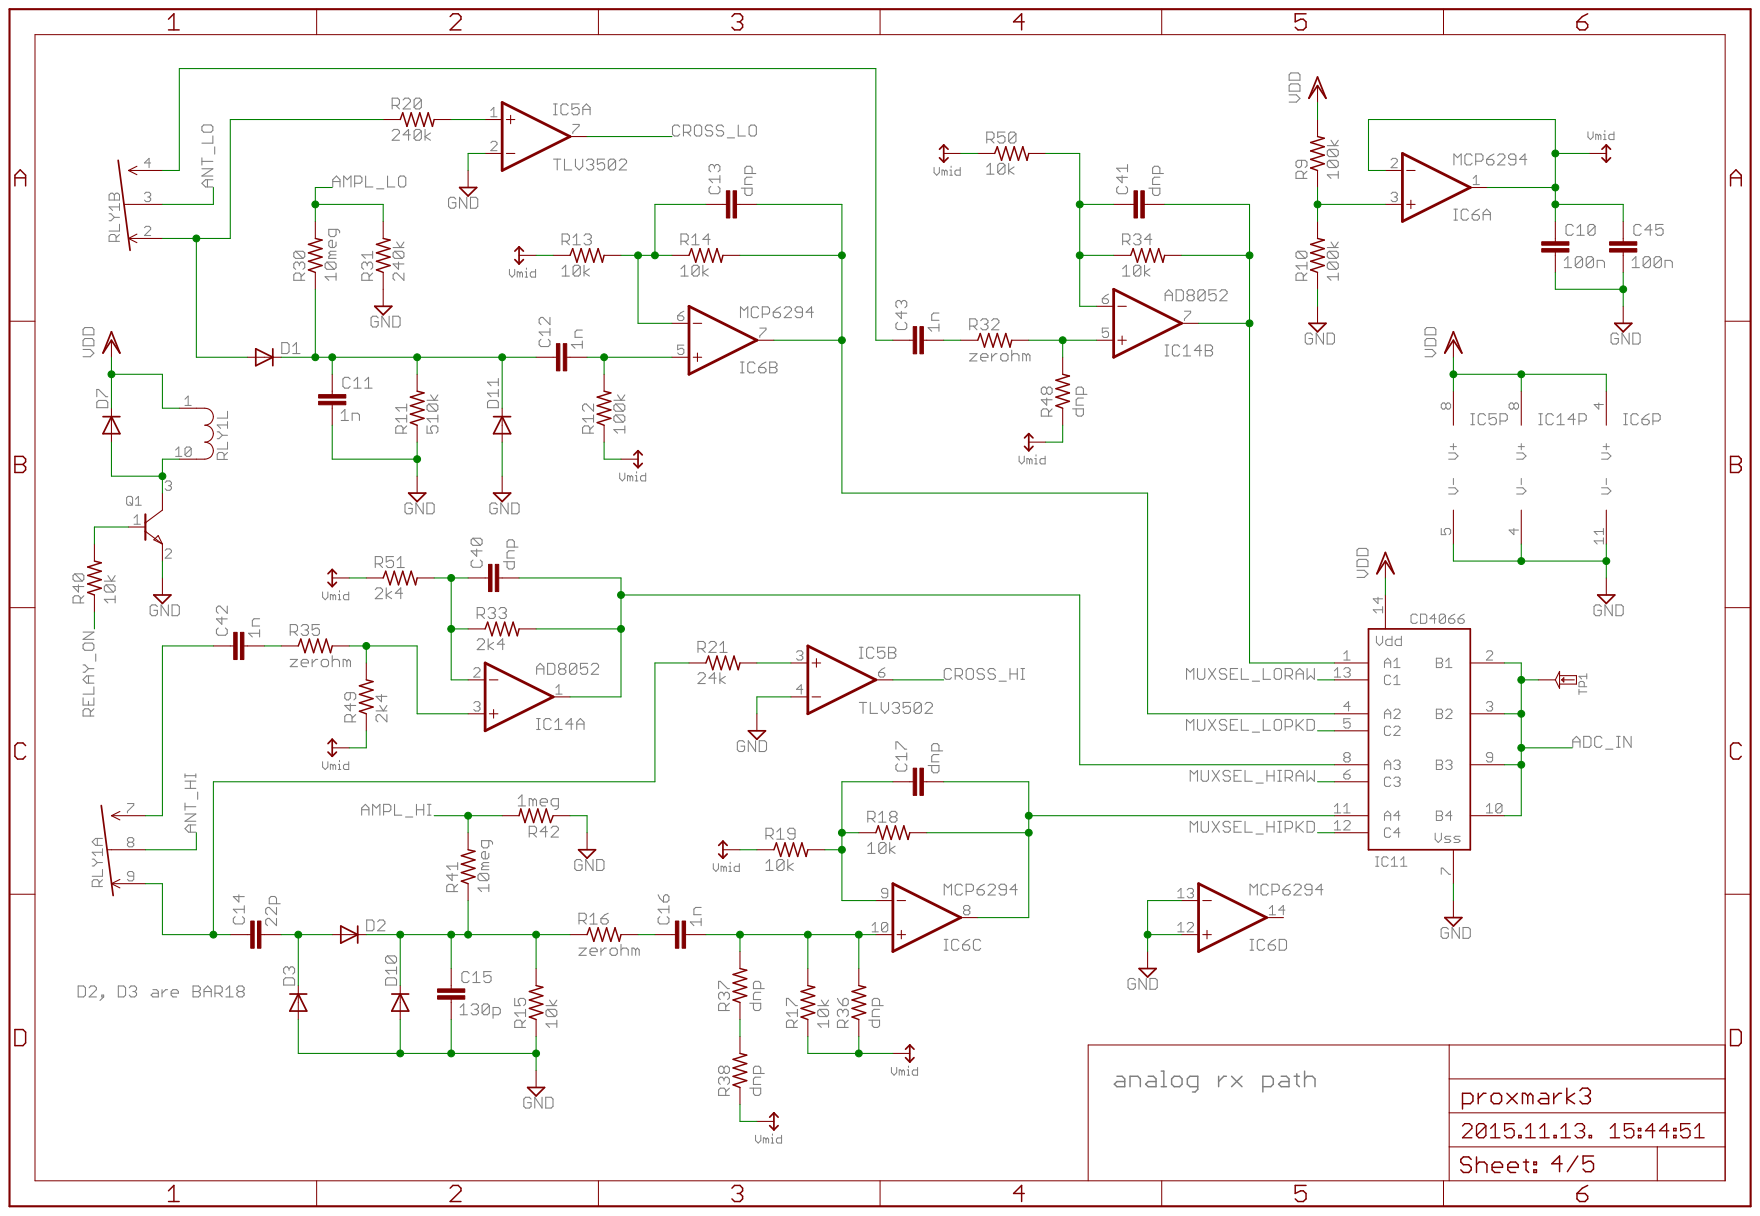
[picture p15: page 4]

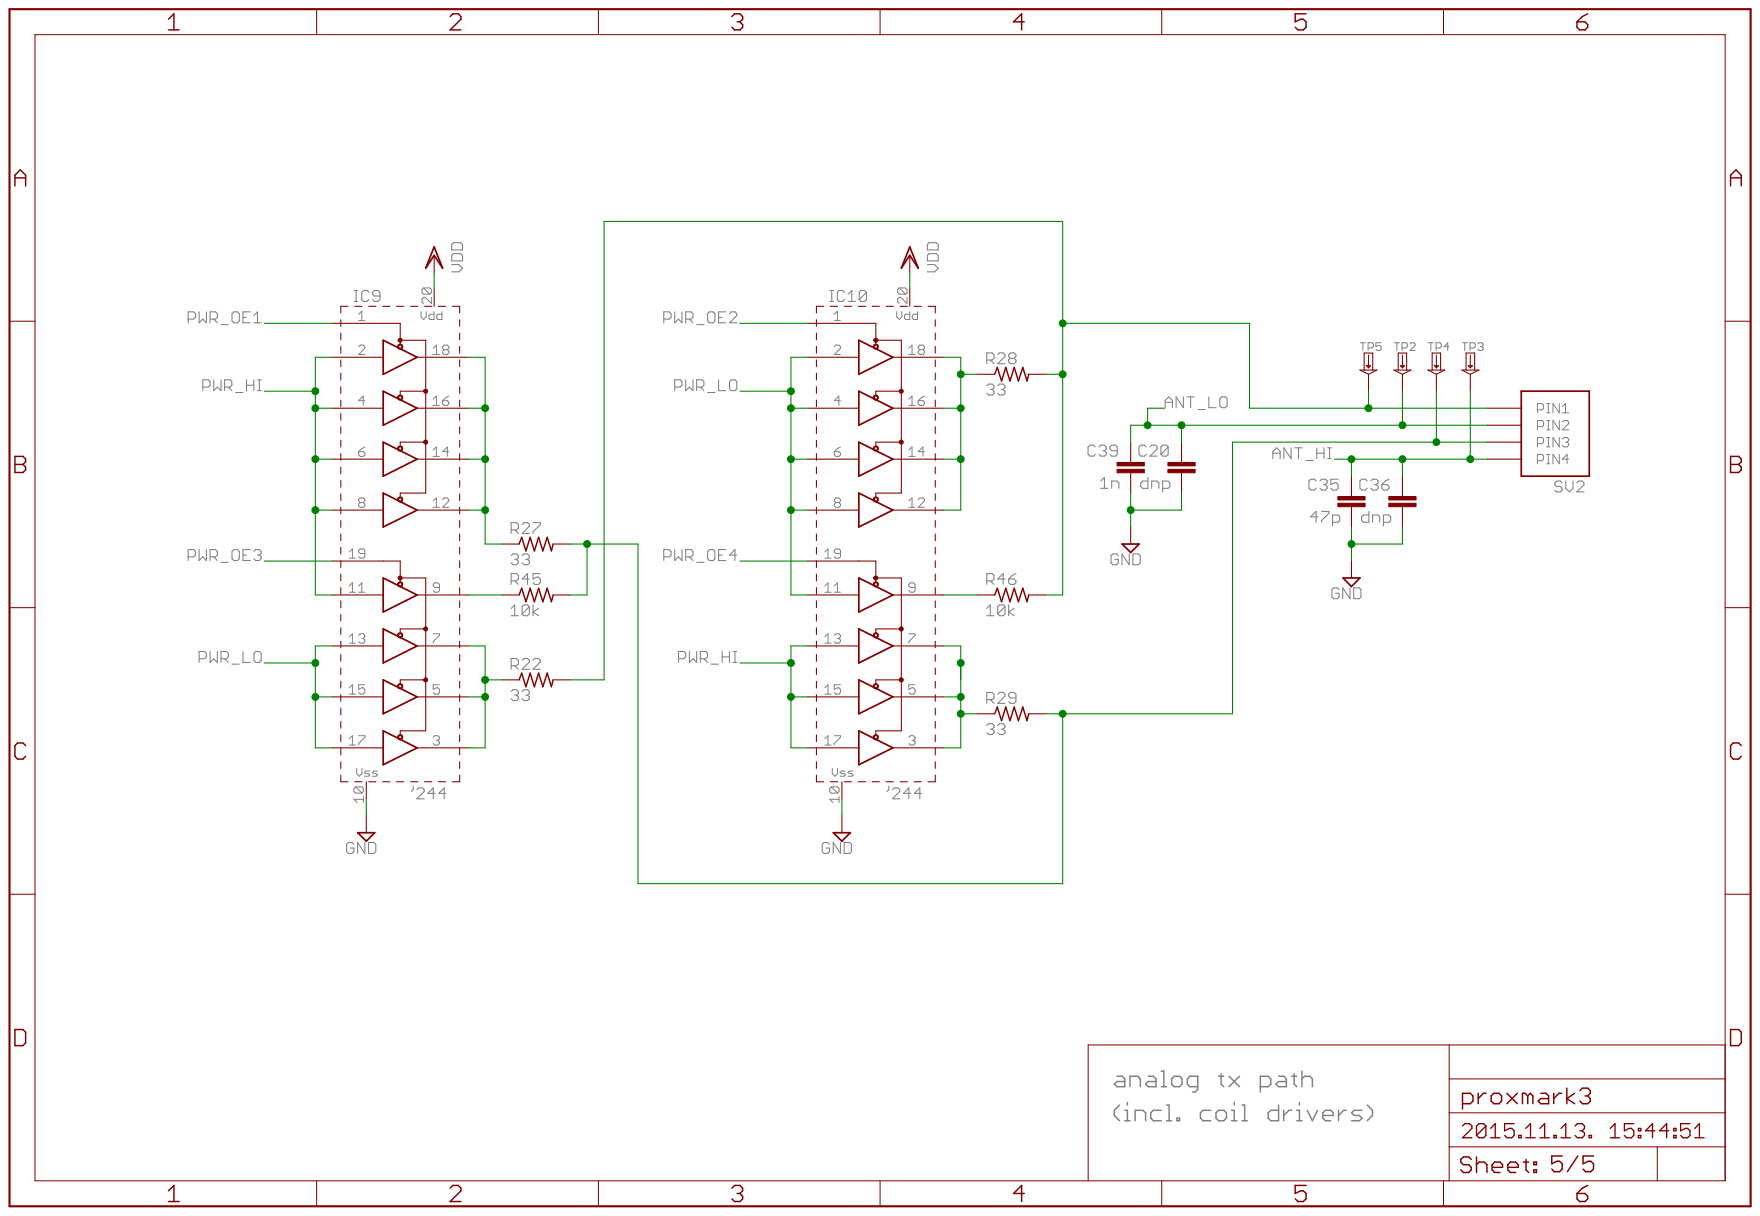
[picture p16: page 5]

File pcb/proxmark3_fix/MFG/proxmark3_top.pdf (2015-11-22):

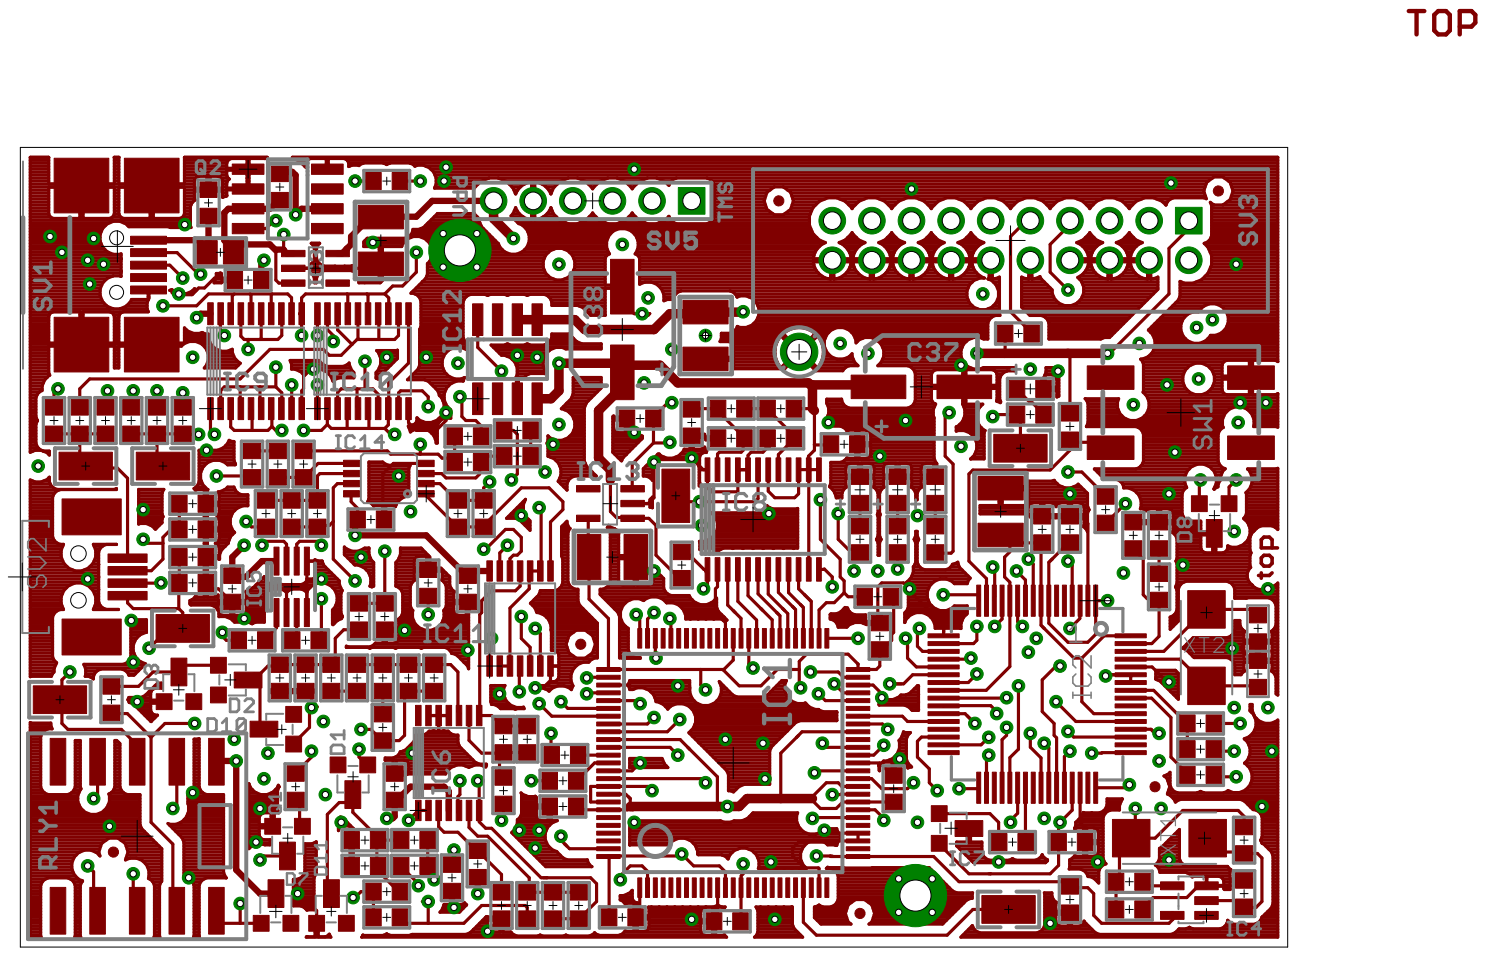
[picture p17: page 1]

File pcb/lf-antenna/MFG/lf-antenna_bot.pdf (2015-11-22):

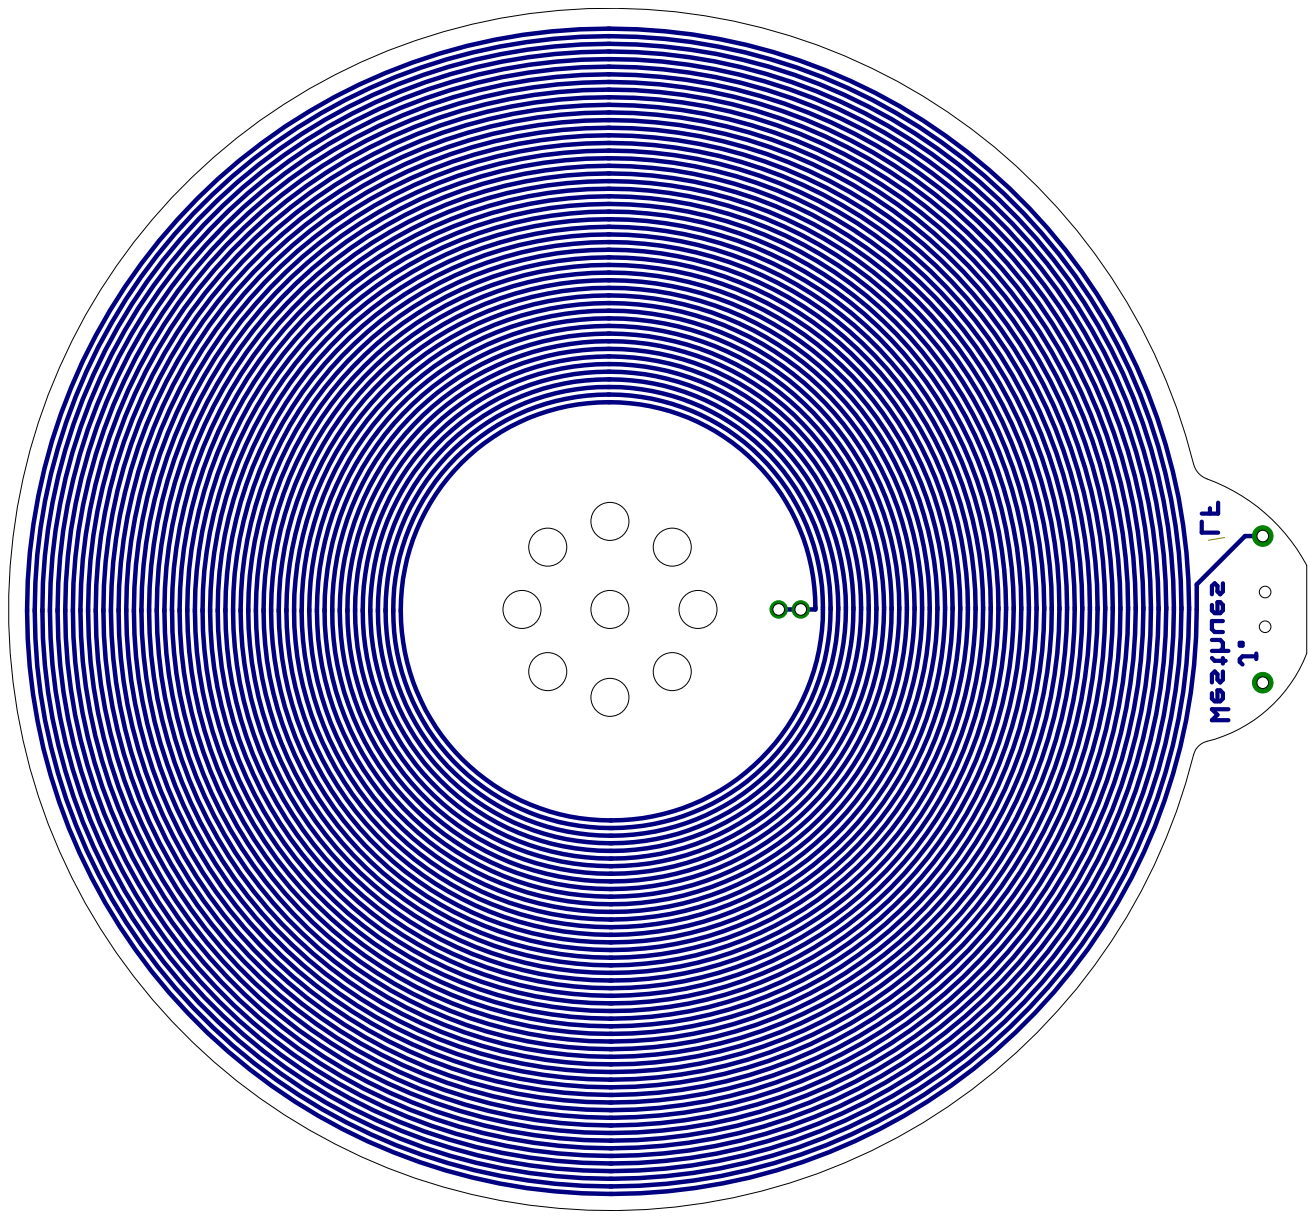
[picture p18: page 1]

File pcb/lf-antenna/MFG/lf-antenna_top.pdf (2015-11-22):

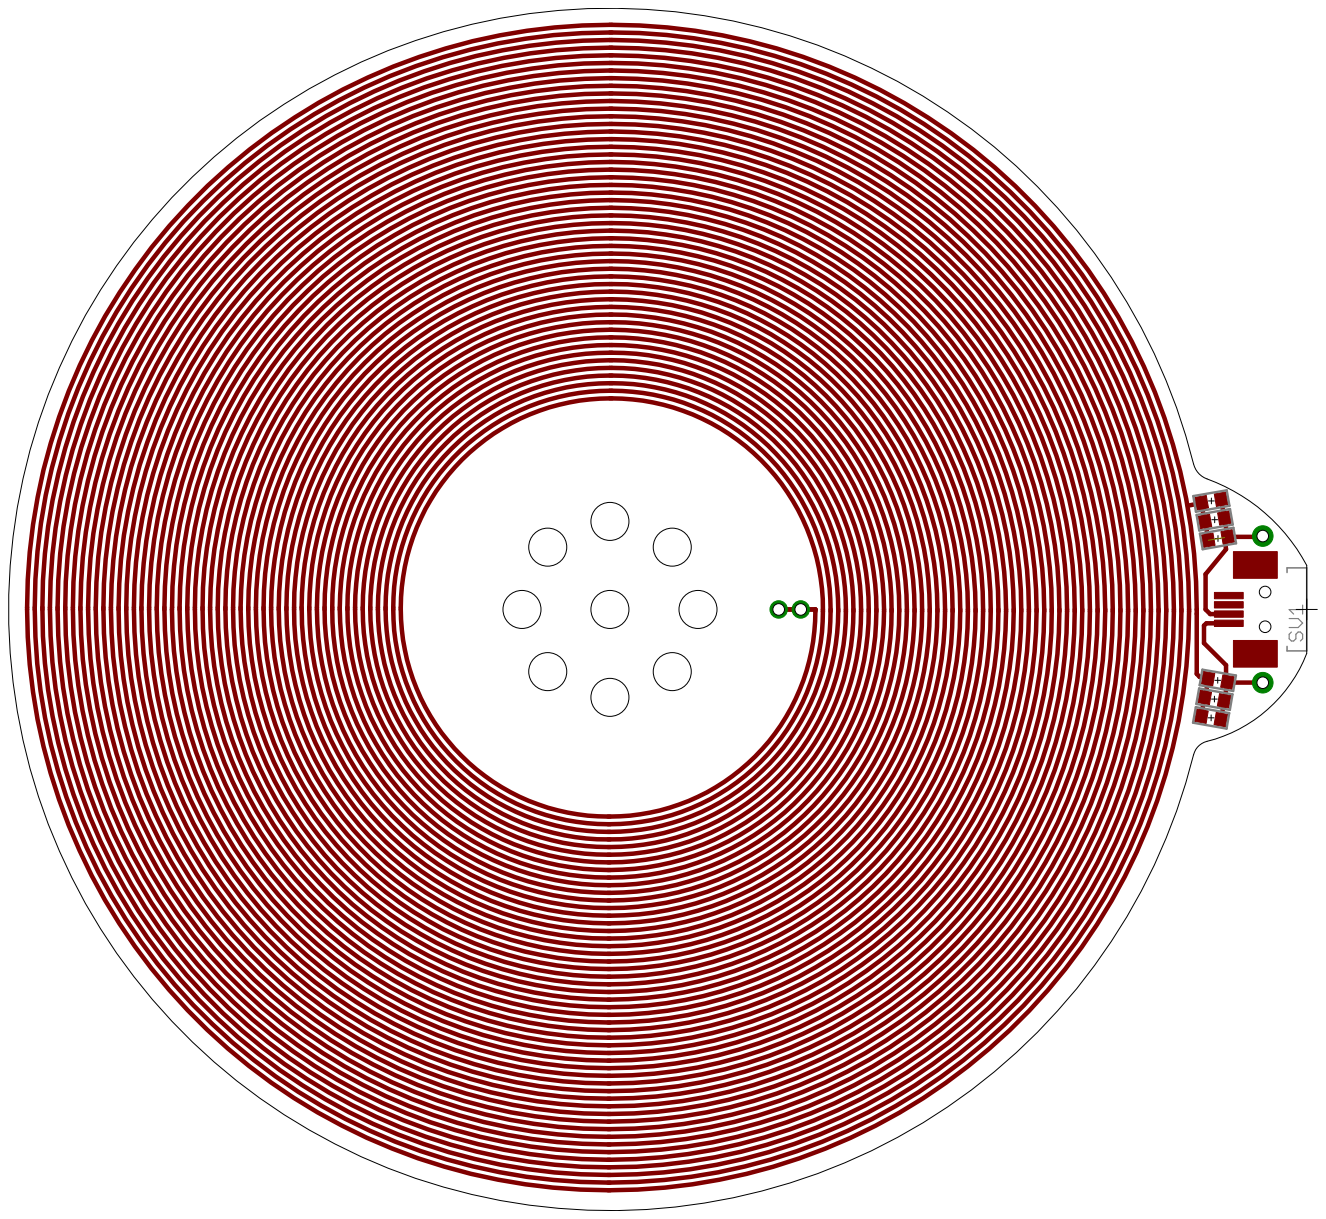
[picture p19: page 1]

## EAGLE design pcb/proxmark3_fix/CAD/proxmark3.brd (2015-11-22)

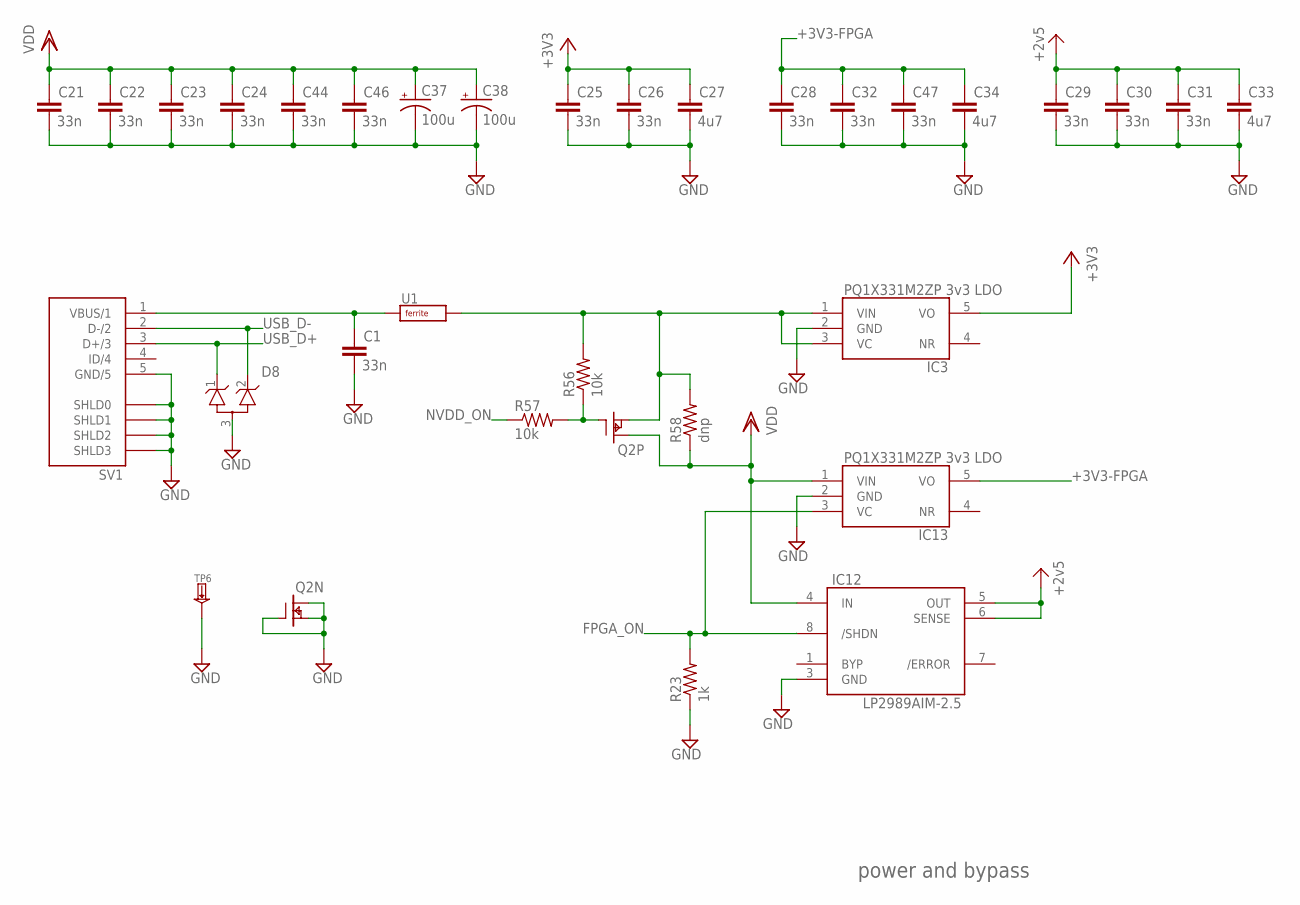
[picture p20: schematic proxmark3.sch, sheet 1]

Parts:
C1, C21, C22, C23, C24, C25, C26, C28, C29, C30, C31, C32, C44, C46, C47: 33n; RLC_0603
C27, C33, C34: 4u7; RLC_1210
C37, C38: 100u; CAPCAITOR-ELECTROLYTIC-ALCHIP-MZA-F80
D8: --MERGED_DUAL-TVS-COMMON-ANODE; --MERGED_SOT23-3LEAD
IC3, IC13: --MERGED_PQ1X331M2ZP-3V3-LDO-SOT-23-5; --MERGED_SOT-23-5
IC12: LP2989AIM-2.5; SOIC-8
Q2: IRF7307; SOIC-8
R23: 1k; RLC_0603
R56, R57: 10k; RLC_0603
R58: dnp; RLC_0603
SV1: USB-MINIB; USB-MINIB-SMD
TP6: TESTPADKEYSTONE-PTH; KEYSTONE-PTH-TESTPOINT-5011
U1: FERRITE0805; RLC_0805

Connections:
+2V5: C29.1, C30.1, C31.1, C33.1, IC12.5 (OUT), IC12.6 (SENSE); also elsewhere on the board
+3V3: C25.1, C26.1, C27.1, IC3.5 (VO); also elsewhere on the board
+3V3-FPGA: C28.1, C32.1, C34.1, C47.1, IC13.5 (VO); also elsewhere on the board
FPGA_ON: IC12.8 (/SHDN), IC13.3 (VC), R23.2; also elsewhere on the board
GND: C1.2, C21.2, C22.2, C23.2, C24.2, C25.2, C26.2, C27.2, C28.2, C29.2, C30.2, C31.2, C32.2, C33.2, C34.2, C37.-, C38.-, C44.2, C46.2, C47.2, D8.3 (A), IC3.2 (GND), IC12.3 (GND), IC13.2 (GND), Q2.1 (S), Q2.2 (G), Q2.8 (D), R23.1, SV1.5 (GND/5), SV1.TAB0 (SHLD0), SV1.TAB1 (SHLD1), SV1.TAB2 (SHLD2), SV1.TAB3 (SHLD3), TP6.A; also elsewhere on the board
unnamed: C1.1, SV1.1 (VBUS/1), U1.1 (A)
unnamed: IC3.1 (VIN), IC3.3 (VC), Q2.3 (S), R56.2, R58.2, U1.2 (B)
NVDD_ON: R57.1; also elsewhere on the board
PFETGATE: Q2.4 (G), R56.1, R57.2
USB_D+: D8.1 (K1), SV1.3 (D+/3); also elsewhere on the board
USB_D-: D8.2 (K2), SV1.2 (D-/2); also elsewhere on the board
VDD: C21.1, C22.1, C23.1, C24.1, C37.+, C38.+, C44.1, C46.1, IC12.4 (IN), IC13.1 (VIN), Q2.6 (D), R58.1; also elsewhere on the board

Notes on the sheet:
power and bypass

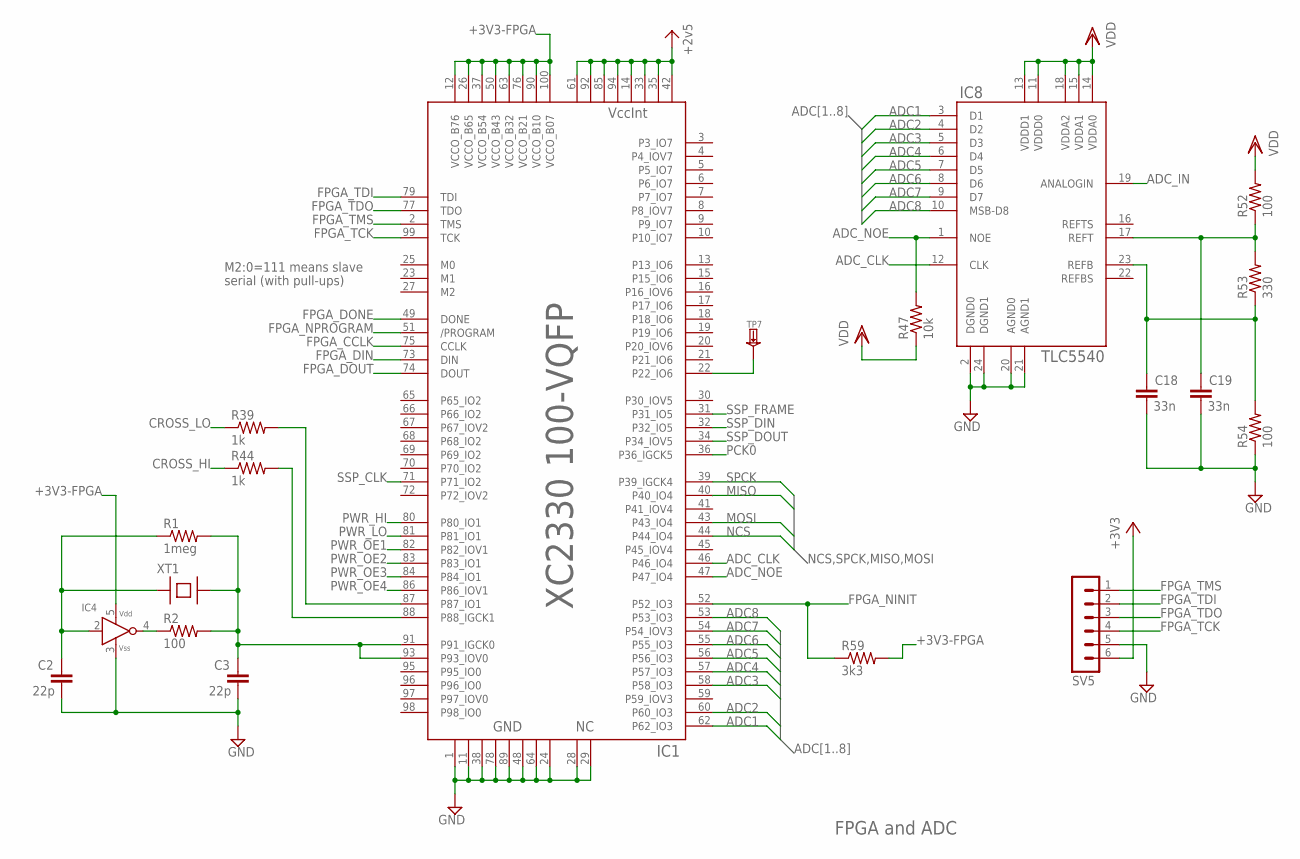
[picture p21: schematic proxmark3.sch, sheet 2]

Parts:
C2, C3: 22p; RLC_0603
C18, C19: 33n; RLC_0603
IC1: SPARTAN-II-XC2S30-100-VQFP; VQFP-100
IC4: HCU-INVERTER; SMV-5
IC8: TLC5540; TSSOP-24
R1: 1meg; RLC_0603
R2, R52, R54: 100; RLC_0603
R39, R44: 1k; RLC_0603
R47: 10k; RLC_0603
R53: 330; RLC_0603
R59: 3k3; RLC_0603
SV5: --MERGED_HEADER-MALE-6X1; --MERGED_HEADER-MALE-6X1-0.100-UNKEYED
TP7: TESTPADKEYSTONE-SMD; KEYSTONE-SMD-TESTPOINT-5015
XT1: XTAL-SMD-CITIZEN-CS10

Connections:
+2V5: IC1.14 (VCCINT5), IC1.33 (VCCINT6), IC1.35 (VCCINT7), IC1.42 (VCCINT8), IC1.61 (VCCINT1), IC1.85 (VCCINT3), IC1.92 (VCCINT2), IC1.94 (VCCINT4); also elsewhere on the board
+3V3: SV5.6; also elsewhere on the board
+3V3-FPGA: IC1.12 (VCCO_B76), IC1.26 (VCCO_B65), IC1.37 (VCCO_B54), IC1.50 (VCCO_B43), IC1.63 (VCCO_B32), IC1.76 (VCCO_B21), IC1.90 (VCCO_B10), IC1.100 (VCCO_B07), IC4.5 (VDD), R59.2; also elsewhere on the board
ADC1: IC1.62 (P62_IO3), IC8.3 (D1)
ADC2: IC1.60 (P60_IO3), IC8.4 (D2)
ADC3: IC1.58 (P58_IO3), IC8.5 (D3)
ADC4: IC1.57 (P57_IO3), IC8.6 (D4)
ADC5: IC1.56 (P56_IO3), IC8.7 (D5)
ADC6: IC1.55 (P55_IO3), IC8.8 (D6)
ADC7: IC1.54 (P54_IOV3), IC8.9 (D7)
ADC8: IC1.53 (P53_IO3), IC8.10 (MSB-D8)
ADC_CLK: IC1.46 (P46_IO4), IC8.12 (CLK)
ADC_IN: IC8.19 (ANALOGIN); also elsewhere on the board
ADC_NOE: IC1.47 (P47_IO4), IC8.1 (NOE), R47.2
CROSS_HI: R44.1; also elsewhere on the board
CROSS_LO: R39.1; also elsewhere on the board
FPGA_CCLK: IC1.75 (CCLK); also elsewhere on the board
FPGA_DIN: IC1.73 (DIN); also elsewhere on the board
FPGA_DONE: IC1.49 (DONE); also elsewhere on the board
FPGA_DOUT: IC1.74 (DOUT); also elsewhere on the board
FPGA_NINIT: IC1.52 (P52_IO3), R59.1; also elsewhere on the board
FPGA_NPROGRAM: IC1.51 (/PROGRAM); also elsewhere on the board
FPGA_TCK: IC1.99 (TCK), SV5.4
FPGA_TDI: IC1.79 (TDI), SV5.2
FPGA_TDO: IC1.77 (TDO), SV5.3
FPGA_TMS: IC1.2 (TMS), SV5.1
GND: C2.2, C3.2, C18.2, C19.2, IC1.1 (GND1), IC1.11 (GND2), IC1.24 (GND8), IC1.28 (NC0), IC1.29 (NC1), IC1.38 (GND3), IC1.48 (GND6), IC1.64 (GND7), IC1.78 (GND4), IC1.89 (GND5), IC4.3 (VSS), IC8.2 (DGND0), IC8.20 (AGND0), IC8.21 (AGND1), IC8.24 (DGND1), R54.1, SV5.5; also elsewhere on the board
MISO: IC1.40 (P40_IO4); also elsewhere on the board
MOSI: IC1.43 (P43_IO4); also elsewhere on the board
unnamed: IC4.4 (Y), R2.1
unnamed: C2.1, IC4.2 (A), R1.1, XT1.A
unnamed: C3.1, IC1.91 (P91_IGCK0), IC1.93 (P93_IOV0), R1.2, R2.2, XT1.B
unnamed: C18.1, IC8.23 (REFB), R53.1, R54.2
unnamed: IC1.87 (P87_IO1), R39.2
unnamed: IC1.88 (P88_IGCK1), R44.2
unnamed: C19.1, IC8.17 (REFT), R52.1, R53.2
unnamed: IC1.22 (P22_IO6), TP7.1
NCS: IC1.44 (P44_IO4); also elsewhere on the board
PCK0: IC1.36 (P36_IGCK5); also elsewhere on the board
PWR_HI: IC1.80 (P80_IO1); also elsewhere on the board
PWR_LO: IC1.81 (P81_IO1); also elsewhere on the board
PWR_OE1: IC1.82 (P82_IOV1); also elsewhere on the board
PWR_OE2: IC1.83 (P83_IO1); also elsewhere on the board
PWR_OE3: IC1.84 (P84_IO1); also elsewhere on the board
PWR_OE4: IC1.86 (P86_IOV1); also elsewhere on the board
SPCK: IC1.39 (P39_IGCK4); also elsewhere on the board
SSP_CLK: IC1.71 (P71_IO2); also elsewhere on the board
SSP_DIN: IC1.32 (P32_IO5); also elsewhere on the board
SSP_DOUT: IC1.34 (P34_IOV5); also elsewhere on the board
SSP_FRAME: IC1.31 (P31_IO5); also elsewhere on the board
VDD: IC8.11 (VDDD0), IC8.13 (VDDD1), IC8.14 (VDDA0), IC8.15 (VDDA1), IC8.18 (VDDA2), R47.1, R52.2; also elsewhere on the board

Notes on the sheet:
FPGA and ADC
M2:0=111 means slave
serial (with pull-ups)

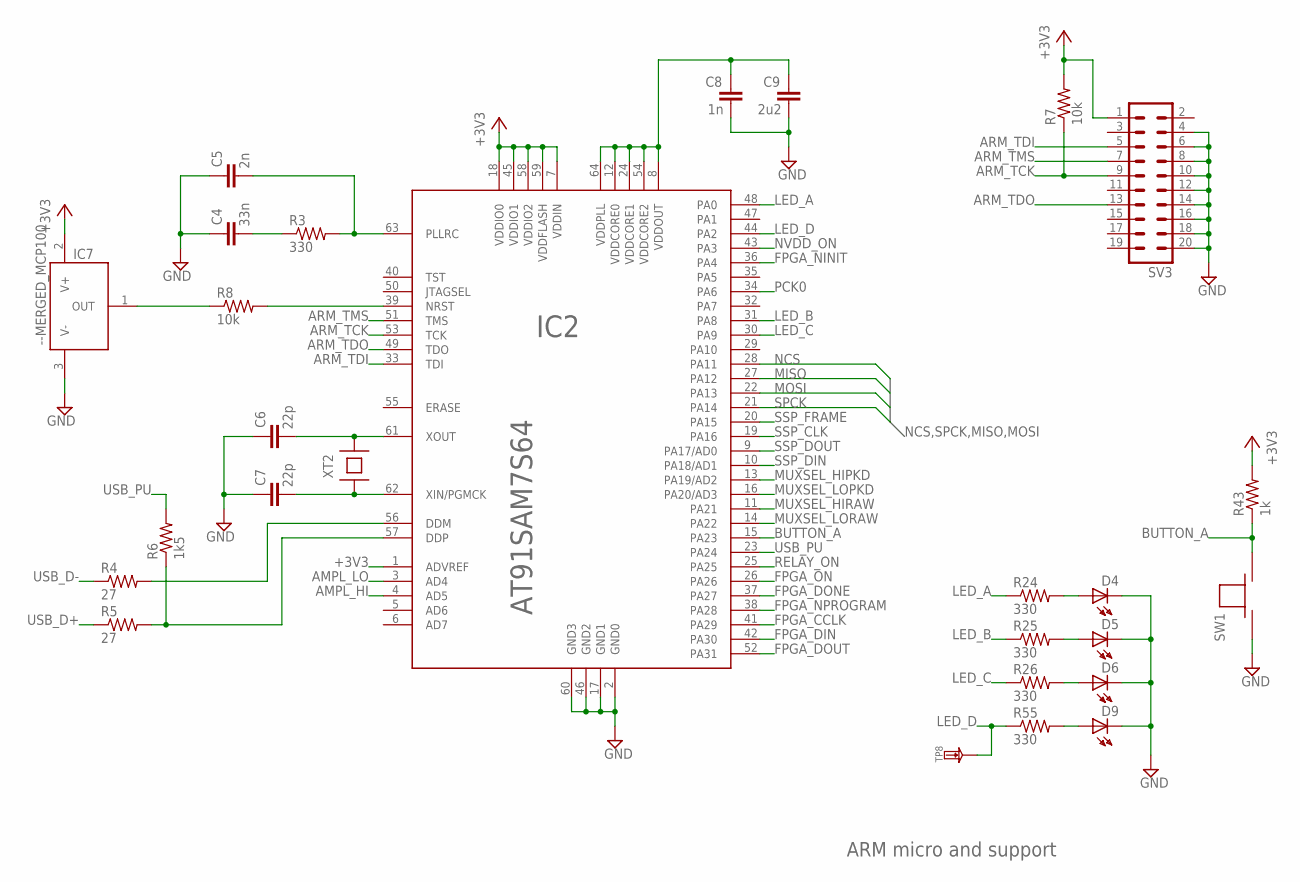
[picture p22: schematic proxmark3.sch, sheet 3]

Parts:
C4: 33n; RLC_0603
C5: 2n; RLC_0603
C6, C7: 22p; --MERGED_RLC_0603
C8: 1n; RLC_0603
C9: 2u2; RLC_1210
D4, D5, D6, D9: LED; LED_0603
IC2: AT91SAM7S64; LQFP-64
IC7: --MERGED_MCP100; --MERGED_SOT23-3LEAD
R3, R24, R25, R26, R55: 330; RLC_0603
R4, R5: 27; RLC_0603
R6: 1k5; RLC_0603
R7, R8: 10k; RLC_0603
R43: 1k; RLC_0603
SV3: HEADER-MALE-10X2; HEADER-MALE-10X2-0.100-SHROUDED
SW1: TACTSWITCH; TACTSWITCH-SMD-EVQQ1
TP8: TESTPADKEYSTONE-SMD; KEYSTONE-SMD-TESTPOINT-5015
XT2: XTAL-SMD-CITIZEN-CS10

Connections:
+3V3: IC2.1 (ADVREF), IC2.7 (VDDIN), IC2.18 (VDDIO0), IC2.45 (VDDIO1), IC2.58 (VDDIO2), IC2.59 (VDDFLASH), IC7.2 (V+), R7.2, R43.2, SV3.1; also elsewhere on the board
AMPL_HI: IC2.4 (AD5); also elsewhere on the board
AMPL_LO: IC2.3 (AD4); also elsewhere on the board
ARM_TCK: IC2.53 (TCK), R7.1, SV3.9
ARM_TDI: IC2.33 (TDI), SV3.5
ARM_TDO: IC2.49 (TDO), SV3.13
ARM_TMS: IC2.51 (TMS), SV3.7
BUTTON_A: IC2.15 (PA23), R43.1, SW1.B
FPGA_CCLK: IC2.41 (PA29); also elsewhere on the board
FPGA_DIN: IC2.42 (PA30); also elsewhere on the board
FPGA_DONE: IC2.37 (PA27); also elsewhere on the board
FPGA_DOUT: IC2.52 (PA31); also elsewhere on the board
FPGA_NINIT: IC2.36 (PA4); also elsewhere on the board
FPGA_NPROGRAM: IC2.38 (PA28); also elsewhere on the board
FPGA_ON: IC2.26 (PA26); also elsewhere on the board
GND: C4.1, C5.1, C6.1, C7.1, C8.2, C9.2, D4.- (C), D5.- (C), D6.- (C), D9.- (C), IC2.2 (GND0), IC2.17 (GND1), IC2.46 (GND2), IC2.60 (GND3), IC7.3 (V-), SV3.4, SV3.6, SV3.8, SV3.10, SV3.12, SV3.14, SV3.16, SV3.18, SV3.20, SW1.A; also elsewhere on the board
LED_A: IC2.48 (PA0), R24.1
LED_B: IC2.31 (PA8), R25.1
LED_C: IC2.30 (PA9), R26.1
LED_D: IC2.44 (PA2), R55.1, TP8.1
MISO: IC2.27 (PA12); also elsewhere on the board
MOSI: IC2.22 (PA13); also elsewhere on the board
MUXSEL_HIPKD: IC2.13 (PA19/AD2); also elsewhere on the board
MUXSEL_HIRAW: IC2.11 (PA21); also elsewhere on the board
MUXSEL_LOPKD: IC2.16 (PA20/AD3); also elsewhere on the board
MUXSEL_LORAW: IC2.14 (PA22); also elsewhere on the board
unnamed: C5.2, IC2.63 (PLLRC), R3.2
unnamed: C4.2, R3.1
unnamed: C6.2, IC2.61 (XOUT), XT2.B
unnamed: C7.2, IC2.62 (XIN/PGMCK), XT2.A
unnamed: IC2.39 (NRST), R8.2
unnamed: C8.1, C9.1, IC2.8 (VDDOUT), IC2.12 (VDDCORE0), IC2.24 (VDDCORE1), IC2.54 (VDDCORE2), IC2.64 (VDDPLL)
unnamed: IC2.56 (DDM), R4.2
unnamed: IC2.57 (DDP), R5.2, R6.1
unnamed: IC7.1 (OUT), R8.1
unnamed: D9.+ (A), R55.2
unnamed: D6.+ (A), R26.2
unnamed: D5.+ (A), R25.2
unnamed: D4.+ (A), R24.2
NCS: IC2.28 (PA11); also elsewhere on the board
NVDD_ON: IC2.43 (PA3); also elsewhere on the board
PCK0: IC2.34 (PA6); also elsewhere on the board
RELAY_ON: IC2.25 (PA25); also elsewhere on the board
SPCK: IC2.21 (PA14); also elsewhere on the board
SSP_CLK: IC2.19 (PA16); also elsewhere on the board
SSP_DIN: IC2.10 (PA18/AD1); also elsewhere on the board
SSP_DOUT: IC2.9 (PA17/AD0); also elsewhere on the board
SSP_FRAME: IC2.20 (PA15); also elsewhere on the board
USB_D+: R5.1; also elsewhere on the board
USB_D-: R4.1; also elsewhere on the board
USB_PU: IC2.23 (PA24), R6.2

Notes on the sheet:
ARM micro and support

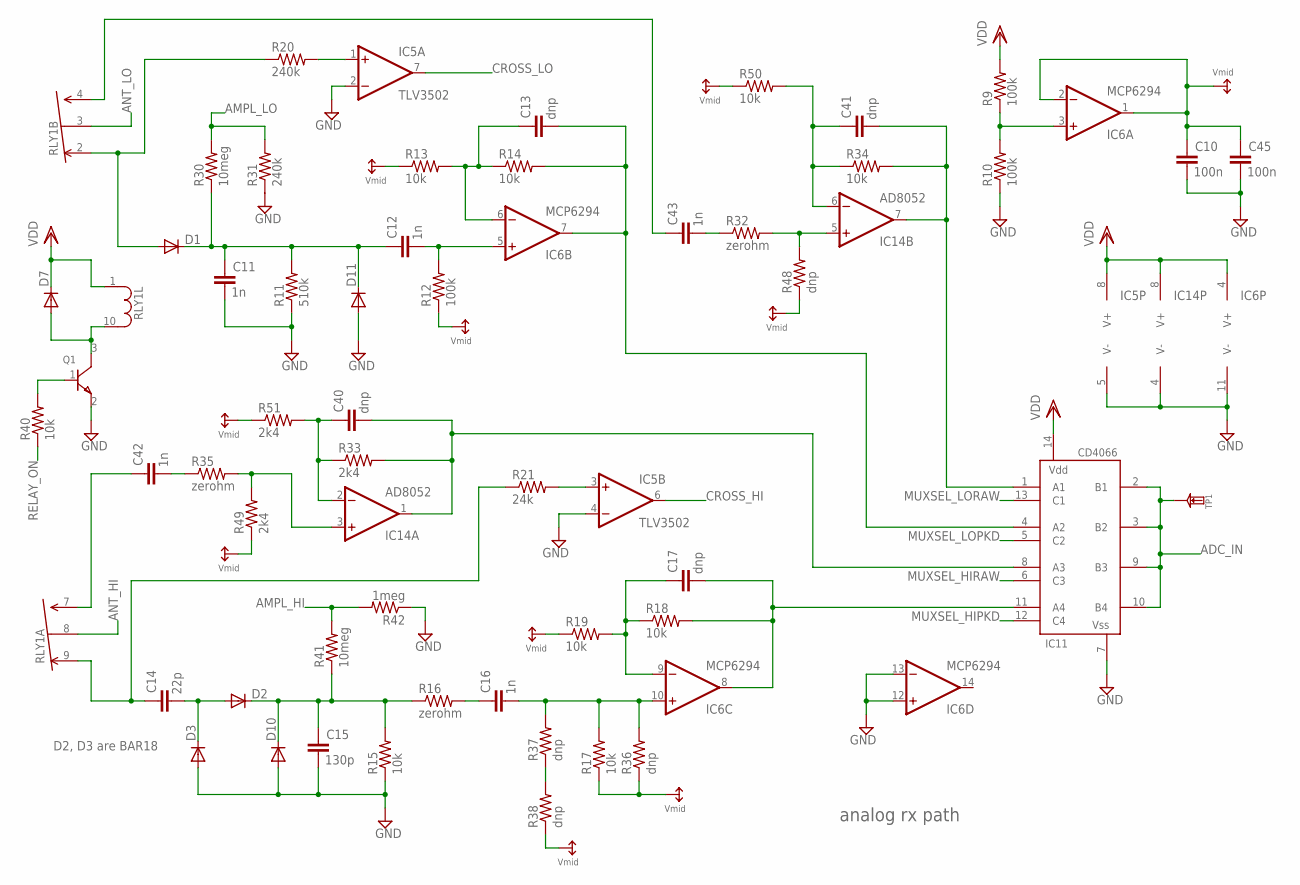
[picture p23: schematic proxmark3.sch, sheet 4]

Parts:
C10, C45: 100n; RLC_0603
C11, C12, C16, C42, C43: 1n; RLC_0603
C13, C17, C40, C41: dnp; RLC_0603
C14: 22p; RLC_0603
C15: 130p; RLC_0603
D1, D2, D3, D7, D10, D11: --MERGED_DIODE-SMD-SOT23; --MERGED_SOT23-3LEAD
IC5: TLV3502; SOT-23-8-OR-MSOP-8
IC6: MCP6294; TSSOP-14
IC11: CD4066; TSSOP-14
IC14: AD8052; MSOP8
Q1: --MERGED_NPN-SOT23-2N3904; --MERGED_SOT23-3LEAD
R9, R10, R12: 100k; RLC_0603
R11: 510k; RLC_0603
R13, R14, R15, R17, R18, R19, R34, R40, R50: 10k; RLC_0603
R16, R32, R35: zerohm; RLC_0603
R20, R31: 240k; RLC_0603
R21: 24k; RLC_0603
R30, R41: 10meg; RLC_0603
R33, R49, R51: 2k4; RLC_0603
R36, R37, R38, R48: dnp; RLC_0603
R42: 1meg; RLC_0603
RLY1: --MERGED_RELAY-DPDT; --MERGED_TQ-SMD-RELAY
TP1: TESTPADKEYSTONE-SMD; KEYSTONE-SMD-TESTPOINT-5015

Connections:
ADCDR_HI: C17.2, IC6.8 (OUT), IC11.11 (A4), R18.2
ADCDR_LO: C13.2, IC6.7 (OUT), IC11.4 (A2), R14.2
ADC_IN: IC11.2 (B1), IC11.3 (B2), IC11.9 (B3), IC11.10 (B4), TP1.1; also elsewhere on the board
AMPL_HI: R41.2, R42.2; also elsewhere on the board
AMPL_LO: R30.2, R31.2; also elsewhere on the board
ANT_HI: RLY1.8 (COM); also elsewhere on the board
ANT_LO: RLY1.3 (COM); also elsewhere on the board
CROSS_HI: IC5.6 (OUT); also elsewhere on the board
CROSS_LO: IC5.7 (OUT); also elsewhere on the board
GND: C10.2, C11.2, C15.2, C45.2, D3.1 (A), D10.1 (A), D11.1 (A), IC5.2 (-IN), IC5.4 (-IN), IC5.5 (V-), IC6.11 (V-), IC6.12 (+IN), IC6.13 (-IN), IC11.7 (VSS), IC14.4 (V-), Q1.2 (E), R10.1, R11.1, R15.1, R31.1, R42.1; also elsewhere on the board
MUXSEL_HIPKD: IC11.12 (C4); also elsewhere on the board
MUXSEL_HIRAW: IC11.6 (C3); also elsewhere on the board
MUXSEL_LOPKD: IC11.5 (C2); also elsewhere on the board
MUXSEL_LORAW: IC11.13 (C1); also elsewhere on the board
unnamed: IC6.3 (+IN), R9.1, R10.2
unnamed: C17.1, IC6.9 (-IN), R18.1, R19.2
unnamed: C12.2, IC6.5 (+IN), R12.2
unnamed: C13.1, IC6.6 (-IN), R13.2, R14.1
unnamed: C16.1, R16.2
unnamed: C11.1, C12.1, D1.3 (C), D11.3 (C), R11.2, R30.1
unnamed: C14.2, D2.1 (A), D3.3 (C)
unnamed: C15.1, D2.3 (C), D10.3 (C), R15.2, R16.1, R41.1
unnamed: C16.2, IC6.10 (+IN), R17.2, R36.2, R37.2
unnamed: IC5.1 (+IN), R20.2
unnamed: IC5.3 (+IN), R21.2
unnamed: D7.1 (A), Q1.3 (C), RLY1.10
unnamed: C14.1, R21.1, RLY1.9 (NC)
unnamed: C42.1, RLY1.7 (NO)
unnamed: Q1.1 (B), R40.2
unnamed: D1.1 (A), R20.1, RLY1.2 (NC)
unnamed: C41.2, IC11.1 (A1), IC14.7 (OUT), R34.2
unnamed: C43.1, RLY1.4 (NO)
unnamed: IC14.3 (+IN), R35.2, R49.2
unnamed: C43.2, R32.1
unnamed: C42.2, R35.1
unnamed: C40.1, IC14.2 (-IN), R33.1, R51.2
unnamed: C41.1, IC14.6 (-IN), R34.1, R50.2
unnamed: IC14.5 (+IN), R32.2, R48.2
unnamed: R37.1, R38.2
RAW_HI: C40.2, IC11.8 (A3), IC14.1 (OUT), R33.2
RELAY_ON: R40.1; also elsewhere on the board
VDD: D7.3 (C), IC5.8 (V+), IC6.4 (V+), IC11.14 (VDD), IC14.8 (V+), R9.2, RLY1.1; also elsewhere on the board
VMID: C10.1, C45.1, IC6.1 (OUT), IC6.2 (-IN), R12.1, R13.1, R17.1, R19.1, R36.1, R38.1, R48.1, R49.1, R50.1, R51.1

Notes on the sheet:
analog rx path
D2, D3 are BAR18

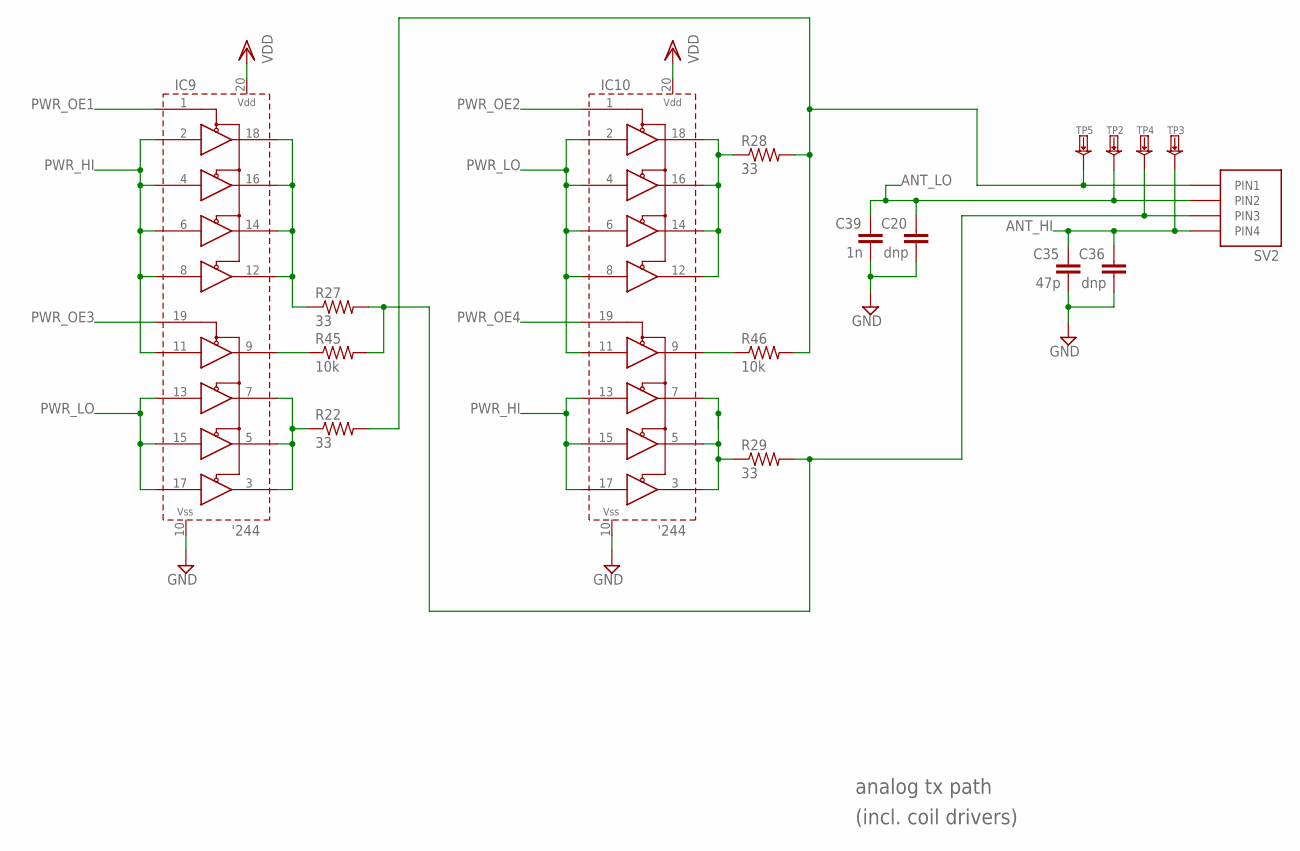
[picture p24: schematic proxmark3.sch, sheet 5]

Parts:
C20, C36: dnp; RLC_0603
C35: 47p; RLC_0603
C39: 1n; RLC_0603
IC9, IC10: 74XX244-OCTAL-TRISTATE-BUFFERS; TSSOP-20
R22, R27, R28, R29: 33; RLC_0603
R45, R46: 10k; RLC_0603
SV2: HIROSE-MQ172-4POS
TP2, TP3, TP4, TP5: TESTPADKEYSTONE-SMD; KEYSTONE-SMD-TESTPOINT-5015

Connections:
ANT_HI: C35.1, C36.1, SV2.4 (PIN4), TP3.1; also elsewhere on the board
ANT_LO: C20.1, C39.1, SV2.2 (PIN2), TP2.1; also elsewhere on the board
GND: C20.2, C35.2, C36.2, C39.2, IC9.10 (VSS), IC10.10 (VSS); also elsewhere on the board
unnamed: R27.2, R29.2, R45.2, SV2.3 (PIN3), TP4.1
unnamed: R22.2, R28.2, R46.2, SV2.1 (PIN1), TP5.1
unnamed: IC9.12 (1Y4), IC9.14 (1Y3), IC9.16 (1Y2), IC9.18 (1Y1), R27.1
unnamed: IC10.12 (1Y4), IC10.14 (1Y3), IC10.16 (1Y2), IC10.18 (1Y1), R28.1
unnamed: IC9.3 (2Y4), IC9.5 (2Y3), IC9.7 (2Y2), R22.1
unnamed: IC10.3 (2Y4), IC10.5 (2Y3), IC10.7 (2Y2), R29.1
unnamed: IC9.9 (2Y1), R45.1
unnamed: IC10.9 (2Y1), R46.1
PWR_HI: IC9.2 (1A1), IC9.4 (1A2), IC9.6 (1A3), IC9.8 (1A4), IC9.11 (2A1), IC10.13 (2A2), IC10.15 (2A3), IC10.17 (2A4); also elsewhere on the board
PWR_LO: IC9.13 (2A2), IC9.15 (2A3), IC9.17 (2A4), IC10.2 (1A1), IC10.4 (1A2), IC10.6 (1A3), IC10.8 (1A4), IC10.11 (2A1); also elsewhere on the board
PWR_OE1: IC9.1 (1NOE); also elsewhere on the board
PWR_OE2: IC10.1 (1NOE); also elsewhere on the board
PWR_OE3: IC9.19 (2NOE); also elsewhere on the board
PWR_OE4: IC10.19 (2NOE); also elsewhere on the board
VDD: IC9.20 (VDD), IC10.20 (VDD); also elsewhere on the board

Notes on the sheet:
analog tx path
(incl. coil drivers)

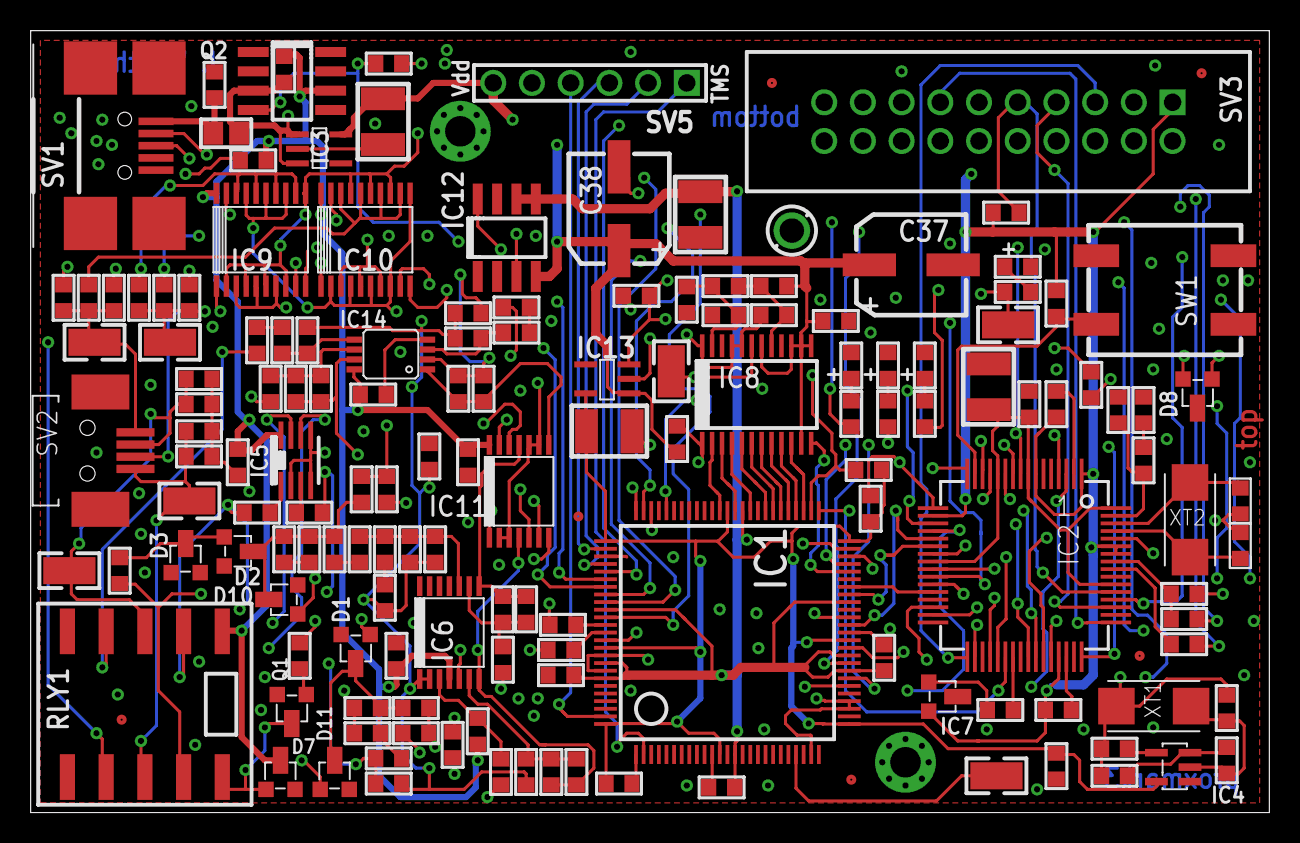
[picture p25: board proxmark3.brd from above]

Board: 4 copper layers, 81.3 x 51.3 mm, 150 parts (0 on the bottom side), 127 nets.

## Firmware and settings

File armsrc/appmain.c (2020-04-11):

//-----------------------------------------------------------------------------
// Jonathan Westhues, Mar 2006
// Edits by Gerhard de Koning Gans, Sep 2007 (##)
//
// This code is licensed to you under the terms of the GNU GPL, version 2 or,
// at your option, any later version. See the LICENSE.txt file for the text of
// the license.
//-----------------------------------------------------------------------------
// The main application code. This is the first thing called after start.c
// executes.
//-----------------------------------------------------------------------------

#include <stdarg.h>

#include "usb_cdc.h"
#include "proxmark3.h"
#include "apps.h"
#include "fpga.h"
#include "util.h"
#include "printf.h"
#include "string.h"
#include "legicrf.h"
#include "legicrfsim.h"
#include "hitag2.h"
#include "hitagS.h"
#include "iclass.h"
#include "iso14443b.h"
#include "iso15693.h"
#include "lfsampling.h"
#include "BigBuf.h"
#include "mifarecmd.h"
#include "mifareutil.h"
#include "mifaresim.h"
#include "pcf7931.h"
#include "i2c.h"
#include "hfsnoop.h"
#include "fpgaloader.h"
#ifdef WITH_LCD
	#include "LCD.h"
#endif

static uint32_t hw_capabilities;

// Craig Young - 14a stand-alone code
#ifdef WITH_ISO14443a
	#include "iso14443a.h"
#endif

//=============================================================================
// A buffer where we can queue things up to be sent through the FPGA, for
// any purpose (fake tag, as reader, whatever). We go MSB first, since that
// is the order in which they go out on the wire.
//=============================================================================

#define TOSEND_BUFFER_SIZE (9*MAX_FRAME_SIZE + 1 + 1 + 2)  // 8 data bits and 1 parity bit per payload byte, 1 correction bit, 1 SOC bit, 2 EOC bits
uint8_t ToSend[TOSEND_BUFFER_SIZE];
int ToSendMax;
static int ToSendBit;
struct common_area common_area __attribute__((section(".commonarea")));

void ToSendReset(void) {
	ToSendMax = -1;
	ToSendBit = 8;
}

void ToSendStuffBit(int b) {
	if (ToSendBit >= 8) {
		ToSendMax++;
		ToSend[ToSendMax] = 0;
		ToSendBit = 0;
	}

	if (b) {
		ToSend[ToSendMax] |= (1 << (7 - ToSendBit));
	}

	ToSendBit++;

	if (ToSendMax >= sizeof(ToSend)) {
		ToSendBit = 0;
		DbpString("ToSendStuffBit overflowed!");
	}
}

//=============================================================================
// Debug print functions, to go out over USB, to the usual PC-side client.
//=============================================================================

void DbpString(char *str) {
	uint8_t len = strlen(str);
	cmd_send(CMD_DEBUG_PRINT_STRING,len,0,0,(uint8_t*)str,len);
}

void Dbprintf(const char *fmt, ...) {
// should probably limit size here; oh well, let's just use a big buffer
	char output_string[128];
	va_list ap;

	va_start(ap, fmt);
	kvsprintf(fmt, output_string, 10, ap);
	va_end(ap);

	DbpString(output_string);
}

// prints HEX & ASCII
void Dbhexdump(int len, uint8_t *d, bool bAsci) {
	int l=0,i;
	char ascii[9];

	while (len>0) {
		if (len>8) l=8;
		else l=len;

		memcpy(ascii,d,l);
		ascii[l]=0;

		// filter safe ascii
		for (i = 0; i < l; i++)
			if (ascii[i]<32 || ascii[i]>126) ascii[i] = '.';

		if (bAsci) {
			Dbprintf("%-8s %*D",ascii, l, d, " ");
		} else {
			Dbprintf("%*D", l, d, " ");
		}

		len -= 8;
		d += 8;
	}
}

//-----------------------------------------------------------------------------
// Read an ADC channel and block till it completes, then return the result
// in ADC units (0 to 1023). Also a routine to average 32 samples and
// return that.
//-----------------------------------------------------------------------------
static int ReadAdc(int ch) {
	// Note: ADC_MODE_PRESCALE and ADC_MODE_SAMPLE_HOLD_TIME are set to the maximum allowed value.
	// AMPL_HI is a high impedance (10MOhm || 1MOhm) output, the input capacitance of the ADC is 12pF (typical). This results in a time constant
	// of RC = (0.91MOhm) * 12pF = 10.9us. Even after the maximum configurable sample&hold time of 40us the input capacitor will not be fully charged.
	//
	// The maths are:
	// If there is a voltage v_in at the input, the voltage v_cap at the capacitor (this is what we are measuring) will be
	//
	//       v_cap = v_in * (1 - exp(-SHTIM/RC))  =   v_in * (1 - exp(-40us/10.9us))  =  v_in * 0,97                   (i.e. an error of 3%)

	AT91C_BASE_ADC->ADC_CR = AT91C_ADC_SWRST;
	AT91C_BASE_ADC->ADC_MR =
		ADC_MODE_PRESCALE(63) |                         // ADC_CLK = MCK / ((63+1) * 2) = 48MHz / 128 = 375kHz
		ADC_MODE_STARTUP_TIME(1) |                      // Startup Time = (1+1) * 8 / ADC_CLK = 16 / 375kHz = 42,7us     Note: must be > 20us
		ADC_MODE_SAMPLE_HOLD_TIME(15);                  // Sample & Hold Time SHTIM = 15 / ADC_CLK = 15 / 375kHz = 40us

	AT91C_BASE_ADC->ADC_CHER = ADC_CHANNEL(ch);
	AT91C_BASE_ADC->ADC_CR = AT91C_ADC_START;

	while(!(AT91C_BASE_ADC->ADC_SR & ADC_END_OF_CONVERSION(ch))) {};

	return AT91C_BASE_ADC->ADC_CDR[ch] & 0x3ff;
}

int AvgAdc(int ch) { // was static - merlok{
	int i;
	int a = 0;

	for(i = 0; i < 32; i++) {
		a += ReadAdc(ch);
	}

	return (a + 15) >> 5;
}

static int AvgAdc_Voltage_HF(void) {
	int AvgAdc_Voltage_Low, AvgAdc_Voltage_High;

	AvgAdc_Voltage_Low= (MAX_ADC_HF_VOLTAGE_LOW * AvgAdc(ADC_CHAN_HF_LOW)) >> 10;
	// if voltage range is about to be exceeded, use high voltage ADC channel if available (RDV40 only)
	if (AvgAdc_Voltage_Low > MAX_ADC_HF_VOLTAGE_LOW - 300) {
		AvgAdc_Voltage_High = (MAX_ADC_HF_VOLTAGE_HIGH * AvgAdc(ADC_CHAN_HF_HIGH)) >> 10;
		if (AvgAdc_Voltage_High >= AvgAdc_Voltage_Low) {
			return AvgAdc_Voltage_High;
		}
	}
	return AvgAdc_Voltage_Low;
}

static int AvgAdc_Voltage_LF(void) {
	return (MAX_ADC_LF_VOLTAGE * AvgAdc(ADC_CHAN_LF)) >> 10;
}

void MeasureAntennaTuningLfOnly(int *vLf125, int *vLf134, int *peakf, int *peakv, uint8_t LF_Results[]) {
	int i, adcval = 0, peak = 0;

/*
 * Sweeps the useful LF range of the proxmark from
 * 46.8kHz (divisor=255) to 600kHz (divisor=19) and
 * read the voltage in the antenna, the result left
 * in the buffer is a graph which should clearly show
 * the resonating frequency of your LF antenna
 * ( hopefully around 95 if it is tuned to 125kHz!)
 */

	FpgaDownloadAndGo(FPGA_BITSTREAM_LF);
	FpgaWriteConfWord(FPGA_MAJOR_MODE_LF_ADC | FPGA_LF_ADC_READER_FIELD);
	SpinDelay(50);

	for (i = 255; i >= 19; i--) {
		WDT_HIT();
		FpgaSendCommand(FPGA_CMD_SET_DIVISOR, i);
		SpinDelay(20);
		adcval = AvgAdc_Voltage_LF();
		if (i == 95) *vLf125 = adcval; // voltage at 125Khz
		if (i == 89) *vLf134 = adcval; // voltage at 134Khz

		LF_Results[i] = adcval >> 9; // scale int to fit in byte for graphing purposes
		if (LF_Results[i] > peak) {
			*peakv = adcval;
			peak = LF_Results[i];
			*peakf = i;
			//ptr = i;
		}
	}

	for (i = 18; i >= 0; i--) LF_Results[i] = 0;

	return;
}

void MeasureAntennaTuningHfOnly(int *vHf) {
	// Let the FPGA drive the high-frequency antenna around 13.56 MHz.
	LED_A_ON();
	FpgaDownloadAndGo(FPGA_BITSTREAM_HF);
	FpgaWriteConfWord(FPGA_MAJOR_MODE_HF_READER);
	SpinDelay(20);
	*vHf = AvgAdc_Voltage_HF();
	LED_A_OFF();
	return;
}

void MeasureAntennaTuning(int mode) {
	uint8_t LF_Results[256] = {0};
	int peakv = 0, peakf = 0;
	int vLf125 = 0, vLf134 = 0, vHf = 0; // in mV

	LED_B_ON();

	if (((mode & FLAG_TUNE_ALL) == FLAG_TUNE_ALL) && (FpgaGetCurrent() == FPGA_BITSTREAM_HF)) {
		// Reverse "standard" order if HF already loaded, to avoid unnecessary swap.
		MeasureAntennaTuningHfOnly(&vHf);
		MeasureAntennaTuningLfOnly(&vLf125, &vLf134, &peakf, &peakv, LF_Results);
	} else {
		if (mode & FLAG_TUNE_LF) {
			MeasureAntennaTuningLfOnly(&vLf125, &vLf134, &peakf, &peakv, LF_Results);
		}
		if (mode & FLAG_TUNE_HF) {
			MeasureAntennaTuningHfOnly(&vHf);
		}
	}

	cmd_send(CMD_MEASURED_ANTENNA_TUNING, vLf125>>1 | (vLf134>>1<<16), vHf, peakf | (peakv>>1<<16), LF_Results, 256);
	FpgaWriteConfWord(FPGA_MAJOR_MODE_OFF);
	LED_B_OFF();
	return;
}

void MeasureAntennaTuningHf(void) {
	int vHf = 0;    // in mV

	DbpString("Measuring HF antenna, press button to exit");

	// Let the FPGA drive the high-frequency antenna around 13.56 MHz.
	FpgaDownloadAndGo(FPGA_BITSTREAM_HF);
	FpgaWriteConfWord(FPGA_MAJOR_MODE_HF_READER);

	for (;;) {
		SpinDelay(500);
		vHf = AvgAdc_Voltage_HF();

		Dbprintf("%d mV",vHf);
		if (BUTTON_PRESS()) break;
	}
	DbpString("cancelled");

	FpgaWriteConfWord(FPGA_MAJOR_MODE_OFF);

}


void ReadMem(int addr) {
	const uint8_t *data = ((uint8_t *)addr);

	Dbprintf("%x: %02x %02x %02x %02x %02x %02x %02x %02x",
		addr, data[0], data[1], data[2], data[3], data[4], data[5], data[6], data[7]);
}

/* osimage version information is linked in */
extern struct version_information version_information;
/* bootrom version information is pointed to from _bootphase1_version_pointer */
extern char *_bootphase1_version_pointer, _flash_start, _flash_end, _bootrom_start, _bootrom_end, __data_src_start__;


void set_hw_capabilities(void) {
	if (I2C_is_available()) {
		hw_capabilities |= HAS_SMARTCARD_SLOT;
	}

	if (false) { // TODO: implement a test
		hw_capabilities |= HAS_EXTRA_FLASH_MEM;
	}
}


void SendVersion(void) {
	LED_A_ON();
	set_hw_capabilities();

	char temp[USB_CMD_DATA_SIZE]; /* Limited data payload in USB packets */
	char VersionString[USB_CMD_DATA_SIZE] = { '\0' };

	/* Try to find the bootrom version information. Expect to find a pointer at
	 * symbol _bootphase1_version_pointer, perform slight sanity checks on the
	 * pointer, then use it.
	 */
	char *bootrom_version = *(char**)&_bootphase1_version_pointer;
	if (bootrom_version < &_flash_start || bootrom_version >= &_flash_end) {
		strcat(VersionString, "bootrom version information appears invalid\n");
	} else {
		FormatVersionInformation(temp, sizeof(temp), "bootrom: ", bootrom_version);
		strncat(VersionString, temp, sizeof(VersionString) - strlen(VersionString) - 1);
	}

	FormatVersionInformation(temp, sizeof(temp), "os: ", &version_information);
	strncat(VersionString, temp, sizeof(VersionString) - strlen(VersionString) - 1);

	for (int i = 0; i < fpga_bitstream_num; i++) {
		strncat(VersionString, fpga_version_information[i], sizeof(VersionString) - strlen(VersionString) - 1);
		strncat(VersionString, "\n", sizeof(VersionString) - strlen(VersionString) - 1);
	}

	// test availability of SmartCard slot
	if (I2C_is_available()) {
		strncat(VersionString, "SmartCard Slot: available\n", sizeof(VersionString) - strlen(VersionString) - 1);
	} else {
		strncat(VersionString, "SmartCard Slot: not available\n", sizeof(VersionString) - strlen(VersionString) - 1);
	}

	// Send Chip ID and used flash memory
	uint32_t text_and_rodata_section_size = (uint32_t)&__data_src_start__ - (uint32_t)&_flash_start;
	uint32_t compressed_data_section_size = common_area.arg1;
	cmd_send(CMD_ACK, *(AT91C_DBGU_CIDR), text_and_rodata_section_size + compressed_data_section_size, hw_capabilities, VersionString, strlen(VersionString) + 1);
	LED_A_OFF();
}

// measure the USB Speed by sending SpeedTestBufferSize bytes to client and measuring the elapsed time.
// Note: this mimics GetFromBigbuf(), i.e. we have the overhead of the UsbCommand structure included.
void printUSBSpeed(void) {
	Dbprintf("USB Speed:");
	Dbprintf("  Sending USB packets to client...");

	#define USB_SPEED_TEST_MIN_TIME 1500    // in milliseconds
	uint8_t *test_data = BigBuf_get_addr();
	uint32_t end_time;

	uint32_t start_time = end_time = GetTickCount();
	uint32_t bytes_transferred = 0;

	while (end_time < start_time + USB_SPEED_TEST_MIN_TIME) {
		cmd_send(CMD_DOWNLOADED_RAW_ADC_SAMPLES_125K, 0, USB_CMD_DATA_SIZE, 0, test_data, USB_CMD_DATA_SIZE);
		end_time = GetTickCount();
		bytes_transferred += USB_CMD_DATA_SIZE;
	}

	Dbprintf("  Time elapsed:      %dms", end_time - start_time);
	Dbprintf("  Bytes transferred: %d", bytes_transferred);
	Dbprintf("  USB Transfer Speed PM3 -> Client = %d Bytes/s",
		1000 * bytes_transferred / (end_time - start_time));

}

/**
  * Prints runtime information about the PM3.
**/
void SendStatus(void) {
	LED_A_ON();
	BigBuf_print_status();
	Fpga_print_status();
#ifdef WITH_SMARTCARD
	I2C_print_status();
#endif
	printConfig(); //LF Sampling config
	printUSBSpeed();
	Dbprintf("Various");
	Dbprintf("  MF_DBGLEVEL........%d", MF_DBGLEVEL);
	Dbprintf("  ToSendMax..........%d", ToSendMax);
	Dbprintf("  ToSendBit..........%d", ToSendBit);

	cmd_send(CMD_ACK, 1, 0, 0, 0, 0);
	LED_A_OFF();
}

#if defined(WITH_ISO14443a_StandAlone) || defined(WITH_LF_StandAlone)

#define OPTS 2

void StandAloneMode() {
	DbpString("Stand-alone mode! No PC necessary.");
	// Oooh pretty -- notify user we're in elite samy mode now
	LED(LED_RED,    200);
	LED(LED_ORANGE, 200);
	LED(LED_GREEN,  200);
	LED(LED_ORANGE, 200);
	LED(LED_RED,    200);
	LED(LED_ORANGE, 200);
	LED(LED_GREEN,  200);
	LED(LED_ORANGE, 200);
	LED(LED_RED,    200);
}

#endif



#ifdef WITH_ISO14443a_StandAlone
void StandAloneMode14a() {
	StandAloneMode();
	FpgaDownloadAndGo(FPGA_BITSTREAM_HF);

	int selected = 0;
	bool playing = false, GotoRecord = false, GotoClone = false;
	bool cardRead[OPTS] = {false};
	uint8_t readUID[10] = {0};
	uint32_t uid_1st[OPTS]={0};
	uint32_t uid_2nd[OPTS]={0};
	uint32_t uid_tmp1 = 0;
	uint32_t uid_tmp2 = 0;
	iso14a_card_select_t hi14a_card[OPTS];

	LED(selected + 1, 0);

	for (;;) {
		usb_poll();
		WDT_HIT();
		SpinDelay(300);

		if (GotoRecord || !cardRead[selected]) {
			GotoRecord = false;
			LEDsoff();
			LED(selected + 1, 0);
			LED(LED_RED2, 0);

			// record
			Dbprintf("Enabling iso14443a reader mode for [Bank: %u]...", selected);
			/* need this delay to prevent catching some weird data */
			SpinDelay(500);
			/* Code for reading from 14a tag */
			uint8_t uid[10]  ={0};
			uint32_t cuid;
			iso14443a_setup(FPGA_HF_ISO14443A_READER_MOD);

			for ( ; ; ) {
				WDT_HIT();
				if (BUTTON_PRESS()) {
					if (cardRead[selected]) {
						Dbprintf("Button press detected -- replaying card in bank[%d]", selected);
						break;
					} else if (cardRead[(selected+1)%OPTS]) {
						Dbprintf("Button press detected but no card in bank[%d] so playing from bank[%d]", selected, (selected+1)%OPTS);
						selected = (selected+1)%OPTS;
						break;
					} else {
						Dbprintf("Button press detected but no stored tag to play. (Ignoring button)");
						SpinDelay(300);
					}
				}
				if (!iso14443a_select_card(uid, &hi14a_card[selected], &cuid, true, 0, true))
					continue;
				else {
					Dbprintf("Read UID:"); Dbhexdump(10,uid,0);
					memcpy(readUID,uid,10*sizeof(uint8_t));
					uint8_t *dst = (uint8_t *)&uid_tmp1;
					// Set UID byte order
					for (int i = 0; i < 4; i++)
						dst[i] = uid[3-i];
					dst = (uint8_t *)&uid_tmp2;
					for (int i = 0; i < 4; i++)
						dst[i] = uid[7-i];
					if (uid_1st[(selected+1) % OPTS] == uid_tmp1 && uid_2nd[(selected+1) % OPTS] == uid_tmp2) {
						Dbprintf("Card selected has same UID as what is stored in the other bank. Skipping.");
					} else {
						if (uid_tmp2) {
							Dbprintf("Bank[%d] received a 7-byte UID", selected);
							uid_1st[selected] = (uid_tmp1)>>8;
							uid_2nd[selected] = (uid_tmp1<<24) + (uid_tmp2>>8);
						} else {
							Dbprintf("Bank[%d] received a 4-byte UID", selected);
							uid_1st[selected] = uid_tmp1;
							uid_2nd[selected] = uid_tmp2;
						}
						break;
					}
				}
			}
			Dbprintf("ATQA = %02X%02X", hi14a_card[selected].atqa[0], hi14a_card[selected].atqa[1]);
			Dbprintf("SAK = %02X", hi14a_card[selected].sak);
			LEDsoff();
			LED(LED_GREEN,  200);
			LED(LED_ORANGE, 200);
			LED(LED_GREEN,  200);
			LED(LED_ORANGE, 200);

			LEDsoff();
			LED(selected + 1, 0);

			// Next state is replay:
			playing = true;

			cardRead[selected] = true;
		} else if (GotoClone) { /* MF Classic UID clone */
			GotoClone=false;
			LEDsoff();
			LED(selected + 1, 0);
			LED(LED_ORANGE, 250);


			// record
			Dbprintf("Preparing to Clone card [Bank: %x]; uid: %08x", selected, uid_1st[selected]);

			// wait for button to be released
			while(BUTTON_PRESS()) {
				// Delay cloning until card is in place
				WDT_HIT();
			}
			Dbprintf("Starting clone. [Bank: %u]", selected);
			// need this delay to prevent catching some weird data
			SpinDelay(500);
			// Begin clone function here:
			/* Example from client/mifarehost.c for commanding a block write for "magic Chinese" cards:
					UsbCommand c = {CMD_MIFARE_CSETBLOCK, {wantWipe, params & (0xFE | (uid == NULL ? 0:1)), blockNo}};
					memcpy(c.d.asBytes, data, 16);
					SendCommand(&c);

					Block read is similar:
					UsbCommand c = {CMD_MIFARE_CGETBLOCK, {params, 0, blockNo}};
					We need to imitate that call with blockNo 0 to set a uid.

					The get and set commands are handled in this file:
					// Work with "magic Chinese" card
					case CMD_MIFARE_CSETBLOCK:
						MifareCSetBlock(c->arg[0], c->arg[1], c->arg[2], c->d.asBytes);
						break;
					case CMD_MIFARE_CGETBLOCK:
						MifareCGetBlock(c->arg[0], c->arg[1], c->arg[2], c->d.asBytes);
						break;

				mfCSetUID provides example logic for UID set workflow:
					-Read block0 from card in field with MifareCGetBlock()
					-Configure new values without replacing reserved bytes
							memcpy(block0, uid, 4); // Copy UID bytes from byte array
							// Mifare UID BCC
							block0[4] = block0[0]^block0[1]^block0[2]^block0[3]; // BCC on byte 5
							Bytes 5-7 are reserved SAK and ATQA for mifare classic
					-Use mfCSetBlock(0, block0, oldUID, wantWipe, CSETBLOCK_SINGLE_OPER) to write it
			*/
			uint8_t oldBlock0[16] = {0}, newBlock0[16] = {0}, testBlock0[16] = {0};
			// arg0 = Flags == CSETBLOCK_SINGLE_OPER=0x1F, arg1=returnSlot, arg2=blockNo
			MifareCGetBlock(0x3F, 1, 0, oldBlock0);
			if (oldBlock0[0] == 0 && oldBlock0[0] == oldBlock0[1]  && oldBlock0[1] == oldBlock0[2] && oldBlock0[2] == oldBlock0[3]) {
				Dbprintf("No changeable tag detected. Returning to replay mode for bank[%d]", selected);
				playing = true;
			} else {
				Dbprintf("UID from target tag: %02X%02X%02X%02X", oldBlock0[0], oldBlock0[1], oldBlock0[2], oldBlock0[3]);
				memcpy(newBlock0, oldBlock0, 16);
				// Copy uid_1st for bank (2nd is for longer UIDs not supported if classic)

				newBlock0[0] = uid_1st[selected] >> 24;
				newBlock0[1] = 0xFF & (uid_1st[selected] >> 16);
				newBlock0[2] = 0xFF & (uid_1st[selected] >> 8);
				newBlock0[3] = 0xFF & (uid_1st[selected]);
				newBlock0[4] = newBlock0[0] ^ newBlock0[1] ^ newBlock0[2] ^ newBlock0[3];
				// arg0 = needWipe, arg1 = workFlags, arg2 = blockNo, datain
				MifareCSetBlock(0, 0xFF, 0, newBlock0);
				MifareCGetBlock(0x3F, 1, 0, testBlock0);
				if (memcmp(testBlock0, newBlock0, 16) == 0) {
					DbpString("Cloned successfull!");
					cardRead[selected] = false; // Only if the card was cloned successfully should we clear it
					playing = false;
					GotoRecord = true;
					selected = (selected+1) % OPTS;
				} else {
					Dbprintf("Clone failed. Back to replay mode on bank[%d]", selected);
					playing = true;
				}
			}
			LEDsoff();
			LED(selected + 1, 0);

		} else if (playing) {
			// button_pressed == BUTTON_SINGLE_CLICK && cardRead[selected])
			// Change where to record (or begin playing)
			LEDsoff();
			LED(selected + 1, 0);

			// Begin transmitting
			LED(LED_GREEN, 0);
			DbpString("Playing");
			for ( ; ; ) {
				WDT_HIT();
				int button_action = BUTTON_HELD(1000);
				if (button_action == 0) { // No button action, proceed with sim
					uint8_t data[512] = {0}; // in case there is a read command received we shouldn't break
					Dbprintf("Simulating ISO14443a tag with uid[0]: %08x, uid[1]: %08x [Bank: %u]", uid_1st[selected], uid_2nd[selected], selected);
					if (hi14a_card[selected].sak == 8 && hi14a_card[selected].atqa[0] == 4 && hi14a_card[selected].atqa[1] == 0) {
						DbpString("Mifare Classic");
						SimulateIso14443aTag(1, uid_1st[selected], uid_2nd[selected], data); // Mifare Classic
					} else if (hi14a_card[selected].sak == 0 && hi14a_card[selected].atqa[0] == 0x44 && hi14a_card[selected].atqa[1] == 0) {
						DbpString("Mifare Ultralight");
						SimulateIso14443aTag(2, uid_1st[selected], uid_2nd[selected], data); // Mifare Ultralight
					} else if (hi14a_card[selected].sak == 20 && hi14a_card[selected].atqa[0] == 0x44 && hi14a_card[selected].atqa[1] == 3) {
						DbpString("Mifare DESFire");
						SimulateIso14443aTag(3, uid_1st[selected], uid_2nd[selected], data); // Mifare DESFire
					} else {
						Dbprintf("Unrecognized tag type -- defaulting to Mifare Classic emulation");
						SimulateIso14443aTag(1, uid_1st[selected], uid_2nd[selected], data);
					}
				} else if (button_action == BUTTON_SINGLE_CLICK) {
					selected = (selected + 1) % OPTS;
					Dbprintf("Done playing. Switching to record mode on bank %d",selected);
					GotoRecord = true;
					break;
				} else if (button_action == BUTTON_HOLD) {
					Dbprintf("Playtime over. Begin cloning...");
					GotoClone = true;
					break;
				}
				WDT_HIT();
			}

			/* We pressed a button so ignore it here with a delay */
			SpinDelay(300);
			LEDsoff();
			LED(selected + 1, 0);
		}
	}
}

#elif WITH_LF_StandAlone
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

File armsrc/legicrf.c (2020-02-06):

//-----------------------------------------------------------------------------
// (c) 2009 Henryk Plötz <henryk@ploetzli.ch>
//     2016 Iceman
//     2018 AntiCat
//
// This code is licensed to you under the terms of the GNU GPL, version 2 or,
// at your option, any later version. See the LICENSE.txt file for the text of
// the license.
//-----------------------------------------------------------------------------
// LEGIC RF simulation code
//-----------------------------------------------------------------------------

#include "legicrf.h"

#include "proxmark3.h"
#include "apps.h"
#include "usb_cdc.h"
#include "util.h"
#include "string.h"
#include "legic_prng.h"
#include "legic.h"
#include "crc.h"
#include "fpgaloader.h"

static legic_card_select_t card;/* metadata of currently selected card */
static crc_t legic_crc;

//-----------------------------------------------------------------------------
// Frame timing and pseudorandom number generator
//
// The Prng is forwarded every 100us (TAG_BIT_PERIOD), except when the reader is
// transmitting. In that case the prng has to be forwarded every bit transmitted:
//  - 60us for a 0 (RWD_TIME_0)
//  - 100us for a 1 (RWD_TIME_1)
//
// The data dependent timing makes writing comprehensible code significantly
// harder. The current aproach forwards the prng data based if there is data on
// air and time based, using GET_TICKS, during computational and wait periodes.
//
// To not have the necessity to calculate/guess exection time dependend timeouts
// tx_frame and rx_frame use a shared timestamp to coordinate tx and rx timeslots.
//-----------------------------------------------------------------------------

static uint32_t last_frame_end; /* ts of last bit of previews rx or tx frame */

#define RWD_TIME_PAUSE       30 /* 20us */
#define RWD_TIME_1          150 /* READER_TIME_PAUSE 20us off + 80us on = 100us */
#define RWD_TIME_0           90 /* READER_TIME_PAUSE 20us off + 40us on = 60us */
#define RWD_FRAME_WAIT      330 /* 220us from TAG frame end to READER frame start */
#define TAG_FRAME_WAIT      495 /* 330us from READER frame end to TAG frame start */
#define TAG_BIT_PERIOD      150 /* 100us */
#define TAG_WRITE_TIMEOUT    60 /* 40 * 100us (write should take at most 3.6ms) */

#define LEGIC_READ         0x01 /* Read Command */
#define LEGIC_WRITE        0x00 /* Write Command */

#define SESSION_IV         0x55 /* An arbitrary chose session IV, all shoud work */
#define OFFSET_LOG         1024 /* The largest Legic Prime card is 1k */
#define WRITE_LOWERLIMIT      4 /* UID and MCC are not writable */

#define INPUT_THRESHOLD       8 /* heuristically determined, lower values */
                                /* lead to detecting false ack during write */

//-----------------------------------------------------------------------------
// I/O interface abstraction (FPGA -> ARM)
//-----------------------------------------------------------------------------

static inline uint16_t rx_frame_from_fpga() {
  for(;;) {
    WDT_HIT();

    // wait for frame be become available in rx holding register
    if(AT91C_BASE_SSC->SSC_SR & (AT91C_SSC_RXRDY)) {
      return AT91C_BASE_SSC->SSC_RHR;
    }
  }
}

//-----------------------------------------------------------------------------
// Demodulation (Reader)
//-----------------------------------------------------------------------------

// Returns a demedulated bit
//
// The FPGA running xcorrelation samples the subcarrier at ~13.56 MHz. The mode
// was initialy designed to receive BSPK/2-PSK. Hance, it reports an I/Q pair
// every 4.7us (8 bits i and 8 bits q).
//
// The subcarrier amplitude can be calculated using Pythagoras sqrt(i^2 + q^2).
// To reduce CPU time the amplitude is approximated by using linear functions:
//   am = MAX(ABS(i),ABS(q)) + 1/2*MIN(ABS(i),ABSq))
//
// The bit time is 99.1us (21 I/Q pairs). The receiver skips the first 5 samples
// and averages the next (most stable) 8 samples. The final 8 samples are dropped
// also.
//
// The demodulated should be alligned to the bit period by the caller. This is
// done in rx_bit and rx_ack.
static inline bool rx_bit() {
  int32_t sum_cq = 0;
  int32_t sum_ci = 0;

  // skip first 5 I/Q pairs
  for(size_t i = 0; i<5; ++i) {
    (void)rx_frame_from_fpga();
  }

  // sample next 8 I/Q pairs
  for(size_t i = 0; i<8; ++i) {
    uint16_t iq = rx_frame_from_fpga();
    int8_t ci = (int8_t)(iq >> 8);
    int8_t cq = (int8_t)(iq & 0xff);
    sum_ci += ci;
    sum_cq += cq;
  }

  // calculate power
  int32_t power = (MAX(ABS(sum_ci), ABS(sum_cq)) + MIN(ABS(sum_ci), ABS(sum_cq))/2);

  // compare average (power / 8) to threshold
  return ((power >> 3) > INPUT_THRESHOLD);
}

//-----------------------------------------------------------------------------
// Modulation (Reader)
//
// I've tried to modulate the Legic specific pause-puls using ssc and the default
// ssc clock of 105.4 kHz (bit periode of 9.4us) - previous commit. However,
// the timing was not precise enough. By increasing the ssc clock this could
// be circumvented, but the adventage over bitbang would be little.
//-----------------------------------------------------------------------------

static inline void tx_bit(bool bit) {
  // insert pause
  HIGH(GPIO_SSC_DOUT);
  last_frame_end += RWD_TIME_PAUSE;
  while(GET_TICKS < last_frame_end) { };

  // return to carrier on, wait for bit periode to end
  LOW(GPIO_SSC_DOUT);
  last_frame_end += (bit ? RWD_TIME_1 : RWD_TIME_0) - RWD_TIME_PAUSE;
  while(GET_TICKS < last_frame_end) { };
}

//-----------------------------------------------------------------------------
// Frame Handling (Reader)
//
// The LEGIC RF protocol from card to reader does not include explicit frame
// start/stop information or length information. The reader must know beforehand
// how many bits it wants to receive.
// Notably: a card sending a stream of 0-bits is indistinguishable from no card
// present.
//-----------------------------------------------------------------------------

static void tx_frame(uint32_t frame, uint8_t len) {
  FpgaWriteConfWord(FPGA_MAJOR_MODE_HF_READER | FPGA_HF_READER_MODE_SEND_FULL_MOD);

  // wait for next tx timeslot
  last_frame_end += RWD_FRAME_WAIT;
  while(GET_TICKS < last_frame_end) { };

  // transmit frame, MSB first
  for(uint8_t i = 0; i < len; ++i) {
    bool bit = (frame >> i) & 0x01;
    tx_bit(bit ^ legic_prng_get_bit());
    legic_prng_forward(1);
  };

  // add pause to mark end of the frame
  HIGH(GPIO_SSC_DOUT);
  last_frame_end += RWD_TIME_PAUSE;
  while(GET_TICKS < last_frame_end) { };
  LOW(GPIO_SSC_DOUT);
}
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

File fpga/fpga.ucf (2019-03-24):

# See the schematic for the pin assignment.

NET "adc_d<0>"  LOC = "P62"  ;
NET "adc_d<1>"  LOC = "P60"  ;
NET "adc_d<2>"  LOC = "P58"  ;
NET "adc_d<3>"  LOC = "P57"  ;
NET "adc_d<4>"  LOC = "P56"  ;
NET "adc_d<5>"  LOC = "P55"  ;
NET "adc_d<6>"  LOC = "P54"  ;
NET "adc_d<7>"  LOC = "P53"  ;
NET "cross_hi"  LOC = "P88"  ;
#NET "miso"      LOC = "P40"  ;
#PACE: Start of Constraints generated by PACE

#PACE: Start of PACE I/O Pin Assignments
NET "adc_clk"  LOC = "P46"  ;
NET "adc_noe"  LOC = "P47"  ;
NET "ck_1356meg"  LOC = "P91"  ;
NET "ck_1356megb"  LOC = "P93"  ;
NET "cross_lo"  LOC = "P87"  ;
NET "dbg"  LOC = "P22"  ;
NET "mosi"  LOC = "P43"  ;
NET "ncs"  LOC = "P44"  ;
NET "pck0"  LOC = "P36"  ;
NET "pwr_hi"  LOC = "P80"  ;
NET "pwr_lo"  LOC = "P81"  ;
NET "pwr_oe1"  LOC = "P82"  ;
NET "pwr_oe2"  LOC = "P83"  ;
NET "pwr_oe3"  LOC = "P84"  ;
NET "pwr_oe4"  LOC = "P86"  ;
NET "spck"  LOC = "P39"  ;
NET "ssp_clk"  LOC = "P71"  ;
NET "ssp_din"  LOC = "P32"  ;
NET "ssp_dout"  LOC = "P34"  ;
NET "ssp_frame"  LOC = "P31"  ;

#PACE: Start of PACE Area Constraints

#PACE: Start of PACE Prohibit Constraints

#PACE: End of Constraints generated by PACE

# definition of Clock nets:
NET "ck_1356meg" TNM_NET = "clk_net_1356" ;
NET "ck_1356megb" TNM_NET = "clk_net_1356b" ;
NET "pck0" TNM_NET = "clk_net_pck0" ;
NET "spck" TNM_NET = "clk_net_spck" ;

# Timing specs of clock nets:
TIMEGRP "clk_net_1356_all" = "clk_net_1356" "clk_net_1356b" ;
TIMESPEC "TS_1356MHz" = PERIOD "clk_net_1356_all" 74 ns HIGH 37 ns ;
TIMESPEC "TS_24MHz" = PERIOD "clk_net_pck0" 42 ns HIGH 21 ns ;
TIMESPEC "TS_4MHz" = PERIOD "clk_net_spck" 250 ns HIGH 125 ns ;

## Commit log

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2014-07-17 Unstable branch: ported iclass research from Pentura_Prox's previous proxmark implentation.
    Not sure what has changed in the Proxmark firmware, but not quite working the same.
    hf iclass dump, sometimes does not accurately get the CSN and CC used for Authentication.
    Other times it fails to execute the procedure to dump the card, or a correct MAC is diagnosed
    as authentication failure.
    However, if a MAC is corrected calculated, card contents ca be dumped with hf iclass replay <MAC>
    It could be down to the antenna? as I am Using the RyscCorp HF Antenna.
    Requires further testing!
    [appmain.c]
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2015-03-15 Change "hf list topaz" to "hf list nfc" fix: reduce length of expected unmodulated signal in Miller decoder in order to allow decoding of NFC reader communications add: hf list nfc: aggregate reader 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
    [iso14443a.c]
2015-03-17 revert change "hf list topaz" to "hf list nfc" refactored Startbit detection in MillerDecoding() relaxed startbit detection in MillerDecoding() fixed CRC checking and CRC bytes marking in hf list fix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
    [iso14443a.c]
2015-03-18 fix: introduced a stupid error when refactoring the start bit detector in MillerDecoding() chg: use -O2 instead of -Os when compiling ARM sources chg: don't clear the Miller decoders input buffer on 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
    [iso14443a.c]
2015-05-26 replaced gzip with an own compressor tool (fpga_compress.c, based on zlib) This allows to remove the gzip header support and the z_crc32.[ch] files (which saves more than 2KBytes of the ARM's flash m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
    [fpgaloader.c]
2015-05-26 fpga_compress: interleave (combine) fpga_lf.bit and fpga_hf.bit before compression. fpga_loader.c: change to unweave fpga_lf and fpga_hf accordingly prepare fpga_compress, fpga_loader and Makefile to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
    [fpgaloader.c, fpgaloader.h]
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2015-05-26 Compress the .data section as well (saves another 4KBytes and comes for free) zlib tuning: prevent fpga_compress from generating fixed code blocks armsrc/Makefile: replace osimage with fullimage
    [appmain.c]
2015-05-26 also delete *.bin and fpga_compressor when "make clean". Add target to make fpga_compressor when client is not yet compiled. Get version information and cache it when client starts (avoids clearing B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
    [appmain.c, fpgaloader.c, util.c]
2015-06-08 fixed bug in util getpraram8 + reveng adjustments
    reveng:
    fixed error handling some.
    added -s option to GetModels()
    [util.c]
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2015-06-29 - fix: ensure that FpgaDownloadAndGo() is always called before requesting any memory from BigBuf[]. This is required because FpgaDownloadAndGo() might allocate, use, and free most of BigBuf[] when de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
    [hitag2.c, iso14443a.c, iso14443b.c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]
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2015-06-30 fix 14b raw -s option, + get rid of...
    <empty trace - possible error>
    [iso14443b.c]
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2015-07-29 add: USB Speed Test to hw status fix: choose Real Time Clock divider based on actual slow clock frequency
    [appmain.c, util.c]
2015-07-31 fix: avoid USB Speed Test timeout in case of slow transfer speeds fix: don't add CMD_DOWNLOADED_RAW_ADC_SAMPLES_125K commands into command buffer
    [appmain.c]
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2015-09-30 hf mf mifare: - gracefully exit on unsuccessful syncs instead of hard watchdog reset
    [iso14443a.c]
2015-10-07 Add mifare crypto trace decryption utility
    allows manual decryption of hf 14a snoop traces of a mf card.
    someday we should fix hf mf sniff...
    [util.c, util.h]
2015-10-10 hf mf mifare: (finally) fix watchdog reset - minor changes to sync - try alternative strategies when debugging
    [iso14443a.c]
2015-10-22 updates to lf t55xx commands
    fix wakeup cmd per @iceman1001
    fix dump and read cmds
    clean up write command
    allow page 1 read/write (block 3 is writable)(ata5577 only)
    remove duplicate code
    [appmain.c, lfops.c]
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2015-10-31 Add lf t55xx resetread cmd + fix clone cmds
    resetread cmd to determine start of streaming bits of ata5577 or
    compatible chips...
    fixed lf clone bugs introduced while refactoring recently...
    [appmain.c, lfops.c]
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2015-11-13 cad, cam file commit
    adding modified CAD and CAM file sets. Checked against DRC issues, all
    looks okay, ready to manufacturing!
    [lf-antenna.GBL, lf-antenna.GBO, lf-antenna.GBP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]
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2015-11-16 lf t55xx and some lf demod fixes/adjustments
    finally think I like the lf t55xx detect and read cmds. pretty reliable
    now.
    [lfops.c]
2015-11-18 lf demod cleanup nrz clock detect fixes
    slight adjustment to lf t55xx sampling code to start at the same spot
    more consistently
    reduce indala detection false positives
    lf t55xx commands heavily tested and seem to be stable and reliable on
    most modulations/bitrates (excluding Sequence Terminator configured
    cards).
    [lfops.c]
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2015-12-02 icemans lf fixes & adjustments + lf t55xx bruteforce
    Fix small fskdemod clock bug
    [lfops.c]
2015-12-08 Fix printdemodbuffer length tests + add length...
    parameter
    increase askdemod MaxBits
    fix util.c sprint_bin_break and increase buffer size (had memory
    overflow possible before)
    [util.c]
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2015-12-14 fix occasional strange printed clock value with...
    ...fskdemod
    Fix Q5 tag detection in lf t55xx detect
    Fix param_get8 reversed parameters
    [util.c]
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2016-02-14 additional memory leaks, overflow and unchecked ...
    return values fixed
    thanks to iceman1001
    [util.c]
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2016-03-06 Add @iceman1001 s presco and pyramid functions +
    plus comment some includes.
    fix indala error checking bugs
    cmddata.h previously relied on several headers being included prior to
    cmddata.h, now self contained.
    [util.h]
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2016-03-07 add ST to ask/manchester sim, finish presco...
    ...as it is currently understood - need to add base 12 printed ID to
    demod output...
    add Q5 option to pyramid
    fix missing include I mistakenly removed in cmdlf
    [lfops.c, util.h]
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2016-06-24 fix bug in moebius nonce collection - now finishes
    also cleaned up some comments
    note previous update added the creation of a stats.txt file to generate
    statistics of the differences between std mfkey32 and the moebius
    version.
    [iso14443a.c]
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2016-12-19 fixed lf antenna left on bug && some iclass ...
    output cleanup by @iceman1001
    [lfops.c]
2017-01-26 hf mf sim: Multiple fixes from review of PR #209.
    - Don't increment the nonce when random mode is disabled (this breaks the
    standard attack).
    - Don't attempt the standard attack when random mode is enabled (there's no
    point as it won't work, per comments from @pwpiwi).
    - Attempt the moebius attack if the standard attack fails.
    [iso14443a.c]
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2017-02-17 minor fixes for FSK demod
    works better with EM4x03 and t55x7 tags (in theory)...
    [lfops.c]
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2017-02-20 shorten em4x05 capture samples
    add cap option for 4469
    add sample size option for DoAcquisition so i can limit how many
    samples i want to collect.
    use with DoPartialAcquisition
    [lfops.c]
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2017-02-22 fix false positive psk demod with fsk wave
    also break out new find start of modulation routine.
    [lfops.c]
2017-02-22 small text adjustments plus...
    small improvement to fsk clock detect + fixed a bug where it would
    default to rf/16 when it couldn't find a valid one...
    [lfops.c]
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2017-02-23 Code cleanup: - correctly using stdtypes.h printf and scanf format string macros (PRIx64 et al) - coverity fixes to client/cmdhfmf.c - fix linker warning re missing entry point when linking fullimage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
    [hitag2.c]
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2017-03-14 add bitswap option for lf em 4x05write
    default read mode of this chip outputs in reverse order... so offer the
    option to program in reverse order
    [util.c, util.h]
2017-03-21 add bitswap option for lf em 4x05write (#236)
    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
    [util.c, util.h]
2017-03-22 fix: ukbhit() for OS X - don't use CMIN and CTIME - corrected comments
    [util.c]
2017-03-25 hitag sim fix
    from
    https://github.com/iceman1001/proxmark3/commit/e1778858ddc53a6a82e8ee24f02e6b673687f69a
    and http://www.proxmark.org/forum/viewtopic.php?pid=26733#p26733
    sim mode should not have the reader field on.
    [hitag2.c, hitagS.c]
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2017-03-30 Fixed compile error in MinGW (#260)
    * Fixed compile error in MinGW
    Some versions of MinGW miss some definitions. In order to be able to
    compile I redefined a function and added an explicit include. It is only
    a quick workaround, as other people also seemed to have the same
    problem. It should be checked whether a better solution is possible.
    * Removed _ftime_s redefine, calling _ftime directly
    [util.c]
2017-04-04 lf improvements
    fix noralsy demod bug (st should be true)
    fix sprint_bin_break bug (didn't print last bit)
    add a function to save/restore demodbuffer
    remove redundant countFC call in PSKDemod
    clean up pskclockdetect functions
    fix indala26decode bug (end of data sometimes not correct)
    improve PSK detection / demodulation
    improve NRZ detection
    improve t55xx commands & fix a few bugs
    add t55xx page1 detection - added it to lf search
    added experimental t55xx testmode write
    [lfops.c, util.c]
2017-04-04 fix bug in st detect +
    adjust nrz t55xx detection to reduce false positives on weak antennas
    adjust t55xx read wait to get past initial startup wave.
    [lfops.c]
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2017-04-07 lf read adjustments
    add parameter for # bits to read
    auto get samples after lf read/snoop (don't need to do a `data samples`
    anymore)
    add safe function to get DemodBuffer
    add some lf demod comments and apply new lf_read function instead of
    read then get samples.
    fixed output bug in lf t55xx config print
    fixed small bug in lf t55xx detect during ST check
    [appmain.c, lfops.c, util.c]
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2017-05-31 New: implementing hf mf hardnested This implements the attack described in Carlo Meijer, Roel Verdult, "Ciphertext-only Cryptanalysis on Hardened Mifare Classic Cards" in Proceedings of the 22nd ACM 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
    [appmain.c, util.c, util.h]
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2017-06-06 coverity scan bug fixes
    mfu keyNo buffer overflow
    mf reader attack key count reduced to not overrun c.d.asBytes buffer.
    [iso14443a.c]
2017-06-07 Fix compile errors with MacOS (#312)
    * Fix compile errors with MacOS
    - _POSIX_C_SOURCE must not be defined for num_CPU()
    * separate util_posix.c require changes in tools directory as well
    * remove unnecessary self-include
    [util.c, util.h]
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2017-06-20 some coverity fixes plus fix fdx help (#328)
    * coverity fixes
    cmdhflegic- indications are the i in calls to data_buf[i] could = 1052
    and overflow the array.
    cmdhfmfhard - +1 to add space for string null terminator - should we add
    the 0 terminator value too?
    reveng.c - memory leak
    util.c - fix potential overflow of array buf[]
    util_posix.c - possible integer overflow
    * fix help errors
    * fix sprint_hex_ascii
    again
    and this function is not even used anywhere... yet...
    [util.c]
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2017-08-08 adjust lf simulation - fix one bug + attempt... (#369)
    ... to speed up the loops waiting for carrier signal to go high or low
    by only checking for a halt (button press or usbpol) every 1000th loop
    iteration.
    some users were experiencing modulating reactions to be too slow.
    [lfops.c]
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2017-08-17 Fixes 2 bugs in mifare simulate (#380)
    - Check button press when there is NOFIELD, so we can exit also without FIELD
    - struct nonces_t is moved to include/mifare.h so client and arm has the same definition
    [iso14443a.c]
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2017-08-27 Indala fixes - set accurate preamble and start of.. (#385)
    .. data for both format types (64 bit and 224 bit)
    also adjust 224 bit demod and clone to output and input in PSK2 instead
    of PSK1 as this appears to be most common for this format.
    [lfops.c]
2017-09-11 fix lf sim fpga download overwrites sim buffer (#391)
    * adjust LFSim to download lf fpga prior to setting emulation buffer to prevent buffer overwrite condition if you are coming from HF fpga.
    * fix lf sim big buff overwrite with fpga download. Move fix to the buffer download cmd.
    [appmain.c, lfops.c]
2017-09-22 reworking magic cheneese card wipe (#365)
    Implement hf mf cwipe. Remove wipe parameter from hf mf csetuid.
    [appmain.c, util.c, util.h]
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2017-10-20 proxmark3 refactoring command line parameters (#417)
    * add -c (execute command from command line)
    * fix: sometimes proxmark executes command twice...
    * fix: start proxmark from QT was in a strange way (if we issue command very fast - it hangs)
    * added -l (execute lua script)
    * rework help
    * small memory management bugfix
    * small fix in executing command files
    * enable piping from STDIN
    [util.c, util.h]
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2017-10-20 fix hf mf sim (issue #412) (#419)
    * move to separate files mifaresim.[ch]
    * check CRC of commands
    * don't execute commands without successfull authentication
    * ensure correct timing of REQA, WUPA, ANTICOL and SELECT responses
    * trace reader commands immediately, only fix start time after tag response. Decreases time to be ready for next reader command.
    * remove iso14443-4 remnants
    * trace raw reader commands instead of decrypted ones
    * some refactoring
    * fix hf mf sim
    * timing: decrease time to get ready for new reader commands
    [iso14443a.c, mifaresim.c]
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2017-10-30 fixed bug in CmdHF14ACmdRaw: if we cant select we send command anyway...
    [iso14443a.c]
2017-11-01 deleted condition in iso14a select (sak & 0x20 ==0) - error. Usually SAK = 88
    [iso14443a.c]
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2017-11-02 fix hf mf sim: * more timing fixes * correctly determine correction bit (taken from iceman's fork) * add checking of Access Conditions for Read command * never allow reading KeyA
    [iso14443a.c, mifaresim.c]
2017-11-03 moved includes, added clear_trace flag (it was there...) and fixed multiapdu iso14443 stream
    [iso14443a.c]
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2017-11-10 fix lf search bugs when no tag is on antenna
    cotag read could enter endless loop, now cancels if the next bit doesn't
    appear
    em4x05 detection would loop due to a threshold never being met, now has
    a dump out after 1000 samples tested.
    fixed some indenting in hitag2 while i was reviewing that code for
    potential endless loops...
    [hitag2.c, lfops.c]
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2017-11-15 minor fixes
    * fix timeout set in PR #481
    * fix warning in util.c printf
    [util.c]
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2017-11-21 fix: avoid SspClk overflow due to incomplete reset
    * should fix watchdog reset during hf mf mifare. Thanks @iceman1001 for the hint.
    [util.c]
2017-11-22 minor iso14443a timing fixes to avoid select errors: * take setup frame guard time (SFGT) into account * adjust iso14a_timeout by FPGA delays * don't give up on first WUPA. Retry several times
    [iso14443a.c]
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2017-11-30 Update fpgaloader.c (#500)
    This address part1 in issue https://github.com/Proxmark/proxmark3/issues/499
    Device power out 13.56Mhz when started (initialised). This output is not stopped until arbitary command is sent.
    [fpgaloader.c]
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2017-12-10 fix: hf mf hardnested failed with new WUPA timing * allow additional 2 ssp_frame cycles to detect SOF * use only respective functions to get/set iso14a_timeout * remove waiting time in MifareAcquireE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
    [iso14443a.c]
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2017-12-28 Minor fixes * fix compiler warnings on Ubuntu * cmdhf14a.c: make manufactureMapping static * cmdhf14a.c: fix format strings
    [util.c]
2017-12-28 Khorben/warnings (#519)
    * Fix warnings and missing #include for <ctype.h>
    * Avoid a warning in client/util.c
    [util.c]
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2018-01-22 dbg: Watchdog resets while 'hw tune lf'
    loop does not finish, u_int is always '>=0'
    [appmain.c]
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2018-01-22 Revert "dbg: Watchdog resets while 'hw tune lf'"
    This reverts commit fc175230f431e7e33c7628c6b31064d4f7d1e1ad.
    [appmain.c]
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2018-02-08 hf mf mifare: * prevent WDT crash on repeated tries * comes with faster execution as side effect * use uint8_t instead of byte_t * populate ar instead of (correctly) assuming that it is zero * remove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
    [iso14443a.c]
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2018-02-14 update changelog
    +fix a comment typo
    + move clear bigbuf after fpgadownloadandgo...
    [lfops.c]
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2018-05-08 rework of GetFromBigBuf() (#597)
    * this should fix crashes reported in issue #497
    * don't allow receiver thread to write directly into arbitrary main thread's memory
    * instead use cmdBuffer[] for CMD_DOWNLOADED_RAW_ADC_SAMPLES_125K as well
    * add timeout and warning options to GetFromBigBuf(), same as in WaitForResponseTimeoutW()
    * move GetFromBigBuf() from data.c to comms.c
    * remove data.c and data.h
    [util.c, util.h]
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2018-06-13 Code cleanup (#616)
    * coverity fixes (including a real bug in cmdhftopaz.c)
    * Typo fix
    * replace TRUE/FALSE by stdbool true/false
    [appmain.c, hitag2.c, hitagS.c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]
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2018-08-05 mod hw version: (#631)
    * create fpga version info at compile time (by additional functionality in fpgacompress)
    * remove hw version caching (prepare USB reconnect)
    * fix calculation of available compressed bytes in fpga_loader.c
    [appmain.c, fpgaloader.c, fpgaloader.h]
2018-08-14 fix: 32bit tick timer based on TC0 and TC1 (#653)
    TC1 counts the number of TC0 overflows (carry bits).
    In random conditions TC1 would return or stay at zero,
    instead of counting up. This due to the behavior of the
    reset signal.
    SAM7S Series Datasheet, 33.5.6 Trigger:
    Regardless of the trigger used, it will be taken into account
    at the following active edge of the selected clock. This means
    that the counter value can be read differently from zero just
    after a trigger, especially when a low frequency signal is
    selected as the clock.
    The new code first prepares TC1 and asserts TC1 trigger and
    then prepares TC0 and asserts TC0 trigger. The TC0 start-up
    will reset TC1.
    [util.c, util.h]
2018-08-15 ISO15693 device side improvements (#652)
    * ISO15693 device side improvements
    * increase accuracy by doubling the sample frequency (hi_read_rx_xcorr.v)
    * adjust armsrc/iso15693.c and client/cmdhf15.c accordingly
    * use more accurate approximation for sqrt(ci^2 + cq^2)
    * improve EOF detection (was often mistaken for Logic0, resulting in "error, uneven octet! (extra bits!)")
    * hi_read_r_xcorr.v: avoid overflows during accumulation and truncation
    * explicitely cast unsigned ADC samples to signed
    [iso15693.c]
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2018-08-20 Legic: rewrite reader to use xcorrelation and precise timing (#654)
    * Legic: rewrite reader to use xcorrelation and precise timing
    - Even tough Legic tags transmit just AM, receiving using
    xcorrelation results in a significantly better signal
    quality.
    - Switching from bit bang to a hardware based ssc frees
    up CPU time for other tasks e.g. prng and demodulation
    - Having all times based on a fixed ts, results in perfect
    rwd-tag synchronization without magic +/- calculations.
    * hi_read_tx: remove jerry-riged hysteresis based receiver
    - This feature got obsolete by a x-correlation based receiver.
    * Legic: adjusted sampling to new ssp clock speed
    - Sampling is 4 times fa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
    [legicrf.c]
2018-08-21 Legic: fixed write (#655)
    Due to an oversight the bytes to be written were fetched
    from the wrong location. This is fixed now.
    [legicrf.c]
2018-08-21 Add Smartcard functions (RDV4.0) (#646)
    * allow common makefile options-defines
    * remove non-existing file references
    * Uncomment lcd option (still) not enabled by default
    use Makefile_Enabled_Options.common
    to enable lcd if desired.
    * Add Smartcard Functions
    * add smartcard to menu + make get atr work
    sc is now functioning as far as my limited knowledge takes me
    * sc cleanup - add init to all sc commands...
    because cmds won't work until the first init happens. (multiple inits
    don't appear to affect it negatively)
    * default options to exclude Smartcard
    for main repo
    * update changelog
    [appmain.c, i2c.c]
2018-08-31 lf hid improvements - encoding and long tag simulation **DEVICE FIRMWARE UPDATE** The code changes needed to support long tag emulation required an update to the device firmware. As of this patch, de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
    The 'lf hid encode' command has been further refined, and is now entirely parameterized to support use of fields other than facility code and card number. The client help data has been updated to show the correct syntax.
    [appmain.c, lfops.c]
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2018-09-09 Legic Tag Simulator (#666)
    * FPGA Hi-Simulate: Formatted code
    * FPGA Hi-Simulate: Fixed documantation
    * FPGA Hi-Simulate: Freed up 4 LUTs
    * FPGA Hi-Simulate: Added 212kHz SSP-Clock option
    * Legic: Moved card simulator into separate file & cleaned interface.
    Reader and card simulation have almost no common code. Moreover the sim
    uses an SSP Clock at 212kHz for all timings to prevent any drifting from
    the PRNG. This clock speed is not available in reader simulation mode (SSP
    runs at up to 3.4MHz, and changes speed between TX and RX). For these
    reasons having the code in separate files makes it significantly cleaner.
    * Legic: Implemented RX and TX for card simulation
    * Legic: Impleme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
    [appmain.c, legicrf.c, legicrfsim.c]
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2018-09-13 Correction to Samyrun offline mode
    update to Samyrun offline mode to support changes to HID ARM-side commands
    This code has not yet been tested
    [appmain.c]
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2018-09-15 rework iso14443b device functions including FPGA I/Q signal transfer (#669)
    * rework iso14443b device functions
    * hf_read_rx_xcorr.v: transfer i/q pair in one 16bit frame
    * hi_read_tx.v: invert ssp_dout. When nothing is transferred (ssp_dout=0), this results in no modulation (carrier on)
    * adjust arm sources accordingly
    * iso14443b.c: switch off carrier after hf 14b sri512read and hf 14b srix4kread
    * iso14443b.c: fix DMA circular buffer handling
    [fpgaloader.c, fpgaloader.h, iso14443a.c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]
2018-09-17 fpgaloader: fix function accordingly to #669 (#673)
    FpgaSetupSscDma uses uint16_t and not int with #669
    [fpgaloader.h]
2018-09-17 Remove unused functions le32toh, le24toh, hextobinstring, binarraytobinstring, print_hex, print_hex_break, sprint_hex_ascii, sprint_ascii, SwapEndian64ex (#667)
    * Remove unused method le32toh.
    * Delete unused function le24toh
    * Remove unused functions hextobinstring, binarraytobinstring
    * Remove unused functions print_hex, print_hex_break
    * Delete unused functions sprint_hex_ascii, sprint_ascii
    * Remove unused function SwapEndian64ex
    [util.c, util.h]
2018-09-21 RDV40 compatibility fixes (#678)
    * detect and use RDV40 higher voltage ADC channel for hw tune, hf tune, hw detectreader
    * fix mode switching in hw detectreader
    * detect Smartcard Slot in hw version
    * i2c changes from https://github.com/RfidResearchGroup/proxmark3
    * some formatting in proxmark3.h
    [appmain.c, i2c.c, iso14443a.c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]
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2018-10-07 start fixing hf 15: (#684)
    * implement a real time Decoder for tag responses (will be required for sniffing)
    * switch off field after each command (protect rdv40)
    * correctly signal field status with LED D
    [iso15693.c]
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2018-10-23 Fix hf 15 sim (#696)
    * added ISO15693 coding for tag messages (CodeIso15693AsTag())
    * added ISO15693 decoding for reader commands (Handle15693SampleFromReader())
    * send tag inventory response in either high or low speed
    * some refactoring and formatting
    [iso15693.c, util.c]
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
